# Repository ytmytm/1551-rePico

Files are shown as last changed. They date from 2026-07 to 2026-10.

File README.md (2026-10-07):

# 1551-rePico



Commodore **1551** disk-drive replacement for **Plus/4 / C16 / C116**, based on a [Raspberry Pi Pico 2](https://www.raspberrypi.com/products/raspberry-pi-pico-2/) (RP2350, **non-wireless** — raspberry logo on the soldermask; not Pico 2 W). Firmware and GCR/SD logic are derived from [1541-rePico](https://github.com/fook42/1541-rePico) / [1541-rebuild](https://github.com/ThKattanek/1541-rebuild).

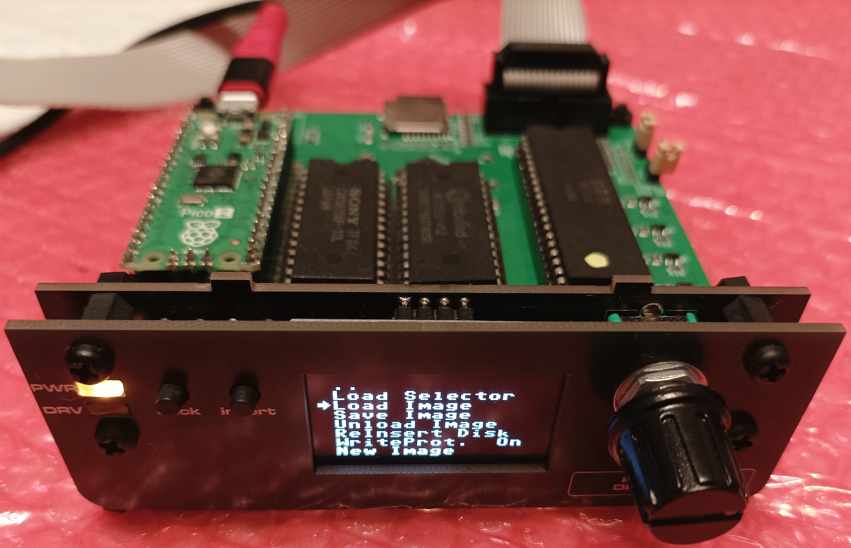
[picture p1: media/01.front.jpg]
1551-rePico front

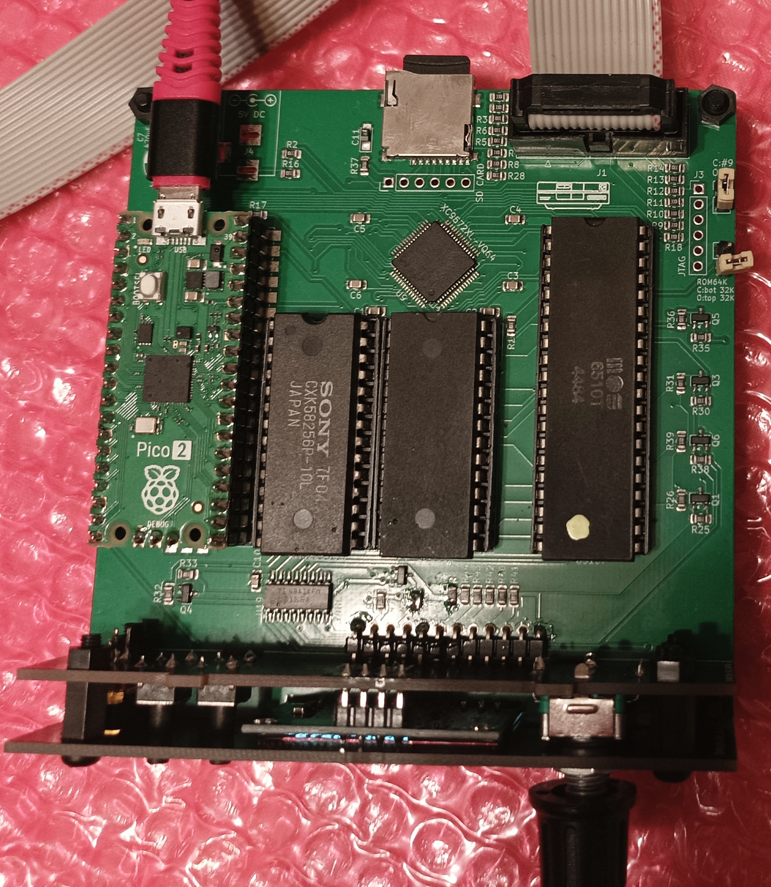
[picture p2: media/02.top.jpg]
1551-rePico top

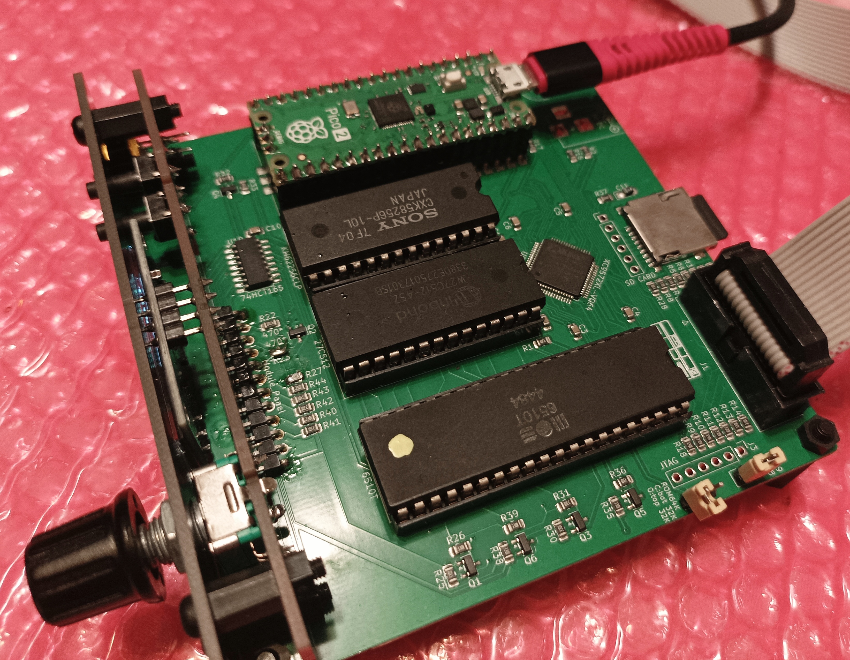
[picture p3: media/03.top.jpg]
1551-rePico topside

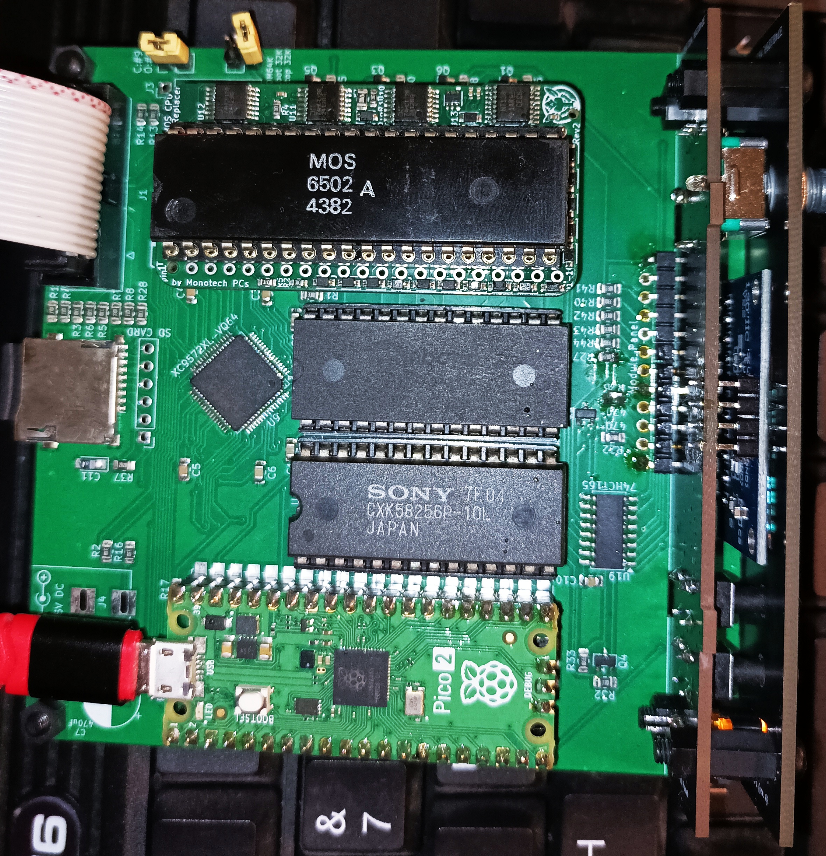
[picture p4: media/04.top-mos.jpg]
1551-rePico topside with MOS CPU Replacer


## What this is

A self-contained **drive computer** — **Pico 2** + **6510T** (or [MOS CPU Replacer](https://github.com/monotech/MOS_CPU_Replacer)) + XC9572XL CPLD + RAM + ROM — that replaces the Pi1551-III mainboard (Raspberry Pi 3 + TCBM). It reuses the Pi1551-III **mechanical stack**: front panel, top/bottom faceplates, and overall assembly. BOM, Gerbers, and build notes for those parts stay in the [Pi1551-III](https://github.com/ytmytm/Pi1551-III) repository.

The finished device connects to the computer through a ribbon cable to **[plus4-tcbm2sd](https://github.com/ytmytm/plus4-tcbm2sd)** — same as Pi1551-III.

In short: same case and front panel as Pi1551-III; this repo supplies the Pico 2 / 6510T mainboard, CPLD bitstream, DOS ROMs, and firmware.

### Repository layout

| Path | Role |
|---|---|
| `firmware-1551-III-pico/` | **Supported** firmware |
| `hardware-1551-III-Pico/` | **Supported** KiCad mainboard |
| `hdl-1551-III/` | **Supported** CPLD (`Fake6523`) |
| `roms/` | **Supported** 1551 DOS images for the 27C512 (see [`roms/README.md`](roms/README.md)) |
| `no-OS-FatFS-SD-SDIO-SPI-RPi-Pico/` | Shared FatFs/SD submodule |
| `tools/` | Optional host helper (`conv_x64` D64↔G64); see [`tools/README.md`](tools/README.md) |
| `experimental/` | **Archival only** — early plug-over-1551 daughterboard + old firmware (see [`experimental/README.md`](experimental/README.md)) |

### Compared to a stock 1551

| Stock 1551 | This board |
|---|---|
| **6510T** CPU | Same **6510T**, or a [MOS CPU Replacer](https://github.com/monotech/MOS_CPU_Replacer) in that socket |
| ~2 KB SRAM | **32 KB** SRAM (`KM62256`) with a **1551-RAMBoard-style** map: `$0000–$3FFF` + `$8000–$9FFF` (extra RAM window; decode in the CPLD) |
| ~16 KB ROM | **64 KB** EPROM (`27C512`): two **32 KB** DOS images, selected by jumper **J2** — burn a [1551-RAMBOard](https://github.com/ytmytm/1551-RAMBOard) 64K image from [`roms/`](roms/) |
| Device #8 / #9 (hardware strap) | Jumper / strap for **device 8 or 9** (same idea as stock) |
| **6523** TPI + discrete address decode | **XC9572XL CPLD** (`hdl-1551-III/` Fake6523): TPI replacement **and** RAM/ROM chip-select decode |
| 2 MHz crystal (Phi0) | **Pico 2** generates **2 MHz Phi0** (PWM) |
| ~100 Hz IRQ oscillator | **Pico 2** generates **100 Hz IRQ** (PWM) |
| Analog floppy + mech | **Pico 2** emulates the analog path and runs the UI |

### Pico 2 on this board

- **Phi0** and **IRQ** as in the table above — those clocks take dedicated GPIOs that a stock gate-array / discrete oscillator would otherwise free up
- Supplies **3.3 V** for the CPLD (and other 3.3 V rails on this board)
- Front-panel **UI**: OLED (I2C), plus rotary encoder, Back/Insert, SD card-detect, and DS0/DS1 via a **74HCT165** (same panel as Pi1551-III). The '165 is needed because after clock, IRQ, floppy bus, SPI SD, and I2C there were not enough GPIOs for every panel line directly
- **SD card**: FatFs images, browser UI, **card-detect hotplug**
- Floppy **datastream**: GCR to/from the “head”, **BYTE_READY** / related timing
- **Stepper**, optional **density** from DS0/DS1, **WPS** / disk-change toward DOS, activity LED

### CPLD role (short)

Bidirectional **ports** (TCBM on A, head data on B, handshake / MODE / DEVNUM / SYNC on C) are based on [ZXByteman/Fake6523](https://github.com/ZXByteman/Fake6523). The same chip is also **logic glue**:

- RAMBOard-style **address decode** (`/RAMSEL`, `/RAMOE`, `/ROMSEL`, TPI `/CS`), all **PHI2-qualified**
- **`XR/~W`** for SRAM `/WE` (qualified with PHI2)
- **`byte_latched`**: Pico 2 strobes `byte_ready_3v3`; the CPLD latches on the falling edge; any CPU access to the TPI window (`$4000–$7FFF`, e.g. DOS `BIT $4000`) clears the latch — the classic floppy byte-ready behaviour from 1541/1571 service docs, without a dedicated 1551 manual

## What you can do with it

- Mount **D64**, **G64**, and **PRG** images from an SD card (PRG is wrapped on the fly into a temporary D64). Format notes: [D64](doc/D64.TXT), [G64](doc/G64.TXT); optional PC conversion with [`tools/conv_x64`](tools/)
- Browse and mount images from the **OLED + encoder** front panel (Back / Insert), with **SD hotplug** when the socket has a card-detect switch
- Run as device **#8 or #9** on the Plus/4 TCBM bus via **[plus4-tcbm2sd](https://github.com/ytmytm/plus4-tcbm2sd)**
- Use **[1551-RAMBOard](https://github.com/ytmytm/1551-RAMBOard)** patched DOS in the 27C512 so track-cache / HypaRAM-style fastloaders work
- Prefer **[Parobek](https://github.com/ytmytm/plus4-parobek)** as the host utility ROM: it autodetects the RAMBOard DOS patch and provides a fastloader. For now we use Parobek’s **DirectoryBrowser** on the computer; `firmware-1551-III-pico/SoftwareC16/db12b.prg` is kept for a future on-device Load Selector (**TODO**)

## Build and assemble

### 1. Clone (with submodules)

The FatFs/SD driver is a **git submodule**. Without it, CMake will fail.

```bash
git clone --recurse-submodules https://github.com/ytmytm/1551-rePico.git
cd 1551-rePico
```

If you already cloned without submodules:

```bash
git submodule update --init --recursive
```

You need at least `no-OS-FatFS-SD-SDIO-SPI-RPi-Pico/` for the supported firmware.

### 2. Host packages

**Linux (Debian-like):**

```bash
sudo apt install cmake ninja-build libusb-1.0-0-dev build-essential \
  pkg-config python3 xxd gcc-arm-none-eabi \
  libnewlib-arm-none-eabi libstdc++-arm-none-eabi-newlib
```

**macOS (Homebrew):**

```bash
brew install cmake ninja libusb pkg-config python3
brew install --cask gcc-arm-embedded
```

`xxd` is usually already on macOS (Xcode Command Line Tools). Ensure `arm-none-eabi-gcc` is on your `PATH`.

### 3. Raspberry Pi Pico SDK

From [pico-sdk](https://github.com/raspberrypi/pico-sdk):

```bash
git clone https://github.com/raspberrypi/pico-sdk.git
cd pico-sdk
git submodule update --init lib/mbedtls
export PICO_SDK_PATH="$(pwd)"
echo "export PICO_SDK_PATH=$PICO_SDK_PATH" >> ~/.profile
```

Open a new shell (or `source ~/.profile`) so `PICO_SDK_PATH` is set. The Raspberry Pi Pico VS Code extension / `.pico-sdk` can provide the SDK instead.

### 4. picotool

From [picotool](https://github.com/raspberrypi/picotool): clone and build/install as in its README / BUILDING.md so `picotool` is on your `PATH`.

### 5. Compile firmware

```bash
cd firmware-1551-III-pico
mkdir -p build && cd build
cmake -G Ninja -DCMAKE_BUILD_TYPE=Release ..
ninja
```

Outputs include `1551-III-Pico.uf2` and `1551-III-Pico.elf`.

### 6. Flash the Pico 2

```bash
picotool load -t uf2 1551-III-Pico.uf2 -x -f
```

`-f` forces BOOTSEL when the app is running; `-x` starts the new firmware after load.

### 7. Main PCB (order / solder)

KiCad project: [`hardware-1551-III-Pico/`](hardware-1551-III-Pico/) (see its [`README.md`](hardware-1551-III-Pico/README.md)).

- Schematic PDF: [`plots/1551-III-Pico.pdf`](hardware-1551-III-Pico/plots/1551-III-Pico.pdf)
- Gerbers / drills: [`plots/`](hardware-1551-III-Pico/plots/)
- Fab pack: [`production/1551-III_Pico_2b.zip`](hardware-1551-III-Pico/production/1551-III_Pico_2b.zip)
- BOM / pick-and-place: [`production/bom.csv`](hardware-1551-III-Pico/production/bom.csv), [`positions.csv`](hardware-1551-III-Pico/production/positions.csv), [`designators.csv`](hardware-1551-III-Pico/production/designators.csv)
- **JP1–JP3**: leave default **1–2** (Pico 2 ↔ `74HCT165`). Alternate wiring was only insurance if the shift register failed — do not change them.

### 8. Program the CPLD

Flash [`hdl-1551-III/Fake6523.jed`](hdl-1551-III/Fake6523.jed) into the XC9572XL. The `.jed` was built with [Xilinx ISE 14.7](https://www.xilinx.com/support/download/index.html/content/xilinx/en/downloadNav/vivado-design-tools/archive-ise.html) (sources in `hdl-1551-III/`). Rebuild and JTAG steps (a Raspberry Pi 3 and jumper wires are enough) are in [plus4-tcbm2sd → CPLD firmware](https://github.com/ytmytm/plus4-tcbm2sd/blob/main/HardwareFirmware.md#cpld-firmware); the procedure is the same for this board.

### 9. Burn the DOS ROM

Program a 64K image from [`roms/`](roms/) into the 27C512 (see [`roms/README.md`](roms/README.md)). Prefer a [1551-RAMBOard](https://github.com/ytmytm/1551-RAMBOard) image; jumper **J2** selects the active 32K half (use the patched upper bank).

### 10. Panel, case, and host link

- Front panel / faceplates / mechanical assembly: **[Pi1551-III](https://github.com/ytmytm/Pi1551-III)**
- Host: **[plus4-tcbm2sd](https://github.com/ytmytm/plus4-tcbm2sd)** + ribbon cable

## History and relation to 1541-rePico

This is a **separate product**, not a fork kept in sync with upstream 1541-rePico: a real **6510T** + CPLD 1551 path in a [Pi1551-III](https://github.com/ytmytm/Pi1551-III) enclosure. Useful upstream changes may still be cherry-picked by hand.

**Starting point.** Take 1541-rePico’s GCR/SD/UI core and aim at a **1551** for Plus/4 that still fits **Pi1551-III** and talks through **tcbm2sd**, so the Pi 3 Module-rotated board becomes a Pico 2 + real 6510T path.

**Daughterboard bring-up** (now `experimental/`). First hardware plugged over a stock 1551 mainboard: reuse CPU/TPI/RAM/ROM, Pico 2 for the analog path, Fake6523 in the CPLD. That proved TCBM/GCR, pin maps, and design rules: Phi0 and 100 Hz IRQ from the Pico 2 (gate array optional), `XR/~W` in the CPLD, PHI2-qualified chip-selects (otherwise RAM bus contention), `byte_latched` as classic byte-ready, and slower zone-0 timing than 1541 defaults. Once the motherboard was only a RAM/ROM carrier, a self-contained board was the next step.

**1551-III-Pico.** Decode moved into the CPLD (no discrete `'139`/`'00`), RAMBOard map and 64K DOS images, Pi1551-III panel (SH1106 + 74HCT165). Firmware lives in `firmware-1551-III-pico/`. Upstream 1541-rePico is not merged as a whole — only occasional hand cherry-picks.

| Mostly from 1541-rePico | Mostly new for 1551 / this board |
|---|---|
| GCR encode/decode, track buffers, D64/G64 path | KiCad III board, CPLD glue + Fake6523 ports, RAMBOard decode |
| FatFs / SD wiring, much of the menu framework | Pico 2 as Phi0 + 100 Hz IRQ; '165 panel inputs |
| Build/flash with pico-sdk / picotool | TCBM via tcbm2sd; Parobek + patched DOS ROMs |
| | Zone-0 timing, byte-ready latch model, SD hotplug, III pinout |

### Credits

- [1541-rebuild](https://github.com/ThKattanek/1541-rebuild) — Thorsten Kattanek  
- [1541-rePico](https://github.com/fook42/1541-rePico) — fook42 (GCR/SD/UI lineage)  
- C64 image selector in upstream 1541-rePico — Peiselulli  
- Dev-container / debug docs on upstream — [BensonRSI](https://github.com/BensonRSI)  
- [Fake6523](https://github.com/ZXByteman/Fake6523) — ZXByteman / go4retro  
- [Pi1551-III](https://github.com/ytmytm/Pi1551-III), [plus4-tcbm2sd](https://github.com/ytmytm/plus4-tcbm2sd), [1551-RAMBOard](https://github.com/ytmytm/1551-RAMBOard), [plus4-parobek](https://github.com/ytmytm/plus4-parobek)

## Links

- Disk image formats overview: <https://ist.uwaterloo.ca/~schepers/formats.html>
- forum64 thread behind 1541-rebuild / 1541-rePico: <https://www.forum64.de/index.php?thread/59884-laufwerk-der-1541-emulieren>

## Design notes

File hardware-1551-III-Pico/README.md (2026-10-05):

# 1551-III-Pico mainboard

KiCad project for the **horizontal main module** of [1551-rePico](../README.md): Pico2 + 6510T (or [MOS CPU Replacer](https://github.com/monotech/MOS_CPU_Replacer)) + XC9572XL CPLD + 32 KB SRAM + 64 KB EPROM. It replaces the Pi1551-III **Module-rotated** board and mates with the [Pi1551-III](https://github.com/ytmytm/Pi1551-III) front panel and faceplates.

Host connection is a ribbon cable to **[plus4-tcbm2sd](https://github.com/ytmytm/plus4-tcbm2sd)** (same as Pi1551-III).

## Design files

| Artifact | Path |
|---|---|
| KiCad project | this folder (`1551-III-Pico.kicad_pro`) |
| Schematic PDF | [`plots/1551-III-Pico.pdf`](plots/1551-III-Pico.pdf) |
| Gerbers / drills | [`plots/`](plots/) |
| JLCPCB-style fab pack | [`production/1551-III_Pico_2b.zip`](production/1551-III_Pico_2b.zip) |
| BOM / positions | [`production/bom.csv`](production/bom.csv), [`production/positions.csv`](production/positions.csv), [`production/designators.csv`](production/designators.csv) |

## Related firmware / CPLD / ROMs

- Firmware: [`../firmware-1551-III-pico/`](../firmware-1551-III-pico/)
- CPLD bitstream: [`../hdl-1551-III/Fake6523.jed`](../hdl-1551-III/Fake6523.jed) — flash notes in the [top-level README](../README.md#8-program-the-cpld)
- DOS EPROM images (27C512): [`../roms/`](../roms/) — see [1551-RAMBOard](https://github.com/ytmytm/1551-RAMBOard) for provenance and patch details
- Mechanical / panel BOM: **[Pi1551-III](https://github.com/ytmytm/Pi1551-III)**

## Notes

- Internal bring-up / review notes: [`notes.txt`](notes.txt), [`hardware-review.md`](hardware-review.md)
- ROM bank select on this board is jumper **J2** (two 32 KB halves of the 27C512). Prefer a [1551-RAMBOard](https://github.com/ytmytm/1551-RAMBOard) 64K image so the upper half is the RAM-expansion / fastloader patch.
- **JP1–JP3** (GPIO26–28 ↔ `74HCT165`): leave as shipped / default **1–2**. They were only a fallback so the Pico could talk to the front-panel encoder directly if the shift register failed; '165 works and current firmware expects that path — do not rewire them.

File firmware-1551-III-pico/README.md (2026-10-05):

# firmware-1551-III-pico

**Supported** firmware for the 1551-III-Pico board (Pico2 + front panel + SD + GCR).

Build, flash, and product overview: see the [top-level README](../README.md#build-and-assemble).

Host-side Load Selector / Parobek notes: [What you can do with it](../README.md#what-you-can-do-with-it). Plus/4 browser binary kept here: `SoftwareC16/db12b.prg`.

Archival 1541 / early daughterboard firmware is under [`../experimental/firmware/`](../experimental/firmware/), not this tree.

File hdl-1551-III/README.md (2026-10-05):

# hdl-1551-III

Xilinx ISE project and bitstream for the **XC9572XL** on the 1551-III-Pico board (`Fake6523.jed`).

What the CPLD does (TPI ports, RAM/ROM decode, `byte_latched`): [CPLD role](../README.md#cpld-role-short). How to rebuild and JTAG-flash: [Program the CPLD](../README.md#8-program-the-cpld).

Sources are based on [ZXByteman/Fake6523](https://github.com/ZXByteman/Fake6523). The older daughterboard CPLD tree is under [`../experimental/hdl/`](../experimental/hdl/).

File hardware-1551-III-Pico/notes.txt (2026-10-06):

Mini-Din-7 https://forum.kicad.info/t/mini-din-connectors-their-footprints-and-3-d-models-asking-for-discussion-and-a-bit-of-help-discussion/58247/11

6502 computers:
https://wilsonminesco.com/6502primer/potpourri.html

https://coronax.wordpress.com/2024/01/24/adding-io-ports-to-a-6502-computer-using-7400-series-ics/

https://github.com/maarten-pennings/6502/tree/master/1clock

RAM /WE is always R/W combined with Phi2

https://github.com/maarten-pennings/6502/blob/master/4ram/README.md

https://www.grappendorf.net/projects/6502-home-computer/

Something completely different:
https://eaw.app/pico6502/

[20260714]
Put together daughterboard, but no success yet.
The CPU might be running or might be faulty, not sure yet.
Some lines display expected pattern, so it might be ok.
But there is no response to TCBM.
We don't even know if the port is accessible to CPU.
Should we use R/W + Phi2 instead of XR/W+Phi0? We don't know.
We might test it with repico using debug firmware and debug ROM, but it will have to wait.
Pico generates 2MHz on GPIO0 and 100Hz with 10us low on GPIO3, same as onboard circuit, that should be fine (unless we use inverting buffer).
- uncomment /* #define REPICO1551_GPIO3_IRQ_PWM */ in include/board1551.h to enble PWM back

Flash firmware (switches ot bootsel on its own):
picotool load "/Users/apple/Documents/Batibat/Maciejdev/plus4/pico1551/1551-rePico/firmware-1551-III-pico/build/1551-III-Pico.uf2" -f

Next steps:
- if CPU can't write to TPI ports we can check if using phi2+r/w would help here
    (in fact we can start with it? could be faster check than custom ROM)
    - maybe it should just write 0 and use hi-z instead of 1?
- we don't use WPS (write protect) as input, nor ACT (LED) as output on 1551-III
  daughterboard alone — but on the main 1551 board ACT LED and WPS are available

[20260715]
Did some checks with custom ROMs to conclude:
- CPU most likely works fine
- CPU port state unknown (no conclusive tests)
- TCBM port works, we can read/write data from 1551 coming to computer
- TCBM port is not reliable, seems that DDR writes sometimes fail
    - wrong value is stored, so some bits remain in wrong direction leading to stuck bits
- SRAM seems to be bad
    - that explains weird IRQ behavior and failure of CPU ports (RAM was used to hold state)

Next steps:
- desolder SRAM
- solder 24pin socket
- put a replacement:
    - after https://github.com/ytmytm/c128-bytewide-color-ram-1571cr-expansion
      I have 2 2K SRAM chips

[20260716]
Everything works. Debug ROM / REPICO_DEBUG bring-up target removed.
SRAM didn't have to be removed - just reseating CPU was enough.
Locked CPU/TPI pins positions, they were perfectly aligned.

[20260717]
- improved rotary encoder
- disconnected BYTE_LATCHED from mainboard
- optimizations to speed up main loop (drop sleep_us(3) BYTE_READY on 1551;
  set PA direction only on SO mode change)

[20260718]
- problems with zone 0 (tracks 1-17) seem to be solved (hopefully we don't break anything else)
  - timer set to 28µs and gap 21 instead of 26/12
  Doc: doc/1551-zone0-gcr-timing.md
- UI / UIX improvements
- options in settings to control zone0 (Z0) timer/gap for experiments
- reversible encoder direction
- confirmed that IRQ 100Hz/10µs from GPIO3 PWM works fine
- no need for reset circuit for 1551-III-Pico, it's driven by tcbm2sd
- LED connected, P5 pins 8 (+5V) and 9 (ACT), activity when loading, not during reset
- drop use of gate array's XR/W, generate it on (former RESET_3V3 pin) in CPLD, expose for RAM
- confirmed that RAM works on /WE generated from CPLD (from former RESET_3V3 pin)
- switched Phi0 to come from Pico and that blew up(?) GA? there is no onboard 2MHz anymore
  (or it could be unfortunate conincidence - Pico didn't want to start several times, maybe something shorted and blew GA?)
  (U7 GA is probably broken, no 2MHz clock, we don't need it though)
- desoldered U7 GA and connected like below to 74'139
- 1551 motherboard used only as carrier for RAM and ROM
- pico1551 can be recreated
- AI claims that if we switch in CPLD rs (address) from register to input
  we might save just enough gates to generate RAM/ROM/TPI chip-select signals
  *also* with 1551-RAMBOard setup ($00-$3f RAM, $40-$7F TPI, $80-$9F RAM, $A0-$FF ROM)
  need A13-A15 on input and /RAMSEL, /ROMSEL on output

remove U7 and wire 74'139
U7      '139    signal
4       16      VCC, also to 15,14,13
        15      /E2 (keep input high)
6       3       A15
7       2       A14
20      4       /RAM
14      7       /ROM
16      5       /TPI
5       1       /E1, GND also to 8
        8       GND
        13      VCC (keep input high)
        14      VCC (keep input high)

or directly:

74LS139 (DIP-16)
================

 pin | signal   | connect
-----+----------+----------------
  1  | 1G (/E1) | GND
  2  | 1A       | CPU A14   (21)
  3  | 1B       | CPU A15   (22)
  4  | 1Y0      | /CS_RAM   (18+20 shorted)
  5  | 1Y1      | /CS_TPI   (18)
  6  | 1Y2      | NC
  7  | 1Y3      | /CS_ROM   (22, 20 tied to GND)
  8  | GND      | GND
  9  | 2Y0      | NC
 10  | 2Y1      | NC
 11  | 2Y2      | NC
 12  | 2Y3      | NC
 13  | 2A       | VCC
 14  | 2B       | VCC
 15  | 2G (/E2) | VCC
 16  | VCC      | VCC

Pico1551-III readiness:
confirm that UI would work with Pi1551-III front panel connected
    - act will be inverted (active low)
    - need correct OLED type driver

[2026-08-23]
Soldered Pico1551-III prototype. It doesn't work (would be surprised if it does).
There is some kind of RAM problem - with RAM chip inserted there seems to be bus
contention. Without RAM we get blinking activity LED.
Almost forgot that ROM needs to be 2*32K images coming from 1551-RAMBOard.
Spent whole evening chasing the problem. The solution turned out to be to qualify
all chip select signals with Phi2.

So the next step is confirm again that it works and then we can test shift register
with the front panel.

[2026-08-24]
It works, so I have mounted the front panel.
Agent implemented SH1106 OLED support (it was SSD1306) and shift register handler.
Density chosen by CPU (via DS0/DS0 lines) is an option, currently off - track density hardcoded by track number.
'Back' button is universal back and 'Insert' goes to load image menu and adds disk images to the roster.

Needs testing + decision what to do with SD switch info - some kind of reload?

[2026-08-31]
Experimental firmware branch feature/core-split-ui-gcr: UI + 74HCT165 input on core 1,
GCR byte feed + stepper/floppy GPIO on core 0. Inter-core lock-free SPSC mailboxes
(ipc.h/ipc.c) for timer, WPS, disk change, and shift165 density byte — aims to
reduce GCR jitter vs single-core main loop. Not merged; flash from that branch to test.

Added WPS triggering on disk change, but GEOS doesn't recognize that 1B is different than
1A or 2A. Only Close+Open in Desktop refreshes that. Strange.

Removed zone0 settings, we don't need it anymore. Brought back values from 1541 upstream.

[2026-09-01]
Tested on stock Plus/4. Demos (biffire: Carrion 121, qm_prepl; hypaload: vdc, carrion)
do work without issues - it's all about 6502/Plus4 faulty Hannes and 65C02 there.
No need to go back to 1551 mainboard.

Can be published and released.

[2026-09-12]
Confirmed dim ACT LED fix for the 1.0 board:
- remove R27 (3.3K)
- move R23 to R27 footprint (470R)
- short R23 pads (0R)

Applied in KiCad, regenerated files for v1.1 (revison 2b on SCH/PCB).

[2026-10-02]
Confirmed that it works with MOS CPU Replacer configured for 6510T both electrically
and mechanically.
https://github.com/monotech/MOS_CPU_Replacer

[2026-10-03]
Added support for SD card switch and hot swapping SD cards.
Preparations for publishing, repository cleanup.

[2026-10-05]
Added some photos, also to the experimental folder.

TODO:
- disk image is not saved automatically
- when disk is saved it doesn't replace the original one
- UI is somewhat inconsistent (longpress not needed with front planel)
  but with menus still better than Pi1551
- 16x8 is plenty of space, most of it unused outside menu
- still don't understand why disk switch from GEOS's disks
  1A->1B or 2A->1B are not recognized by 1A->2A is
- README needs user's manual - encoder actions (longpress too)
  insert/back buttons as well

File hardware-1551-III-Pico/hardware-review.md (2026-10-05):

# Review hardware-1551-III-Pico

Data review: 2026-08-13

Zakres: tylko projekt `hardware-1551-III-Pico`, z porownaniem do `hdl-1551-III/Fake6523.v`, `hdl-1551-III/Fake6523.ucf`, `hdl-1551-III/Fake6523.rpt`, `hardware-1551-III-Pico/notes.txt` i `doc/1551-rom-ram-ramboard-decode.txt`.

## Wniosek ogolny

Schemat po przeniesieniu dekodera adresu do CPLD wyglada spojnie. `U12 74LS139` i `U15 74LS00` zostaly usuniete, stare nety dekodera nie wystepuja juz w schemacie ani PCB, a nety KiCada zgadzaja sie z pinoutem HDL/UCF.

Nie widze blokera logicznego, ktory jednoznacznie zatrzymywalby testowa produkcje plytki. Do zamkniecia przed wyslaniem zostaje jedna rzecz produkcyjna: pola BOM/JLC dla `U19`, bo schemat chce `74HCT165`, a pola produkcyjne nadal wskazuja wariant LS.

Fit `hdl-1551-III` przeszedl dla wariantu z osobnym `/RAMOE`, ale CPLD jest wypelniony do konca:

```text
Macrocells:     72/72  (100%)
Product Terms: 206/360 (57%)
FB inputs:     136/216 (63%)
Registers:      58/72  (81%)
Pins:           47/52  (90%)
```

Nie dokladac juz logiki do XC9572XL w tej rewizji bez swiadomego usuwania czegos innego.

Ostrzezenia fittera sa znane i nie wygladaja na nowy problem po dodaniu dekodera: dotycza inferowanych/zignorowanych `BUFG` na pinach `port_a<5..7>` oraz sciezki projektu ISE. Nie ma bledow fitowania.

## Dekoder W CPLD

Aktualne znaczenie sygnalow:

```text
/RAMSEL = RAM /CS, zalezy tylko od adresu
/RAMOE  = RAM /OE, aktywne tylko gdy RAM jest wybrany i CPU czyta
XR/~W   = ogolny /WE, aktywne przy R/W=0 i PHI2=1
/ROMSEL = ROM /CE i /OE, zalezy tylko od adresu ROM
```

Rownania po fitterze:

```text
/RAMSEL = A14 OR (A15 AND A13)
/RAMOE  = NOT ((NOT A14 AND NOT A15 AND R/W) OR (NOT A14 AND NOT A13 AND R/W))
/ROMSEL = NOT A15 OR (NOT A14 AND NOT A13)
TPI /CS wewnetrznie = NOT (A14 AND NOT A15)
```

Mapa adresow:

```text
$0000-$3fff = RAM
$4000-$7fff = TPI
$8000-$9fff = dodatkowy RAM
$a000-$ffff = ROM
```

## Weryfikacja Netow KiCad

Sprawdzone w `1551-III-Pico.kicad_sch` i `1551-III-Pico.kicad_pcb`:

```text
U9 P39 = A14
U9 P42 = /RAMOE
U9 P58 = /RAMSEL
U9 P59 = /ROMSEL
U9 P61 = A13
U9 P62 = A15
U4 pin 20 /CS = /RAMSEL
U4 pin 22 /OE = /RAMOE
U4 pin 27 /WE = XR/~W
U5 pin 20 /CE = /ROMSEL
U5 pin 22 /OE = /ROMSEL
U6 CPU A13/A14/A15 sa na tych samych netach A13/A14/A15
```

Nie znaleziono juz w schemacie ani PCB: `U12`, `U15`, `74LS139`, `74LS00`, `~{CS_TPI}`, `~{RAM_LOW}`, `~{RAM_HIGH}`, `~{ROM_LOW}`, `~{ROM_HIGH}`, `~{E2}`.

Dodany test/symulator:

```text
python3 hardware-1551-III-Pico/test_hardware_model.py
```

Test sprawdza model dekodera adresu dla calego zakresu `$0000-$ffff`, brak konfliktu driverow na magistrali danych przy odczycie, kwalifikowanie `/RAMOE` i `XR/~W`, kolejnosc bitow z `U19 74HCT165`, krytyczne piny KiCada kontra HDL/UCF oraz wybrane pullupy/wejscia stale.

## Audyt CPU/RAM/ROM

CPU `U6 6510T`: adresy, dane, `R/W`, `PHI0`, `PHI2`, `/RESET`, `/IRQ`, `/AEC` i portowe linie 1551 sa podlaczone; `/RESET`, `/IRQ` i `/AEC` maja pullupy.

SRAM `U4 KM62256CLP`: adresowanie jest zgodne z planem RAMBoard:

```text
RAM A0..A13 = CPU A0..A13
RAM A14     = CPU A15
RAM D0..D7  = CPU D0..D7
```

Sterowanie SRAM:

```text
pin 20 /CS = /RAMSEL
pin 22 /OE = /RAMOE
pin 27 /WE = XR/~W
```

EPROM `U5 27C512`: adresy i dane sa kompletne, `ROM A15` jest ustawiany przez `J2 + R1 3.3K do +5V`, a `/CE` i `/OE` ida na `/ROMSEL`. Nie widze wiszacych wejsc przy RAM/ROM.

## Audyt CPLD/TPI/TCBM

`U9 XC9572XL` jest zasilany z `+3V3`, ma podlaczone wszystkie piny z UCF i poprawnie wykorzystuje `~{RESET}` jako GSR. Niepodlaczone piny CPLD `P8`, `P18`, `P23`, `P51` sa oznaczone jako no-connect i fitter pokazuje je jako `TIE`, wiec nie wygladaja jak przypadkowo wiszace uzywane wejscia.

Linie TCBM `DIO1..DIO8`, `STATUS0`, `STATUS1`, `DEV`, `DAV`, `ACK` ida do CPLD zgodnie z UCF. Pullupy TCBM ida do `+3V3`, co pasuje do pracy CPLD na 3.3 V i do jego 5 V tolerant wejsc.

Warto pamietac, ze `byte_latched` jest generowane z asynchronicznego `byte_ready_3v3` i wewnetrznego `/CS`; to jest istniejacy model z eksperymentu. Nie znalazlem tu nowego bledu schematowego, ale to pozostaje punkt bring-up firmware/HDL, nie ERC.

## Audyt Pico I Shift Register

`U3 Pico` ma `VSYS` podlaczone do `+5V`, `3V3` zasila logike 3.3 V, a `VBUS`, `RUN`, `3V3_EN`, `ADC_VREF`, `SWCLK`, `SWDIO` sa swiadomie no-connect. To jest akceptowalne dla modulu uruchamianego przez USB/BOOTSEL i bez osobnego debug SWD na plytce.

`U19 74HCT165`: `/PL = SERIAL_LOAD`, `CP = SERIAL_CLK`, `Q7 = SERIAL_DT`, `DS = GND`, `/CE = GND`, `VCC = +5V`, `GND = GND`, a `/Q7` jest no-connect. Wejscia panelowe i SD-card-detect maja pullupy do `+3V3`; `DS0/DS1` sa czytane z portu CPU i nie wymagaja tu osobnych pullupow jesli CPU je aktywnie steruje.

Uwaga produkcyjna: symbol/wartosc mowi `74HCT165`, ale pola JLC/MFR w schemacie i PCB nadal wskazuja `SN74LS165ADR(LX)` / `C42403065`. Jesli faktycznie ma byc HCT, trzeba poprawic pola BOM/JLC przed assembly. Jesli swiadomie dopuszczasz LS, dopisz to w BOM, bo obecna notatka na schemacie mowi, ze "musi byc HCT".

## Zasilanie I Montaz

`+5V` zasila CPU/RAM/ROM/U19 i `VSYS` Pico, `+3V3` zasila CPLD, pullupy 3.3 V i peryferia Pico. Kondensatory 100 nF sa przy glownych ukladach (`C1..C6`, `C10`), a przy SD jest dodatkowy `C11 10u`. Nie robilem analizy impedancji ani rozmieszczenia przy pinach zasilania, tylko sprawdzenie netlisty.

`README.md` w katalogu projektu opisuje juz rewizje Pico (KiCad / plots / production / ROM); nie jest juz starym tekstem Pi1551-III Module-rotated.

`JP1..JP3` (solder jumpers GPIO26..28): domyslnie mostkowane **1–2** do `74HCT165` (`/PL`, `CP`, `Q7`). Alternatywna sciezka na schemacie (bezposrednio do enkodera) byla tylko ubezpieczeniem na wypadek problemow z '165; shift register dziala, firmware zaklada tryb 1–2 — **zostawic JP1–JP3 bez zmian**.

## Otwarte

- [x] Nałozyc overlay warstwy Edge.Cuts z MOSReplacer - miec pewnosc ze sie zmiesci nad footprint 6510T
      potrzeba 6.5mm z lewej i 10.54mm z prawej (moze byc nad ROM/RAM, ale nie nad RPIco)
- [x] Porownac z tcbm2sd jak daleko poza krawedz wystaje gniazdo SD card
- [x] Uruchomic ERC/DRC w KiCadzie lokalnie; `kicad-cli` nie jest dostepny w tym srodowisku.
- [x] Sprawdzic pola BOM/JLC dla `U19`: HCT zgodnie ze schematem/notatka albo swiadomie LS i opisane w BOM. Aktualnie nadal `SN74LS165ADR(LX)` / `C42403065`. (LS/HCT bez roznicy)
- [x] Przejrzec wygenerowany BOM/position files po ostatnich zmianach, szczegolnie usuniecie `U12/U15` i dodanie netow CPLD `/RAMSEL`, `/RAMOE`, `/ROMSEL`.
- [x] Dodac i uruchomic test/symulator `hardware-1551-III-Pico/test_hardware_model.py`.
- [x] Dopisac w firmware obsluge `74HCT165`.
- [x] Opisac `JP1..JP3`: default 1–2 do '165; fallback na enkoder tylko jako ubezpieczenie — nie ruszac (README projektu KiCad).
- [x] Uaktualnic `hardware-1551-III-Pico/README.md` dla tej rewizji (BOM/plots/production + notka JP1–JP3).

[2026-08-31]
Too dim ACT LED:
- remove R27 (3.3K)
- move R23 to R27 footprint (470R)
- short R23 pads (0R)
Should be much brighter, comparable to PWR

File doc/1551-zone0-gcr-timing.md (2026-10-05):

# 1551-rePico: zone 0 GCR timing (tracks 1–17)

**Status:** confirmed 2026-07-18 — keep both tweaks for `REPICO1551` builds.  
**Code:** `firmware-1551-III-pico/src/globals.c` (`bytetimer_values`, `d64_sector_gap`), gated on `#if REPICO1551` (same values live in the archival `experimental/firmware/` tree).

## Summary

Stock 1551 DOS (and some fastloaders) failed on densest tracks (speed zone 0, tracks 1–17) with the original 1541-rePico packing: **26 µs/byte** and **12** GCR gap bytes between sectors. Typical symptom: `23, READ ERROR, track, sector` (data-block checksum) while the directory on track 18 (zone 1) still worked.

**Keep for 1551:** zone 0 at **28 µs/byte** and sector gap **21** (same as zone 1).  
**1541 builds** stay at the original **26 µs / gap 12** until proven otherwise.

Offline D64→GCR encode/decode of failing sectors was correct; the issue is live capture timing (header → short gap → data), not corrupt image bytes.

## A/B results (REPICO1551)

| Config | Zone 0 timer | Zone 0 gap | Result |
|---|---|---|---|
| Original | 26 µs | 12 | `LOAD "GEOS 3*"` → `23, READ ERROR, 11,17`; Carrion fastloader on tracks 1–8 still OK |
| Gap only | 26 µs | 21 | First GEOS load OK; later GEOS stages failed |
| Timer only | 28 µs | 12 | GEOS OK; **hypaload** and **qm_…** demos failed |
| **Both (keep)** | **28 µs** | **21** | Reliable — GEOS, hypaload, qm_ demos all pass |

Also useful contrast: Carrion starts on track 18 then fastloads zone 0 successfully with original timing — fastloaders can tolerate packing that stock DOS rejects.

## Emulation tradeoff

Zone 0 no longer matches a real drive’s fastest density band:

- Byte period matches zone 1 (28 µs).
- Inter-sector gaps match zone 1 (21 × `0x55`).
- Revolution time on tracks 1–17 is slightly longer than ~200 ms real (~220 ms with both tweaks).

GCR payload and checksums remain correct. Risk is mainly timing-sensitive protections or loaders that assume authentic zone-0 bitrate/RPM; none of the titles above required reverting.

## Related ISR notes (1551)

Separate from gap/timer, also done for 1551 bring-up:

- No `sleep_us(3)` on `BYTE_READY` pulse (CPLD latches on falling edge).
- PA bus direction set only on SO read/write mode change, not every byte.

See `hardware-1551-III-Pico/notes.txt` for session log.

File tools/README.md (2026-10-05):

# conv_x64

Small host tool to convert between D64 and G64 image formats (round-trip through the same GCR structures the firmware uses).

## Main purpose

Originally for testing read/write paths in [1541-rePico](https://github.com/fook42/1541-rePico). Still useful here for checking D64/G64 images before putting them on an SD card for **1551-III-Pico** — the GCR layer is shared.

The supported product firmware lives in `../firmware-1551-III-pico/`; this tool is optional and not required to build or flash the drive.

## Usage

```text
conv_x64 <file_in> <file_out>
```

Extension of `file_in` (`.d64` or `.g64`) selects the reader; extension of `file_out` selects the writer.

## How to build

```bash
gcc -fcommon -o conv_x64 conv_x64.c gcr.c rw_tracks.c
```

Ignore the type-conversion warnings.

2026/02/14 - fook42

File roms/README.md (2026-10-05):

# 1551 DOS ROM images

Burn a **64 KB** image into the board’s **27C512 / 27E512** (socket U5). Jumper **J2** selects which 32 KB half is mapped.

These files are the same deliverables documented by **[1551-RAMBOard](https://github.com/ytmytm/1551-RAMBOard)** (RAM/ROM expansion map used on this board: `$0000–$3FFF` + `$8000–$9FFF` RAM, `$A000–$FFFF` ROM). Prefer the patched upper bank together with **[Parobek](https://github.com/ytmytm/plus4-parobek)** for the HypaRAM / track-cache fastloader.

## What to program (recommended)

| File | Size | Use |
|---|---|-----|
| [`1551.318008-01-64k.bin`](1551.318008-01-64k.bin) | 64K | Stock 1551 DOS (318008-01): lower half = unpatched base, upper half = RAMBOard patch |
| [`super_dos_1551-64k.bin`](super_dos_1551-64k.bin) | 64K | SuperDOS (40-track) + same RAMBOard patch in the upper half |

Leave **J2** so the **upper** (patched) half is selected for normal use. Details: [1551-RAMBOard README](https://github.com/ytmytm/1551-RAMBOard).

## 32K / 16K copies (same payloads, shorter names)

Copied from a Pi1551 SD card tree; byte-identical to the RAMBOard outputs under the names used there:

| File | Size | Same as |
|---|---|---|
| [`dos1551-ram.bin`](dos1551-ram.bin) | 32K | `1551.318008-01-patched.bin` (upper half of the 64K stock image) |
| [`1551.318008-01-patched.bin`](1551.318008-01-patched.bin) | 32K | RAMBOard patched stock DOS |
| [`super_dos_ram.bin`](super_dos_ram.bin) | 32K | `super_dos_1551-patched.bin` |
| [`super_dos_1551-patched.bin`](super_dos_1551-patched.bin) | 32K | RAMBOard patched SuperDOS |
| [`dos1551.bin`](dos1551.bin) | 16K | Stock 1551 DOS base ([zimmers.net 318008-01](https://www.zimmers.net/anonftp/pub/cbm/firmware/drives/new/1551/1551.318008-01.bin)) |
| [`super_dos_1551.rom`](super_dos_1551.rom) | 16K | SuperDOS 1551 ([plus4world](https://plus4world.powweb.com/dl/utils/s/super_dos_1551.rom)) |

## Provenance

- Patch / 64K packing / build steps: [ytmytm/1551-RAMBOard](https://github.com/ytmytm/1551-RAMBOard)
- Stock 1551 ROM: Commodore 318008-01 (via zimmers.net, as linked from RAMBOard)
- SuperDOS: plus4world `super_dos_1551.rom` (as linked from RAMBOard)
- Local copies of the shorter names came from a Pi1551 `sdcard/` tree; the `*-64k.bin` / `*-patched.bin` files match the RAMBOard First Bank build outputs

Rebuild yourself with the RAMBOard `Makefile` / Releases if you need a fresh binary.

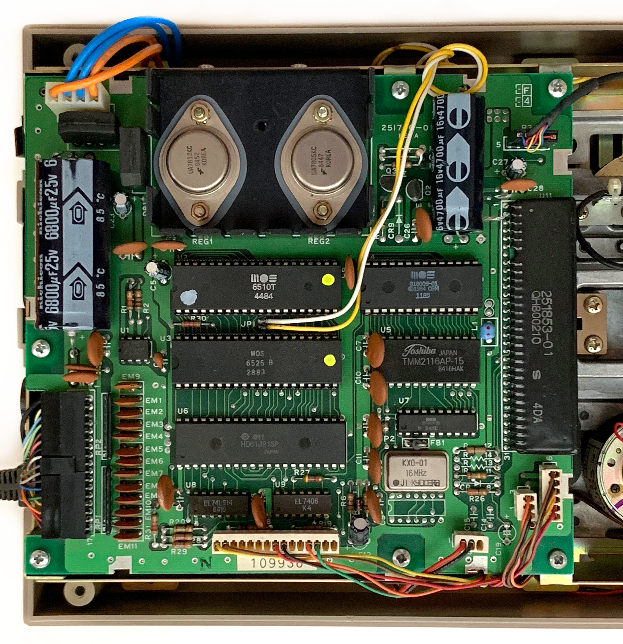
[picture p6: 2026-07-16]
experimental/hardware1551/1551_board.jpg

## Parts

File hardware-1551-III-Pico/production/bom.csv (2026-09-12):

Designator | Footprint | Quantity | Value | LCSC Part #
C1, C10, C2, C3, C4, C5, C6 | 0805 | 7 | 0.1uF | C49678
C11 | CP_EIA-3216-12_Kemet-S_HandSolder | 1 | 10µ | C1969735
Q1, Q2, Q3, Q4, Q5, Q6 | SOT-23 | 6 | BSS138 | C78284
R1, R10, R11, R12, R13, R14, R15, R16, R17, R18, R19, R2, R20, R21, R25, R26, R28, R3, R30, R31, R32, R33, R35, R36, R38, R39, R4, R40, R41, R42, R43, R44, R5, R6, R7, R8, R9 | 0805 | 37 | 3.3K | C26010
R22, R27 | 0805 | 2 | 470* | C17710
R37 | 0805 | 1 | 2.2R | C17521
U19 | SOP-16_4.4x10.4mm_P1.27mm | 1 | 74LS165 | C7742
U9 | TQFP-64_10x10mm_P0.5mm | 1 | XC9572XL-VQ64 | C90569
XS1 | Conn_uSDcard | 1 | SD connector | C7529389

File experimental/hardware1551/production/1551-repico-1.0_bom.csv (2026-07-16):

Designator | Footprint | Quantity | Value | LCSC Part #
C2, C3, C4, C5 | 0805 | 4 | 0.1uF | C49678
Q1, Q2, Q3, Q4 | SOT-23 | 4 | BSS138 | C78284
R1, R10, R11, R12, R13, R14, R2, R3, R4, R5, R6, R7, R8, R9 | 0805 | 14 | 10k | C22356686
U3 | TQFP-64_10x10mm_P0.5mm | 1 | XC9572XL-VQ64 | C90569

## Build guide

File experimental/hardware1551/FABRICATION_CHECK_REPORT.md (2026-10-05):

# 1551-rePico Remaining Work Before Bring-Up

Date: 2026-07-03

This file now lists only the remaining or intentionally deferred items. Confirmed/done fabrication checks were removed to keep the report usable.

## Hardware/CPLD Before Programming

1. Rebuild/refit `Fake6523.jed`.
   - The old fitted artifacts used `soe_3v3` on `U3 P18`, while this PCB leaves `P18` unconnected.
   - Keep `Fake6523.v`, `Fake6523.ucf`, fitter output, and the final `.jed` together as the known-good programmed set.
   - Re-check byte-latch behavior after the new fit, especially `BYTE_READY_3V3`, `BYTE_LATCHED`, and `/~{CS_TPI}` clear timing.

2. Decide whether the future CPLD mode will use real CPU timing.
   - Current design uses gate-array `/XR{slash}~{W}` on `_write`.
   - `/R{slash}~{W}`, `/PHI2`, and `/PHI0` are already routed to CPLD pins for possible later use.

3. Keep the new experiment jumpers in their default positions for normal bring-up.
   - `JP2` default: board `PHI0_BRD` feeds the active `/PHI0` net.
   - `JP5`/`JP6` default: Pico `GPIO3` drives `/DEVNUM_3V3`, and board `/~{IRQ_BRD}` feeds `/~{IRQ}`.
   - `JP7` default ties the alternate DEVNUM source to `GND`, but it is isolated while `JP5` is in the default position.

## Firmware TODO

1. Update Pico firmware for the 1551 pin map.
   - `GPIO0`: normally isolated by `JP2`; can be switched in later to test a Pico-generated 2 MHz `PHI0`.
   - `GPIO1`: `/MODE_3V3`
   - `GPIO2`: `/SYNC_3V3`
   - `GPIO3`: normally `/DEVNUM_3V3` (static **low** = device #8 / Plus/4 `FEE0`–`FEF7`); optional 100 Hz IRQ PWM via `#define REPICO1551_GPIO3_IRQ_PWM` in `experimental/firmware/include/board1551.h` **only** after swapping both `JP5` and `JP6`.
   - `GPIO4`: `/MTR_3V3`
   - `GPIO5`: `/WPS_3V3`
   - `GPIO6`: `/STP0_3V3`
   - `GPIO7`: `/STP1_3V3`
   - `GPIO8..15`: `/YB0..YB7`
   - `GPIO16..19`: SD card SPI
   - `GPIO20..21`: I2C
   - `GPIO22`: `/BYTE_READY_3V3`
   - `GPIO26..28`: rotary encoder

2. Treat BSS138-translated lines as open-drain style GPIO.
   - Affected nets: `/MTR_3V3`, `/STP0_3V3`, `/STP1_3V3`, `/WPS_3V3`.
   - Assert low by driving output low.
   - Deassert by switching the GPIO to input/high-Z and letting the pullups work.
   - Do not drive these lines push-pull high.

3. Avoid Pico/CPLD bus contention.
   - Shared nets include `/YB0..YB7`, `/MODE_3V3`, `/SYNC_3V3`, `/DEVNUM_3V3`, and `/BYTE_READY_3V3`.
   - Firmware must know when the CPLD side is driving and when it is high-Z.

4. Document and implement the byte handshake.
   - `BYTE_READY_3V3` is the Pico-side strobe.
   - `BYTE_LATCHED` goes to the gate array.
   - `/~{CS_TPI}` clears `BYTE_LATCHED`; this means any CPU access to the TPI I/O address space clears the latch.
   - The 1541/1571 service manuals are still relevant here: they document the gate-array byte-ready/SOE behavior and the reused ATN-related latch behavior, even though there is no dedicated 1551 service manual in the repo.
   - Re-confirm exact behavior after rebuilding the CPLD.

5. **Zone 0 GCR timing (firmware, confirmed):** stock DOS/GEOS need slower zone-0 byte timer (28 µs) and larger sector gaps (21) on 1551-rePico. Full A/B notes and rationale: [doc/1551-zone0-gcr-timing.md](../../doc/1551-zone0-gcr-timing.md). Do not “restore” 26 µs / gap 12 for `REPICO1551` without retesting GEOS, hypaload, and qm_ demos.

6. Decide reset handling.
   - CPLD passes `/~{RESET}` to `/~{RESET_3V3}`.
   - Pico `RUN` only follows that reset if `JP1` is bridged.

7. Document the IRQ/PHI0 experiment jumper modes.
   - `JP2` is a 3-way solder jumper for `PHI0`: default `A-C` connects `PHI0_BRD` to `/PHI0`; experiment `B-C` connects Pico `GPIO0` to `/PHI0` instead.
   - `JP5` and `JP6` must be changed together for the IRQ experiment. Default keeps `GPIO3 -> /DEVNUM_3V3` and `/~{IRQ_BRD} -> /~{IRQ}`. Swapped mode connects `GPIO3 -> /~{IRQ}` and lets `JP7` set `/DEVNUM_3V3`.
   - `JP7` selects the fixed device number only when `JP5` is in swapped mode: default `GND` is device #8; switched `+3V3` is device #9.
   - Avoid partial jumper swaps: changing only one of `JP5` or `JP6` can leave either IRQ or DEVNUM disconnected from the intended source.
   - When changing any 3-way jumper, cut the default `A-C` bridge before adding the `B-C` bridge. Leaving both bridges closed can short two signal sources together.
   - Before testing Pico-generated `PHI0`, verify the programmed CPLD leaves `U3 P31` as input/high-Z. The old fitted output marks `P31` as unused/tied, but the final JED should be checked before driving `/PHI0` from `GPIO0`.

## Reference Notes To Keep

- TCBM connector naming is intentionally preserved for the adapter: `/DAV` is on `J10` pin 11 and `/ACK` is on `J10` pin 13.
- Board-side `YB*`, `MODE`, `DEVNUM_BRD`, `SYNC`, `DS0`, and `DS1` are intentionally not connected to the active Pico-side nets.
- Only SMD parts are expected in the assembly BOM; through-hole parts/modules are manual assembly.
- New `JP2`, `JP5`, `JP6`, and `JP7` solder jumpers are for future CPU clock/IRQ experiments, not for the first normal bring-up.

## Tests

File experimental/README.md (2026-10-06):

# Experimental / archival (early 1551-rePico)

**Archival only.** Do not treat this tree as the supported product. It is kept for curious readers and for archaeology of the bring-up path that led to the current 1551-III-Pico board.

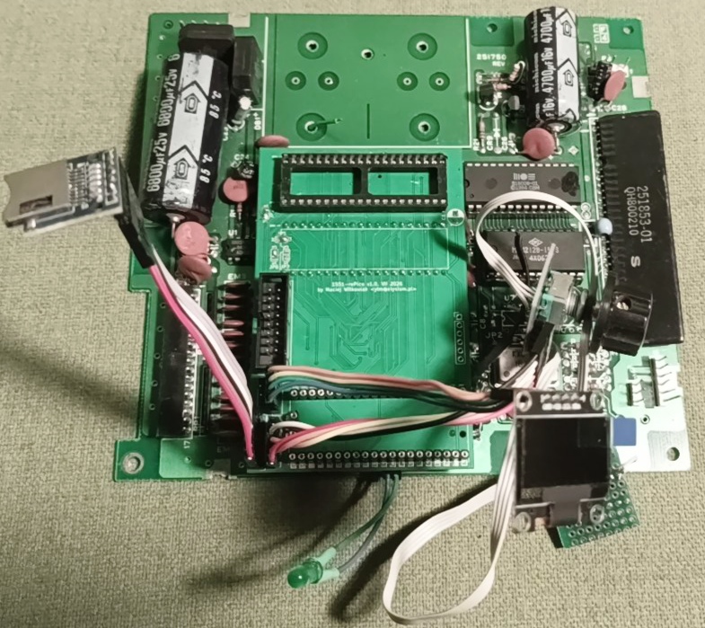
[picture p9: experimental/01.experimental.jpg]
1551 remains with experimental board


1551 mainboard remains with the experimental daughterboard plugged into CPU/TPI sockets.

Passthrough CPU socket is empty, the socket for Pico 2 is also not populated anymore.

Gate array was damaged and was replaced by 74'139 to split address space between RAM, TPI and ROM.

All the other I/O modules are connected: SD card, encoder, OLED and a single LED (to mainboard connector).

When running this board was powered by USB from Pico 2.

## What this was

Before **1551-III-Pico** (a self-contained Pico + CPLD + front-panel board that replaces the 1551 analog/disk electronics in a more finished form), we built a **daughterboard** that plugged over a stock Commodore 1551 mainboard. That let us reuse the real 6502/TPI/SRAM/ROM and experiment with:

- Pico replacing the floppy analog path (GCR, stepper, SD images)
- a CPLD **Fake6523** standing in for the 6523-side glue
- early Plus/4 / TCBM bring-up and pin mapping

That experiment proved the approach and informed the III hardware and firmware. It is **not** maintained and is **not** what you should build or flash for a release.

## Contents

| Path | Role |
|---|---|
| `hardware1551/` | KiCad project for the plug-over-1551-mainboard daughterboard |
| `hdl/` | Xilinx ISE CPLD project (`Fake6523`) for that daughterboard |
| `firmware/` | Fork of upstream **1541-rePico** firmware with `REPICO1551` adaptations used during daughterboard bring-up |

The **current** release artifacts live outside this folder:

- Hardware: `hardware-1551-III-Pico/`
- CPLD: `hdl-1551-III/`
- Firmware: `firmware-1551-III-pico/`
- Shared FatFs submodule (used by III firmware): `../no-OS-FatFS-SD-SDIO-SPI-RPi-Pico/`

## Firmware note

There was never a separate top-level `firmware-1551` tree. The early 1551 work lived inside the 1541-derived `firmware/` directory (now here). Product development continues only on **`firmware-1551-III-pico`**. Upstream 1541-rePico is no longer merged as a pull; at most, useful commits may be inspected and cherry-picked by hand into III firmware.

## Status

Frozen for history. Expect bitrot (tooling, pin maps, docs). Prefer III sources for anything you intend to ship or support.

`hardware1551/FABRICATION_CHECK_REPORT.md` and similar notes describe the **daughterboard** jumper map and bring-up checklist; they do **not** apply to `hardware-1551-III-Pico/`.

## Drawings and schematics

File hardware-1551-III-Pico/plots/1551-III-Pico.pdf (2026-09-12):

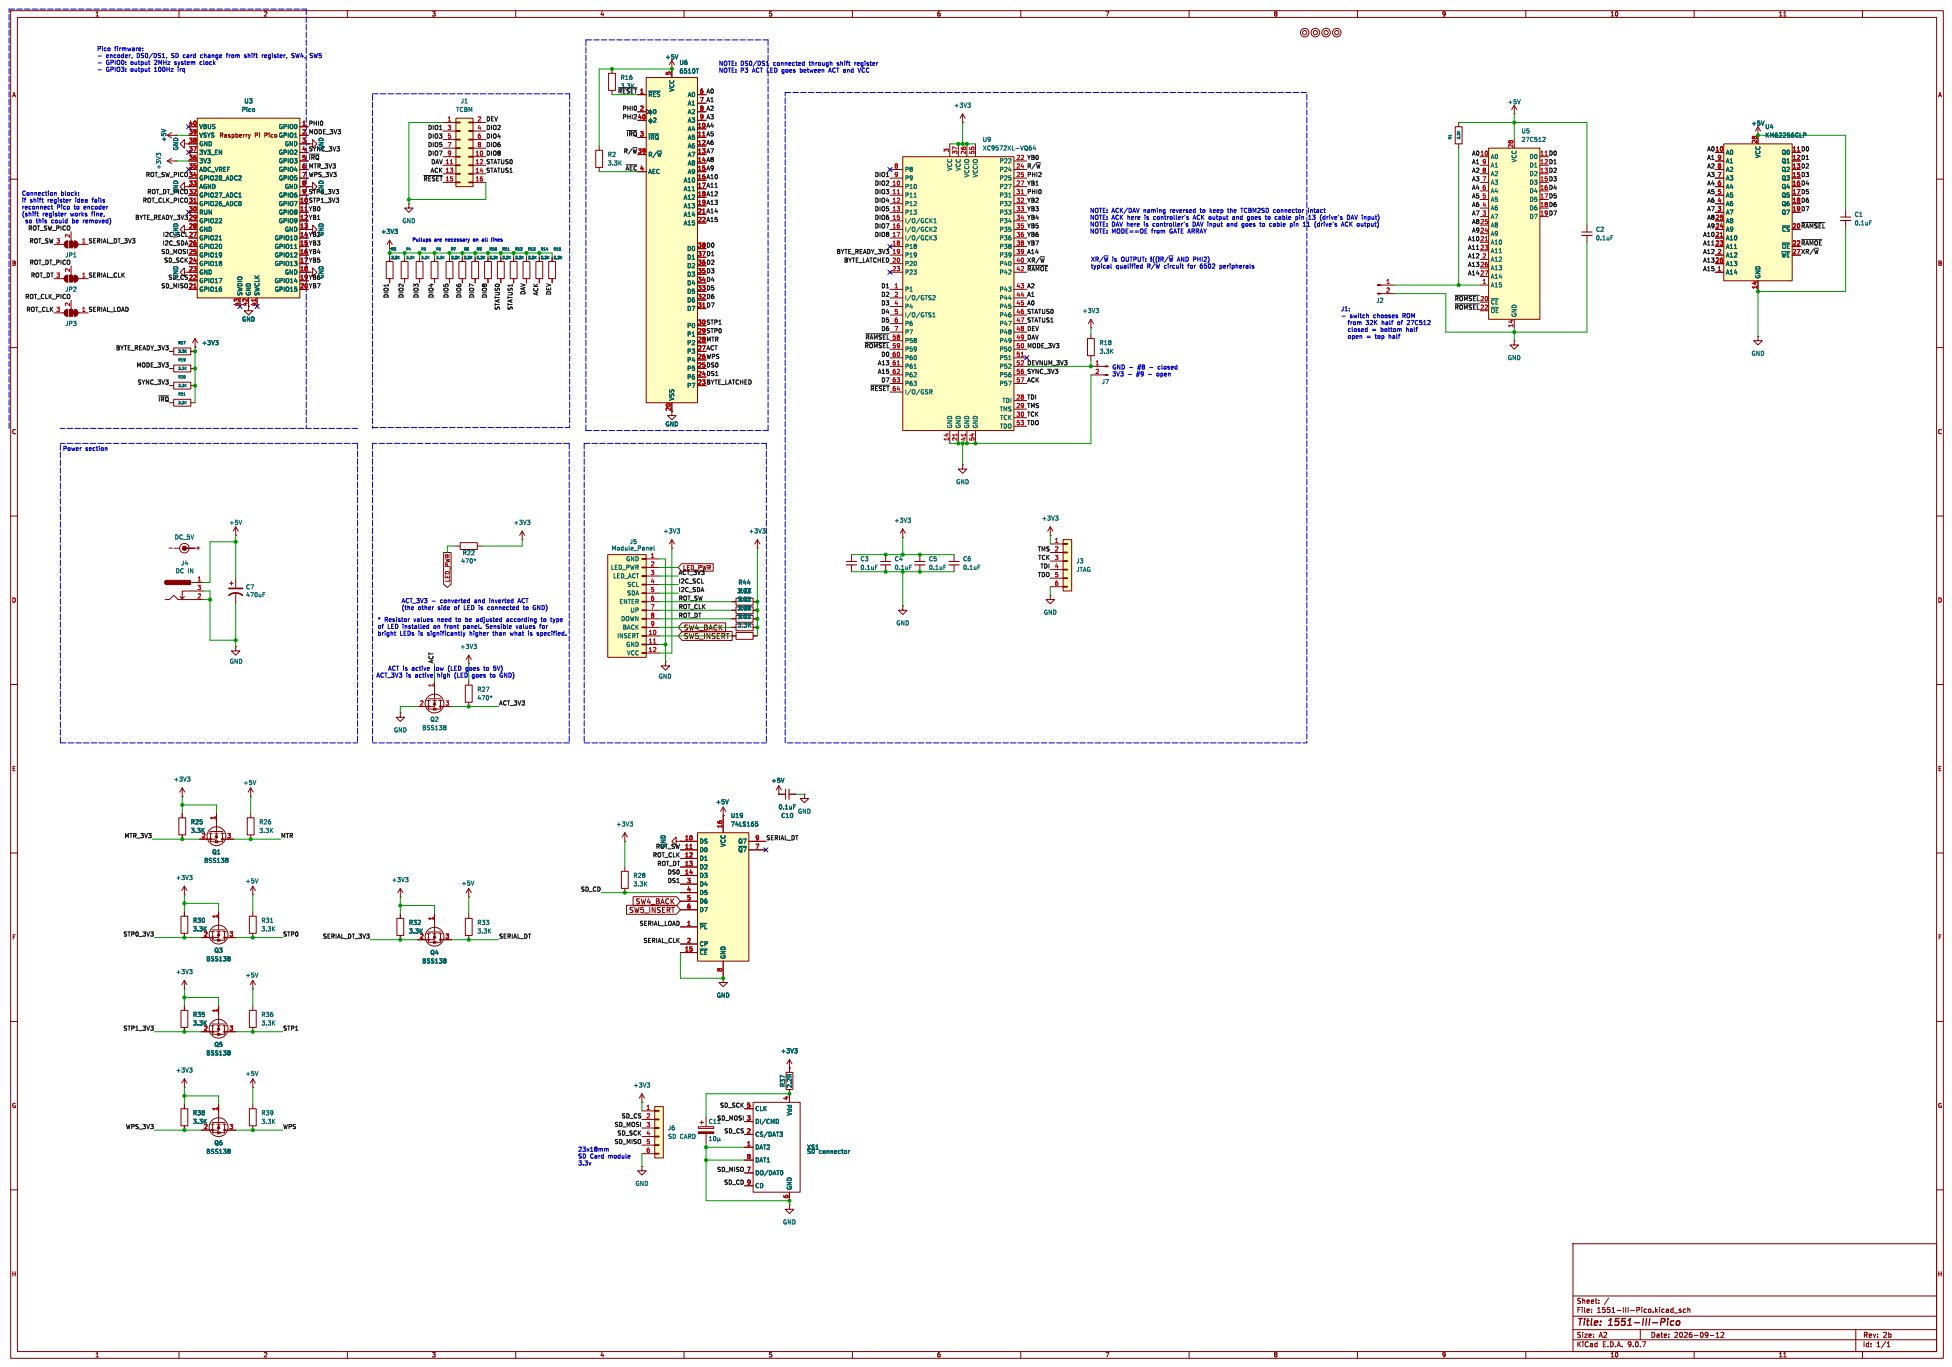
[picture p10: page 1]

3V3 36 ADC_VREF 35 GPIO28_ADC2 34 AGND 33 GPIO27_ADC1 32 GPIO26_ADC0 31 RUN 30 GPIO22 29 GND 28 GPIO21 27 GPIO20 26 GPIO19 25 GPIO18 24 GND 23 GPIO17 22 GPIO16 21 GND GND R17

Raspberry Pi Pico GPIO0 1 GPIO1 2 GND 3 GPIO2 4 GPIO3 5 GPIO4 6 GPIO5 7 GND 8 GPIO6 9 GPIO7 10 GPIO8 11 GPIO9 12 GND 13 GPIO10 14 GPIO11 15 GPIO12 16 GPIO13 17 GND 18 GPIO14 19 GPIO15 20 SWCLK 41 GND 42 SWDIO 43 VBUS 40 VSYS 39 GND 38

+3V3 GND GND GND GND

3 GND 14 VCC 37 GND 21 VCCIO 26 GND 41 VCCIO 55 GND 54 P22 22 P24 24 P25 25 P27 27 P31 31 P32 32 P33 33 P34 34 P35 35 P36 36 P38 38 P39 39 P40 40 P42 42 P43 43 P44 44 P45 45 P46 46 P47 47 P48 48 P49 49 P50 50 P51 51 P52 52 P56 56 P57 57 TDI 28 TMS 29 TCK 30 TDO 53 U9XC9572XL-VQ64

XR/~{W}is OUTPUT: !((!R/~{W} AND PHI2)
3.3K GND
SYNC_3V3 DEVNUM_3V3 TMS

closed = bottom half open = top half Power section

6 CLK 5 DI/CMD 3 CS/DAT3 2 DAT2 1 DAT1 8 DO/DAT0 7 CD 9 Q6 BSS138

6 CLK 5 DI/CMD 3 CS/DAT3 2 DAT2 1 DAT1 8 DO/DAT0 7 CD 9 XS1 SD connector

File: 1551-III-Pico.kicad_sch Sheet: /

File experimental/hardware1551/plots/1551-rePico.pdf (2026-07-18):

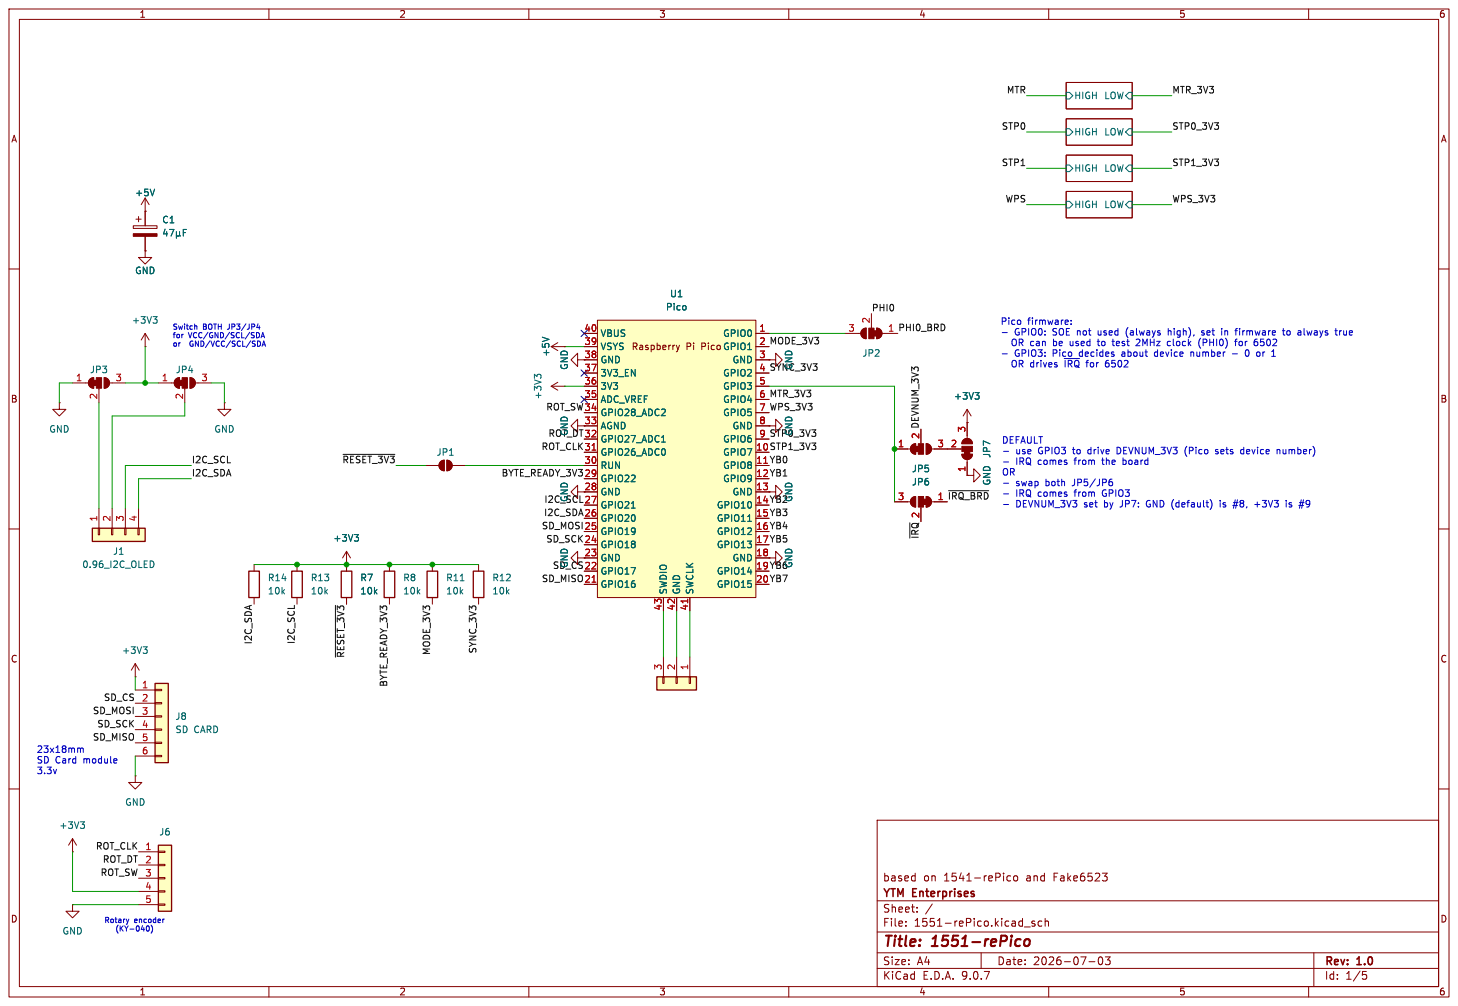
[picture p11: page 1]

SD_CS ~{RESET_3V3} Switch BOTH JP3/JP4
for VCC/GND/SCL/SDA

(unless it's not needed at all for G64) NOTE: Phi2 NC onboard, AEC pulled up DEFAULT
- use GPIO3 to drive DEVNUM_3V3 (Pico sets device number)
- IRQ comes from the board OR
0.1uF GND
- swap both JP5/JP6
- IRQ comes from GPIO3

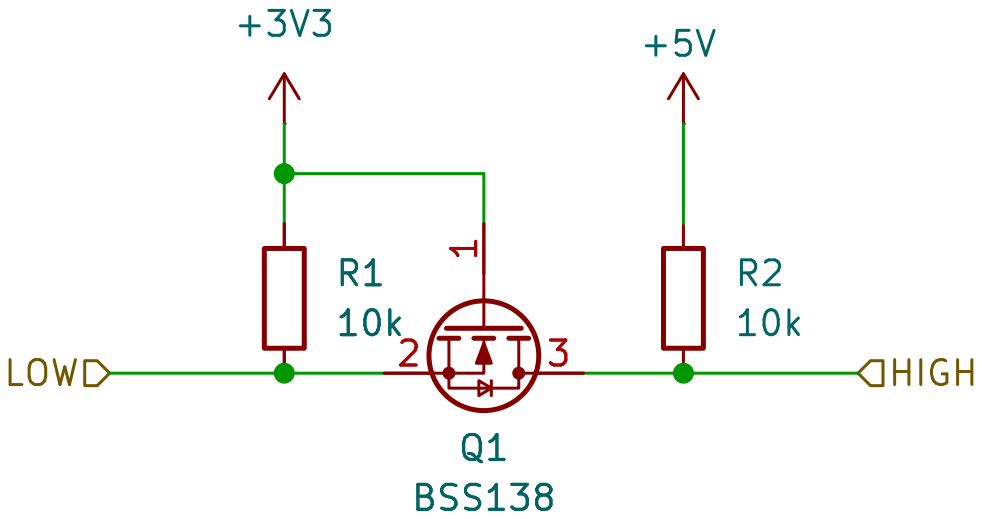
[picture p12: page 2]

Id: 2/5 Title: File: bss138.kicad_sch Sheet: /BSS138_6/

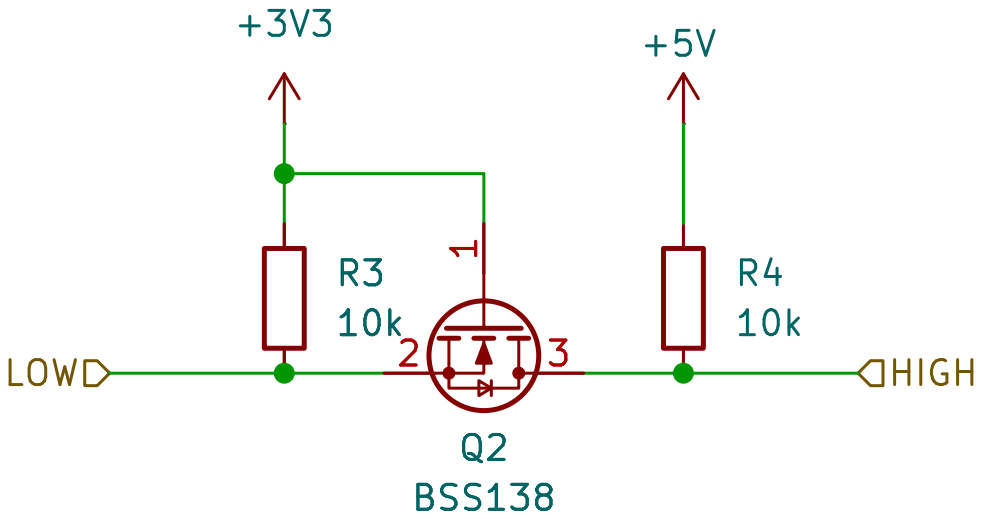
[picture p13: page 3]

Id: 3/5 Title: File: bss138.kicad_sch Sheet: /BSS138_7/

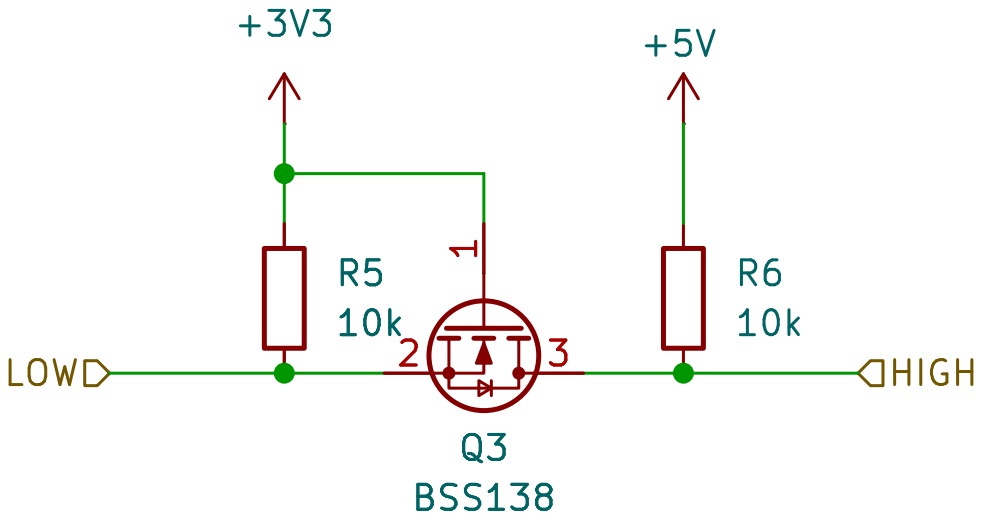
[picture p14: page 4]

Id: 4/5 Title: File: bss138.kicad_sch Sheet: /BSS138_8/

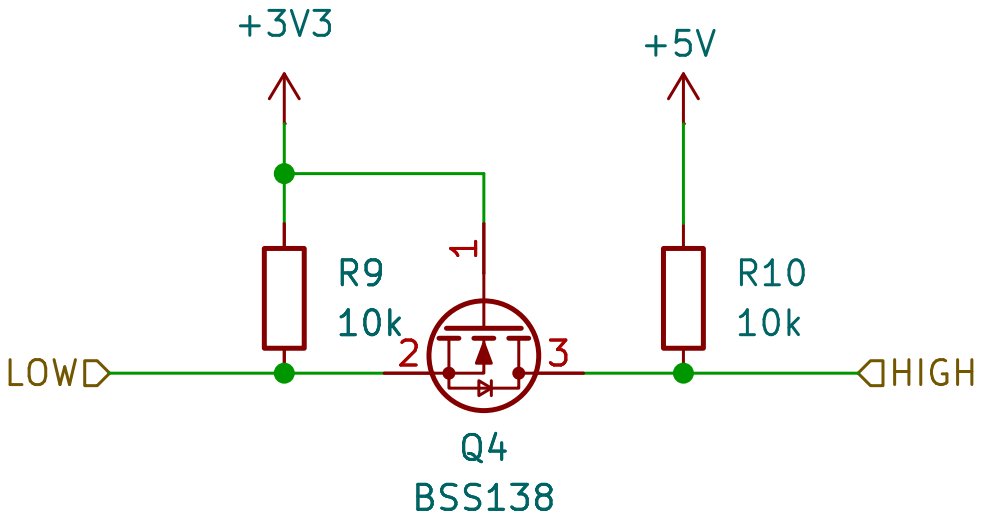
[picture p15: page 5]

Id: 5/5 Title: File: bss138.kicad_sch Sheet: /BSS138_9/

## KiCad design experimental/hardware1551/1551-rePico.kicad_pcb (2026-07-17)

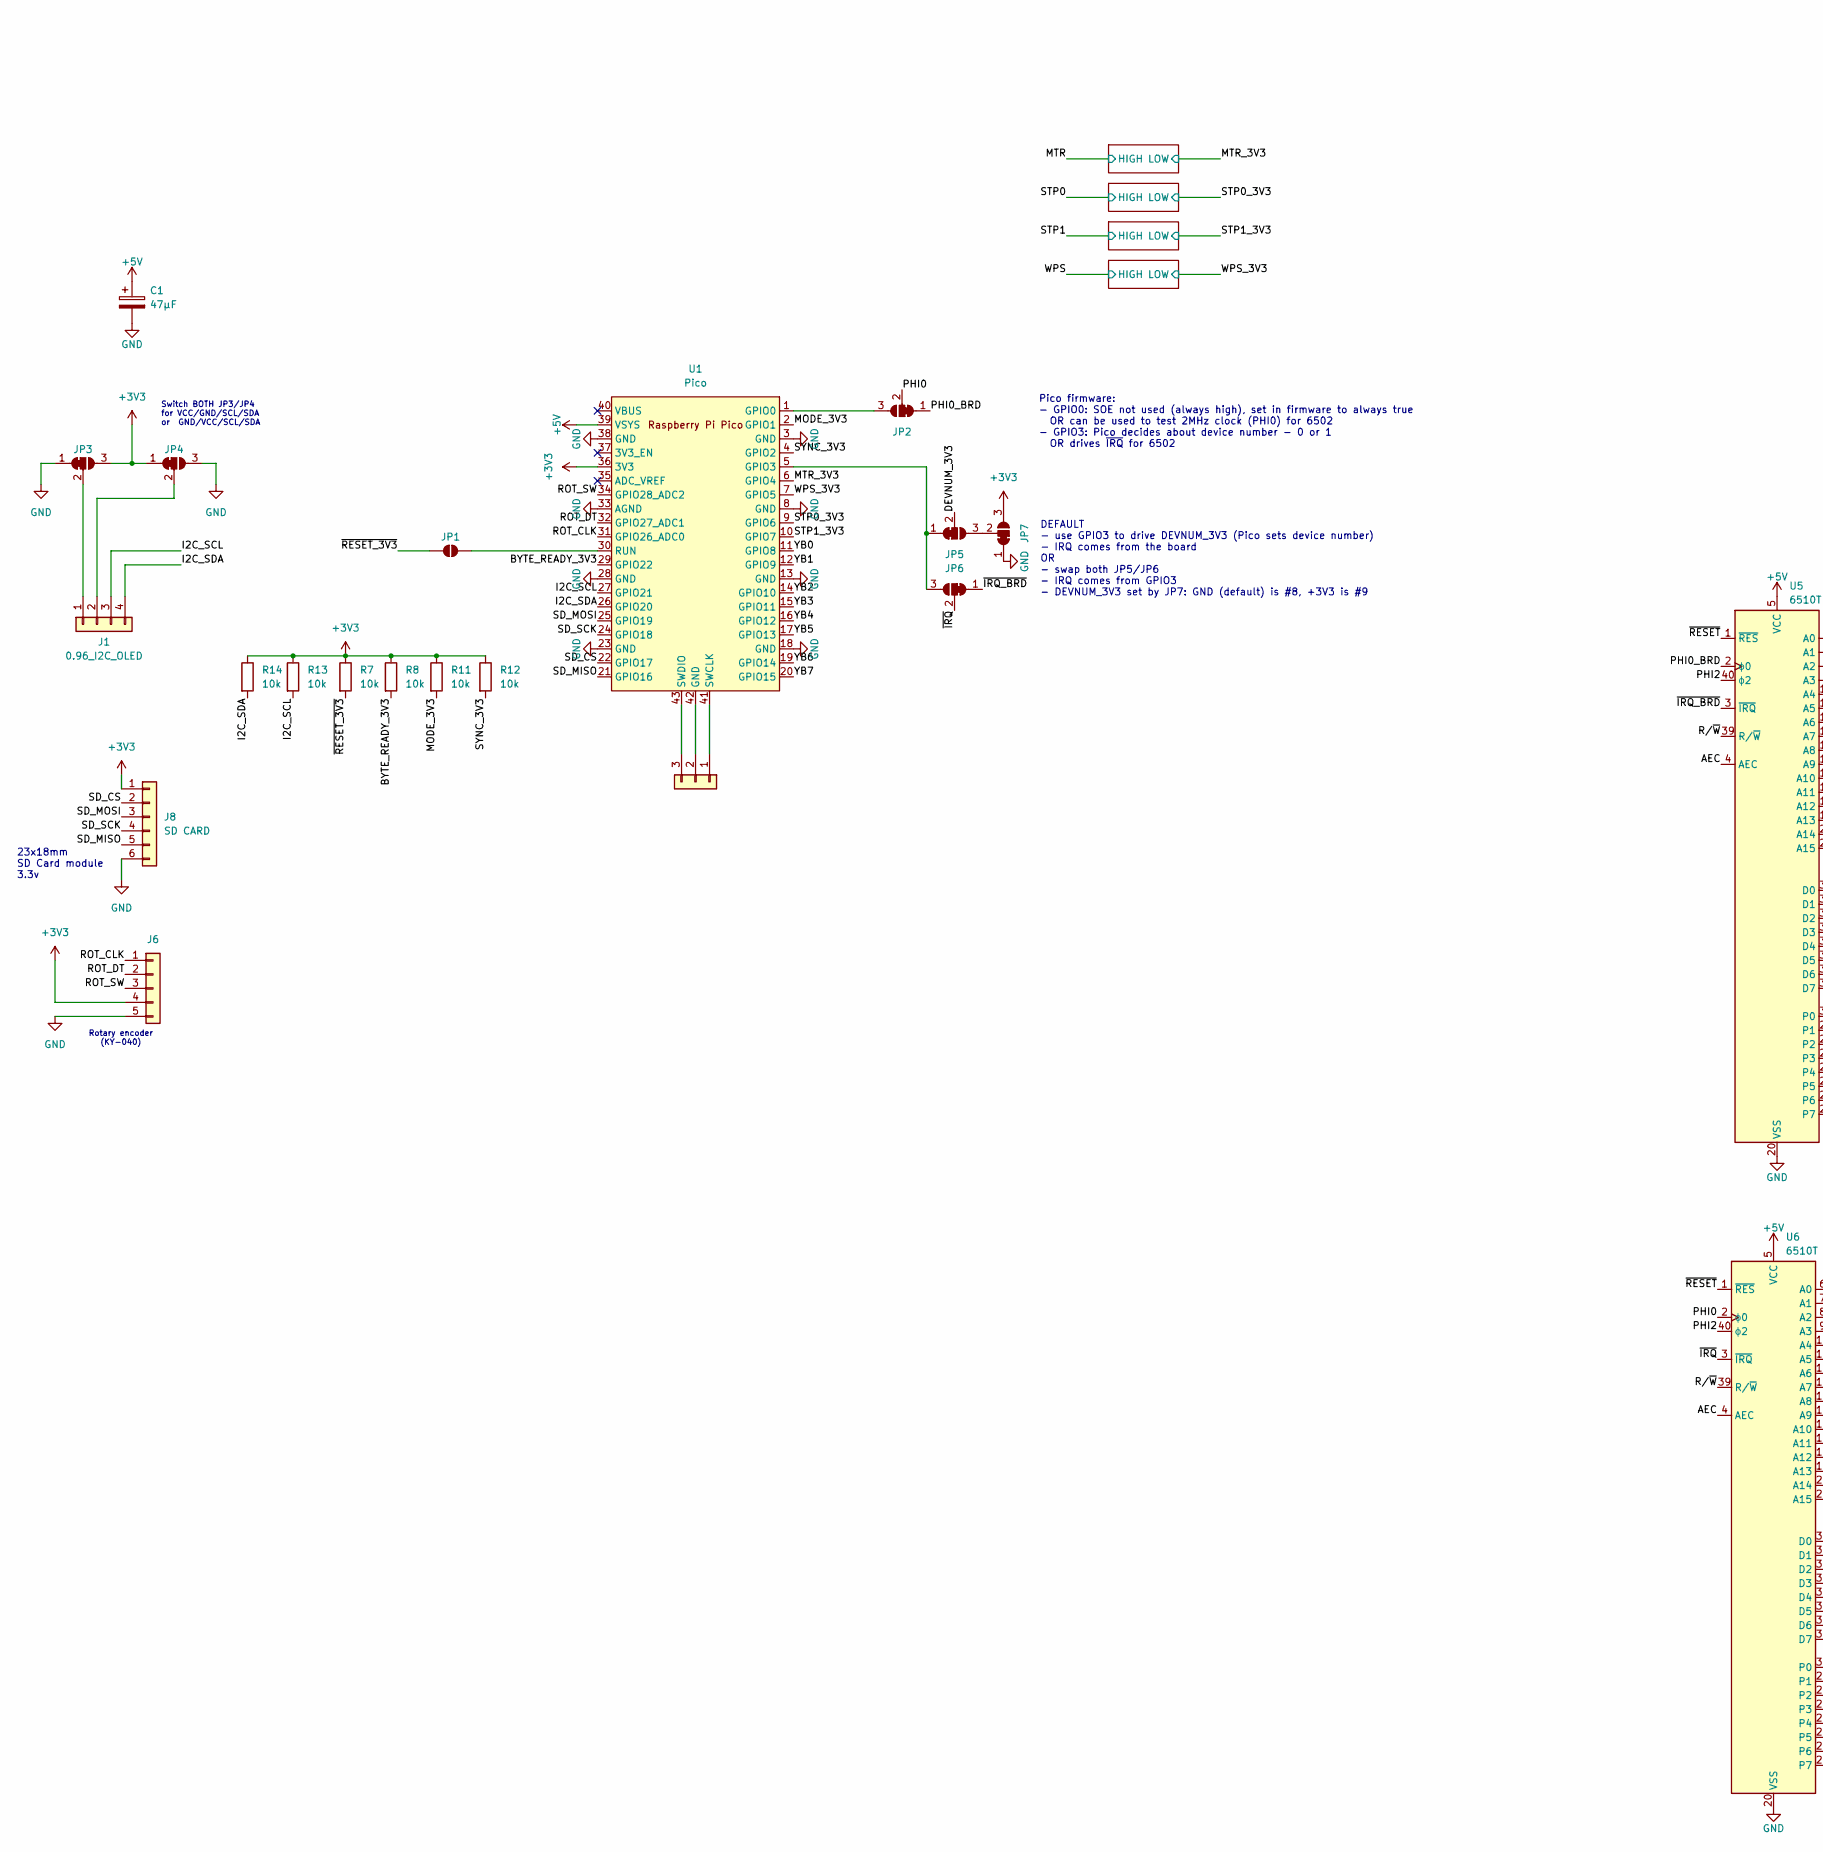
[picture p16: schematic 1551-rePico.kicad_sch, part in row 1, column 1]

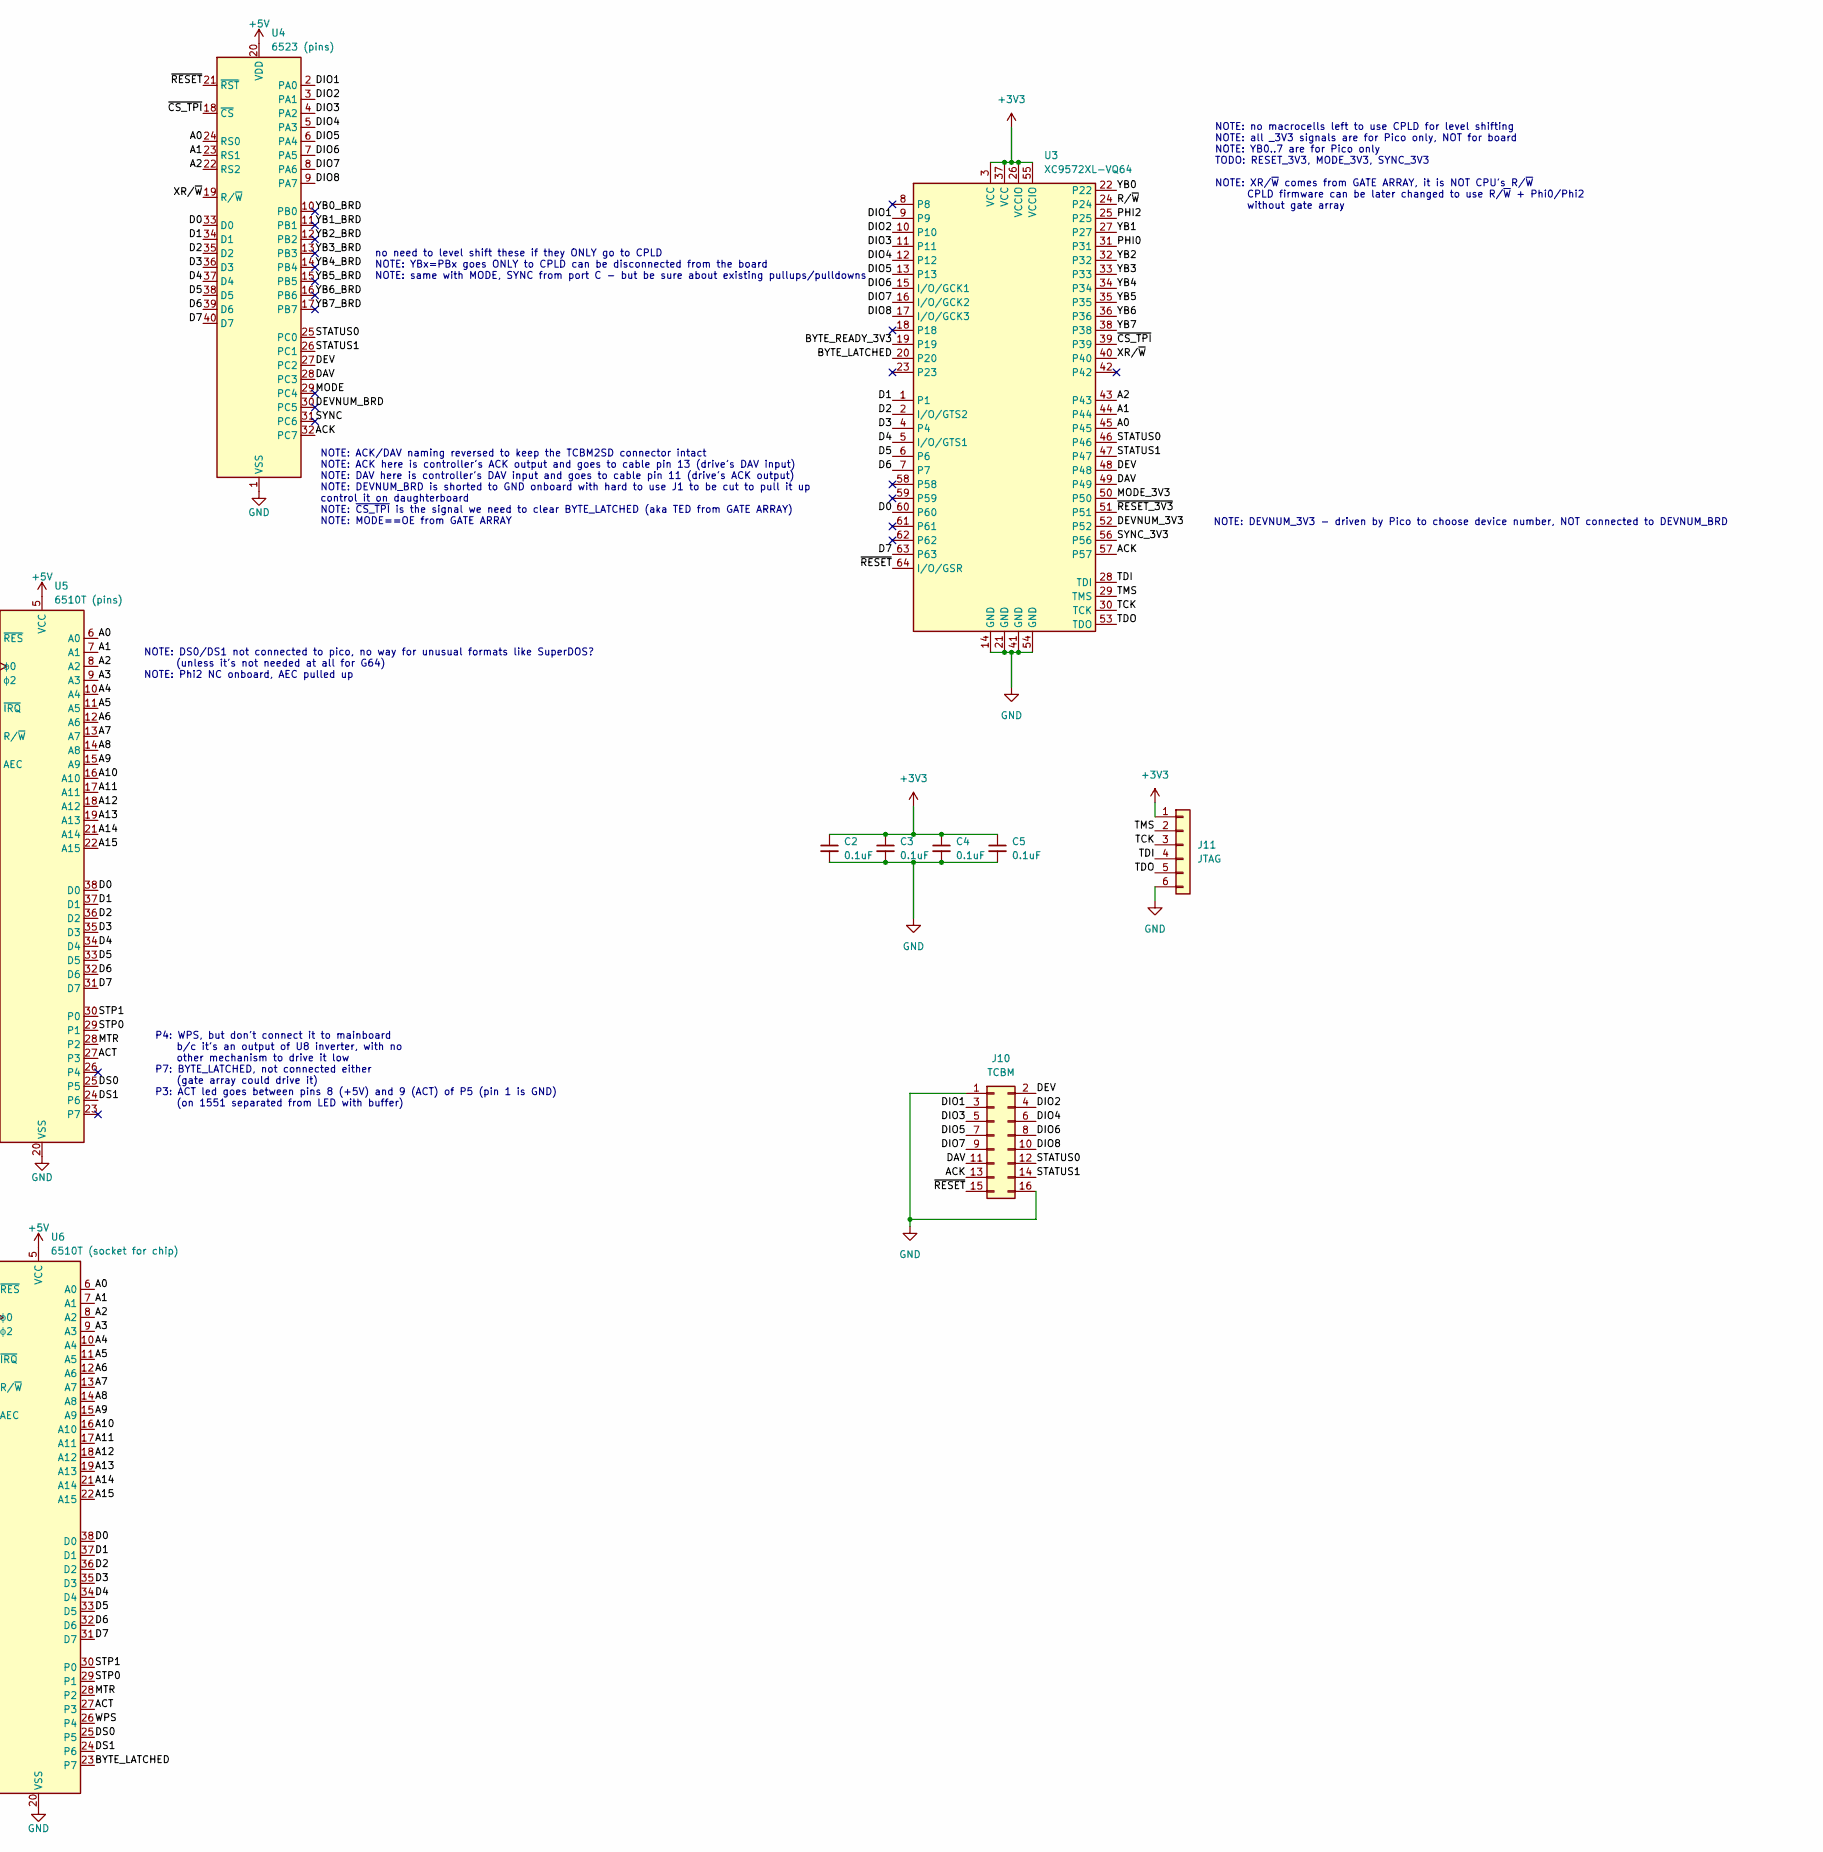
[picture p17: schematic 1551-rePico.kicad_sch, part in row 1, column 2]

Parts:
C1: 47µF; CP_Radial_D5.0mm_P2.50mm
C2, C3, C4, C5: 0.1uF; C_0805_2012Metric_Pad1.18x1.45mm_HandSolder; JLCPCB Part # C49678
J1: 0.96_I2C_OLED; PinHeader_1x04_P2.54mm_Vertical
J6: Conn_01x05; PinHeader_1x05_P2.54mm_Vertical
J8: SD CARD; PinHeader_1x06_P2.54mm_Vertical
J10: TCBM; IDC-Header_2x08_P2.54mm_Vertical
J11: JTAG; PinHeader_1x06_P2.54mm_Vertical
JP1: SolderJumper-2_P1.3mm_Open_RoundedPad1.0x1.5mm
JP2, JP3, JP4, JP5, JP6, JP7: SolderJumper_3_Bridged12; SolderJumper-3_P1.3mm_Bridged12_RoundedPad1.0x1.5mm_NumberL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
R7, R8, R11, R12, R13, R14: 10k; R_0805_2012Metric_Pad1.20x1.40mm_HandSolder; MFR.Part # RCA0510KFLF; JLCPCB Part # C22356686
SWDBG1: DEBUG; PinHeader_1x03_P2.54mm_Vertical
U1: Pico; RPi_Pico_SMD_TH
U3: XC9572XL-VQ64; TQFP-64_10x10mm_P0.5mm; JLCPCB Part # C90569
U4: 6523 (pins); DIP-40_W15.24mm
U5: 6510T (pins); DIP-40_W15.24mm
U6: 6510T (socket for chip); DIP-40_W15.24mm

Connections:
+3V3: C2.1, C3.1, C4.1, C5.1, J6.4, J8.1, J11.1, JP3.3 (B), JP4.1 (A), JP7.3 (B), R7.1, R8.1, R11.1, R12.1, R13.1, R14.1, U1.36 (3V3), U3.3 (VCC), U3.26 (VCCIO), U3.37 (VCC), U3.55 (VCCIO); also elsewhere on the board
+5V: C1.1, U1.39 (VSYS), U4.20 (VDD), U5.5 (VCC), U6.5 (VCC); also elsewhere on the board
/A0: U3.45, U4.24 (RS0), U5.6 (A0), U6.6 (A0)
/A1: U3.44, U4.23 (RS1), U5.7 (A1), U6.7 (A1)
/A2: U3.43, U4.22 (RS2), U5.8 (A2), U6.8 (A2)
/A3: U5.9 (A3), U6.9 (A3)
/A4: U5.10 (A4), U6.10 (A4)
/A5: U5.11 (A5), U6.11 (A5)
/A6: U5.12 (A6), U6.12 (A6)
/A7: U5.13 (A7), U6.13 (A7)
/A8: U5.14 (A8), U6.14 (A8)
/A9: U5.15 (A9), U6.15 (A9)
/A10: U5.16 (A10), U6.16 (A10)
/A11: U5.17 (A11), U6.17 (A11)
/A12: U5.18 (A12), U6.18 (A12)
/A13: U5.19 (A13), U6.19 (A13)
/A14: U5.21 (A14), U6.21 (A14)
/A15: U5.22 (A15), U6.22 (A15)
/ACK: J10.13, U3.57, U4.32 (PC7)
/ACT: U5.27 (P3), U6.27 (P3)
/AEC: U5.4 (AEC), U6.4 (AEC)
/BYTE_LATCHED: U3.20, U6.23 (P7)
/BYTE_READY_3V3: R8.2, U1.29 (GPIO22), U3.19
/D0: U3.60, U4.33 (D0), U5.38 (D0), U6.38 (D0)
/D1: U3.1, U4.34 (D1), U5.37 (D1), U6.37 (D1)
/D2: U3.2 (I/O/GTS2), U4.35 (D2), U5.36 (D2), U6.36 (D2)
/D3: U3.4, U4.36 (D3), U5.35 (D3), U6.35 (D3)
/D4: U3.5 (I/O/GTS1), U4.37 (D4), U5.34 (D4), U6.34 (D4)
/D5: U3.6, U4.38 (D5), U5.33 (D5), U6.33 (D5)
/D6: U3.7, U4.39 (D6), U5.32 (D6), U6.32 (D6)
/D7: U3.63, U4.40 (D7), U5.31 (D7), U6.31 (D7)
/DAV: J10.11, U3.49, U4.28 (PC3)
/DEV: J10.2, U3.48, U4.27 (PC2)
/DEVNUM_3V3: JP5.2 (C), U3.52
/DEVNUM_BRD: U4.30 (PC5)
/DIO1: J10.3, U3.9, U4.2 (PA0)
/DIO2: J10.4, U3.10, U4.3 (PA1)
/DIO3: J10.5, U3.11, U4.4 (PA2)
/DIO4: J10.6, U3.12, U4.5 (PA3)
/DIO5: J10.7, U3.13, U4.6 (PA4)
/DIO6: J10.8, U3.15 (I/O/GCK1), U4.7 (PA5)
/DIO7: J10.9, U3.16 (I/O/GCK2), U4.8 (PA6)
/DIO8: J10.10, U3.17 (I/O/GCK3), U4.9 (PA7)
/DS0: U5.25 (P5), U6.25 (P5)
/DS1: U5.24 (P6), U6.24 (P6)
/I2C_SCL: J1.3, R13.2, U1.27 (GPIO21)
/I2C_SDA: J1.4, R14.2, U1.26 (GPIO20)
/MODE: U4.29 (PC4)
/MODE_3V3: R11.2, U1.2 (GPIO1), U3.50
/MTR: U5.28 (P2), U6.28 (P2); also elsewhere on the board
/MTR_3V3: U1.6 (GPIO4); also elsewhere on the board
/PHI0: JP2.2 (C), U3.31, U6.2 (ϕ0)
/PHI0_BRD: JP2.1 (A), U5.2 (ϕ0)
/PHI2: U3.25, U5.40 (ϕ2), U6.40 (ϕ2)
/ROT_CLK: J6.1, U1.31 (GPIO26_ADC0)
/ROT_DT: J6.2, U1.32 (GPIO27_ADC1)
/ROT_SW: J6.3, U1.34 (GPIO28_ADC2)
/R/~W: U3.24, U5.39 (R/~W), U6.39 (R/~W)
/SD_CS: J8.2, U1.22 (GPIO17)
/SD_MISO: J8.5, U1.21 (GPIO16)
/SD_MOSI: J8.3, U1.25 (GPIO19)
/SD_SCK: J8.4, U1.24 (GPIO18)
/STATUS0: J10.12, U3.46, U4.25 (PC0)
/STATUS1: J10.14, U3.47, U4.26 (PC1)
/STP0: U5.29 (P1), U6.29 (P1); also elsewhere on the board
/STP0_3V3: U1.9 (GPIO6); also elsewhere on the board
/STP1: U5.30 (P0), U6.30 (P0); also elsewhere on the board
/STP1_3V3: U1.10 (GPIO7); also elsewhere on the board
/SYNC: U4.31 (PC6)
/SYNC_3V3: R12.2, U1.4 (GPIO2), U3.56
/TCK: J11.3, U3.30 (TCK)
/TDI: J11.4, U3.28 (TDI)
/TDO: J11.5, U3.53 (TDO)
/TMS: J11.2, U3.29 (TMS)
/WPS: U6.26 (P4); also elsewhere on the board
/WPS_3V3: U1.7 (GPIO5); also elsewhere on the board
/XR/~W: U3.40, U4.19 (R/~W)
/YB0: U1.11 (GPIO8), U3.22
/YB0_BRD: U4.10 (PB0)
/YB1: U1.12 (GPIO9), U3.27
/YB1_BRD: U4.11 (PB1)
/YB2: U1.14 (GPIO10), U3.32
/YB2_BRD: U4.12 (PB2)
/YB3: U1.15 (GPIO11), U3.33
/YB3_BRD: U4.13 (PB3)
/YB4: U1.16 (GPIO12), U3.34
/YB4_BRD: U4.14 (PB4)
/YB5: U1.17 (GPIO13), U3.35
/YB5_BRD: U4.15 (PB5)
/YB6: U1.19 (GPIO14), U3.36
/YB6_BRD: U4.16 (PB6)
/YB7: U1.20 (GPIO15), U3.38
/YB7_BRD: U4.17 (PB7)
/~CS_TPI: U3.39, U4.18 (~CS)
/~IRQ_BRD: JP6.1 (A), U5.3 (~IRQ)
/~IRQ: JP6.2 (C), U6.3 (~IRQ)
/~RESET_3V3: JP1.1 (A), R7.2, U3.51
/~RESET: J10.15, U3.64 (I/O/GSR), U4.21 (~RST), U5.1 (~RES), U6.1 (~RES)
GND: C1.2, C2.2, C3.2, C4.2, C5.2, J6.5, J8.6, J10.1, J10.16, J11.6, JP3.1 (A), JP4.3 (B), JP7.1 (A), U1.3 (GND), U1.8 (GND), U1.13 (GND), U1.18 (GND), U1.23 (GND), U1.28 (GND), U1.33 (AGND), U1.38 (GND), U3.14 (GND), U3.21 (GND), U3.41 (GND), U3.54 (GND), U4.1 (VSS), U5.20 (VSS), U6.20 (VSS)
unnamed: J1.1, JP3.2 (C)
unnamed: J1.2, JP4.2 (C)
unnamed: JP1.2 (B), U1.30 (RUN)
unnamed: JP2.3 (B), U1.1 (GPIO0)
unnamed: JP5.1 (A), JP6.3 (B), U1.5 (GPIO3)
unnamed: JP5.3 (B), JP7.2 (C)
unnamed: SWDBG1.1, U1.41 (SWCLK)
unnamed: SWDBG1.2, U1.42 (GND)
unnamed: SWDBG1.3, U1.43 (SWDIO)

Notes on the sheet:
DEFAULT - use GPIO3 to drive DEVNUM_3V3 (Pico sets device number) - IRQ comes from the board OR - swap both JP5/JP6 - IRQ comes from GPIO3 - DEVNUM_3V3 set by JP7: GND (default) is #8, +3V3 is #9
Rotary encoder (KY-040)
NOTE: DS0/DS1 not connected to pico, no way for unusual formats like SuperDOS? (unless it's not needed at all for G64) NOTE: Phi2 NC onboard, AEC pulled up
NOTE: DEVNUM_3V3 - driven by Pico to choose device number, NOT connected to DEVNUM_BRD
NOTE: no macrocells left to use CPLD for level shifting NOTE: all _3V3 signals are for Pico only, NOT for board NOTE: YB0..7 are for Pico only TODO: RESET_3V3, MODE_3V3, SYNC_3V3 NOTE: XR/~{W} comes from GATE ARRAY, it is NOT CPU's R/~{W} CPLD firmware can be later changed to use R/~{W} + Phi0/Phi2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
NOTE: ACK/DAV naming reversed to keep the TCBM2SD connector intact NOTE: ACK here is controller's ACK output and goes to cable pin 13 (drive's DAV input) NOTE: DAV here is controller's DAV input and goes to cable pin 11 (drive's ACK output) NOTE: DEVNUM_BRD is shorted to GND onboard with hard to us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
23x18mm SD Card module 3.3v
no need to level shift these if they ONLY go to CPLD NOTE: YBx=PBx goes ONLY to CPLD can be disconnected from the board NOTE: same with MODE, SYNC from port C - but be sure about existing pullups/pulldowns
Switch BOTH JP3/JP4 for VCC/GND/SCL/SDA or GND/VCC/SCL/SDA
P4: WPS, but don't connect it to mainboard b/c it's an output of U8 inverter, with no other mechanism to drive it low P7: BYTE_LATCHED, not connected either (gate array could drive it) P3: ACT led goes between pins 8 (+5V) and 9 (ACT) of P5 (pin 1 is GND) (on 1551 separated from LED with buffer)
Pico firmware: - GPIO0: SOE not used (always high), set in firmware to always true OR can be used to test 2MHz clock (PHI0) for 6502 - GPIO3: Pico decides about device number - 0 or 1 OR drives ~{IRQ} for 6502

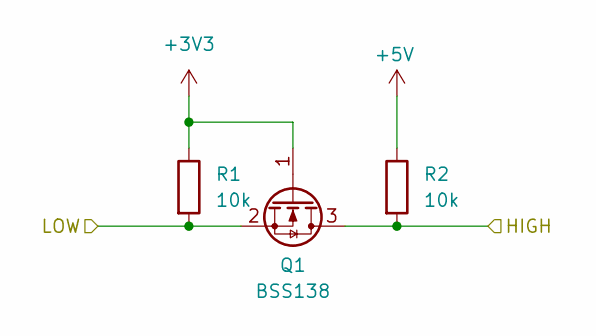
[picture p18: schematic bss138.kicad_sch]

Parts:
Q1: BSS138; SOT-23; MFR.Part # BSS138; JLCPCB Part # C78284
R1, R2: 10k; R_0805_2012Metric_Pad1.20x1.40mm_HandSolder; MFR.Part # RCA0510KFLF; JLCPCB Part # C22356686

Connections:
+3V3: Q1.1 (G), R1.1; also elsewhere on the board
+5V: R2.1; also elsewhere on the board
/MTR: Q1.3 (D), R2.2; also elsewhere on the board
/MTR_3V3: Q1.2 (S), R1.2; also elsewhere on the board

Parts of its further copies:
Q2, Q3, Q4: BSS138; SOT-23; MFR.Part # BSS138; JLCPCB Part # C78284
R3, R4, R5, R6, R9, R10: 10k; R_0805_2012Metric_Pad1.20x1.40mm_HandSolder; MFR.Part # RCA0510KFLF; JLCPCB Part # C22356686

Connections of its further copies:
+3V3: Q2.1 (G), Q3.1 (G), Q4.1 (G), R3.1, R5.1, R9.1; also elsewhere on the board
+5V: R4.1, R6.1, R10.1; also elsewhere on the board
/STP0: Q2.3 (D), R4.2; also elsewhere on the board
/STP0_3V3: Q2.2 (S), R3.2; also elsewhere on the board
/STP1: Q3.3 (D), R6.2; also elsewhere on the board
/STP1_3V3: Q3.2 (S), R5.2; also elsewhere on the board
/WPS: Q4.3 (D), R10.2; also elsewhere on the board
/WPS_3V3: Q4.2 (S), R9.2; also elsewhere on the board

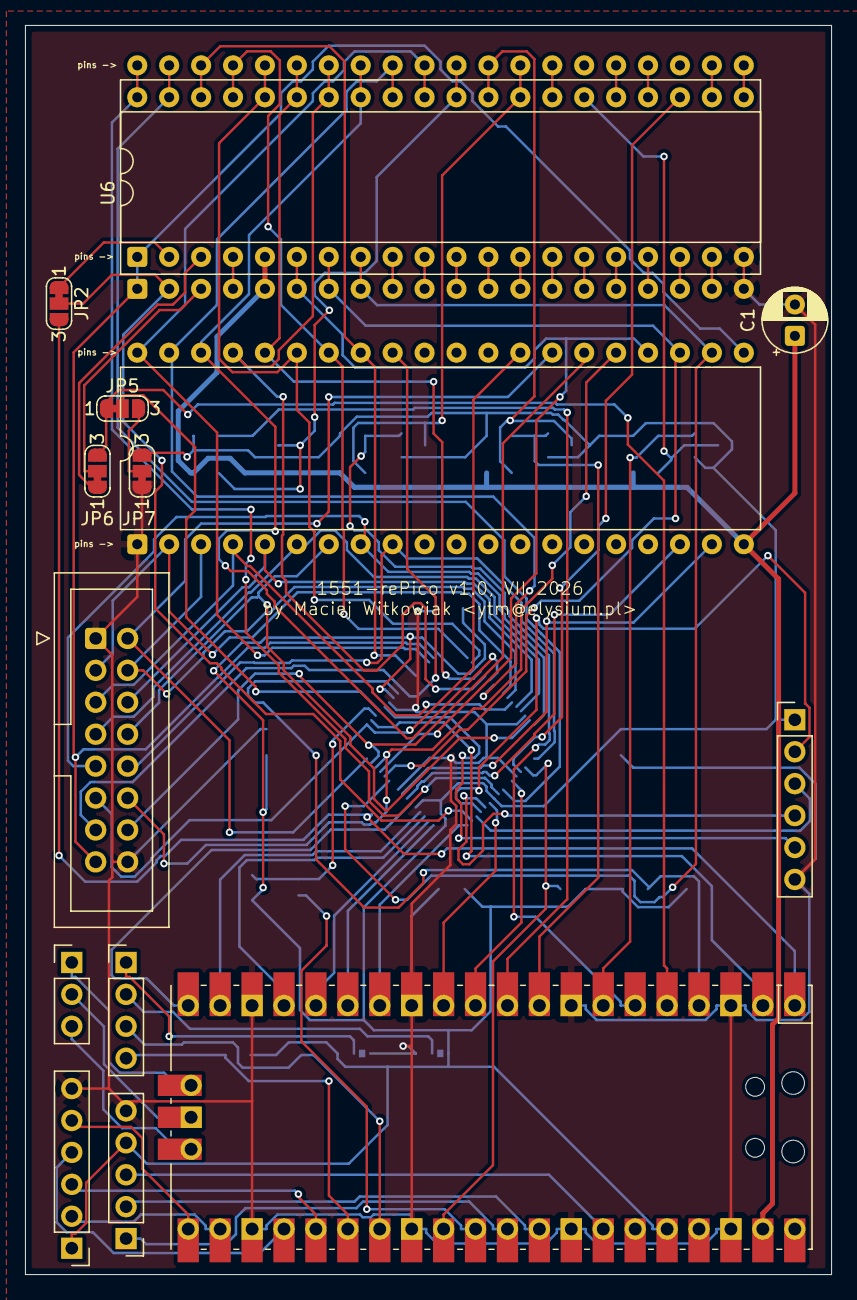
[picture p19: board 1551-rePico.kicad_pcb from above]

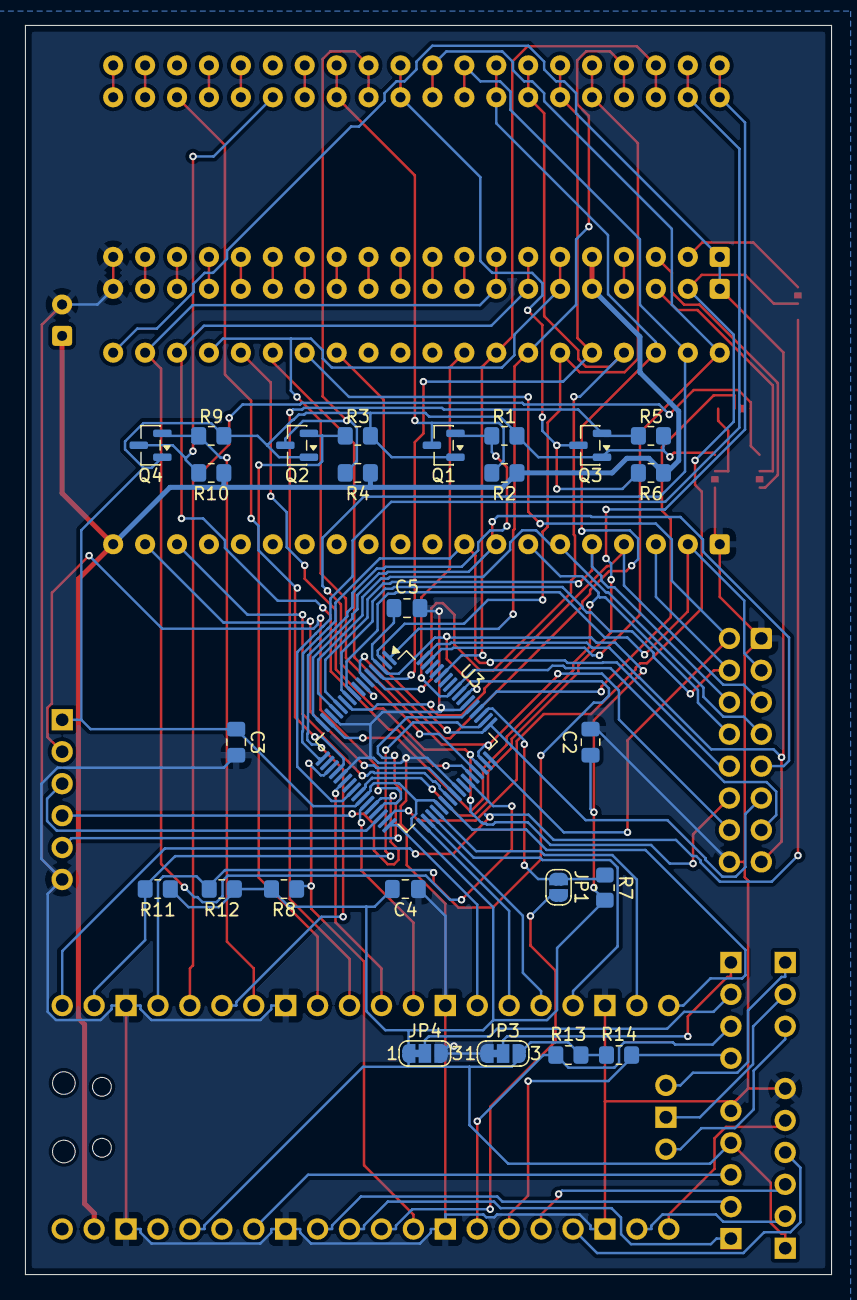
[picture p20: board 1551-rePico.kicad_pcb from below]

Board: 2 copper layers, 64.1 x 99.4 mm, 41 parts (26 on the bottom side), 97 nets.

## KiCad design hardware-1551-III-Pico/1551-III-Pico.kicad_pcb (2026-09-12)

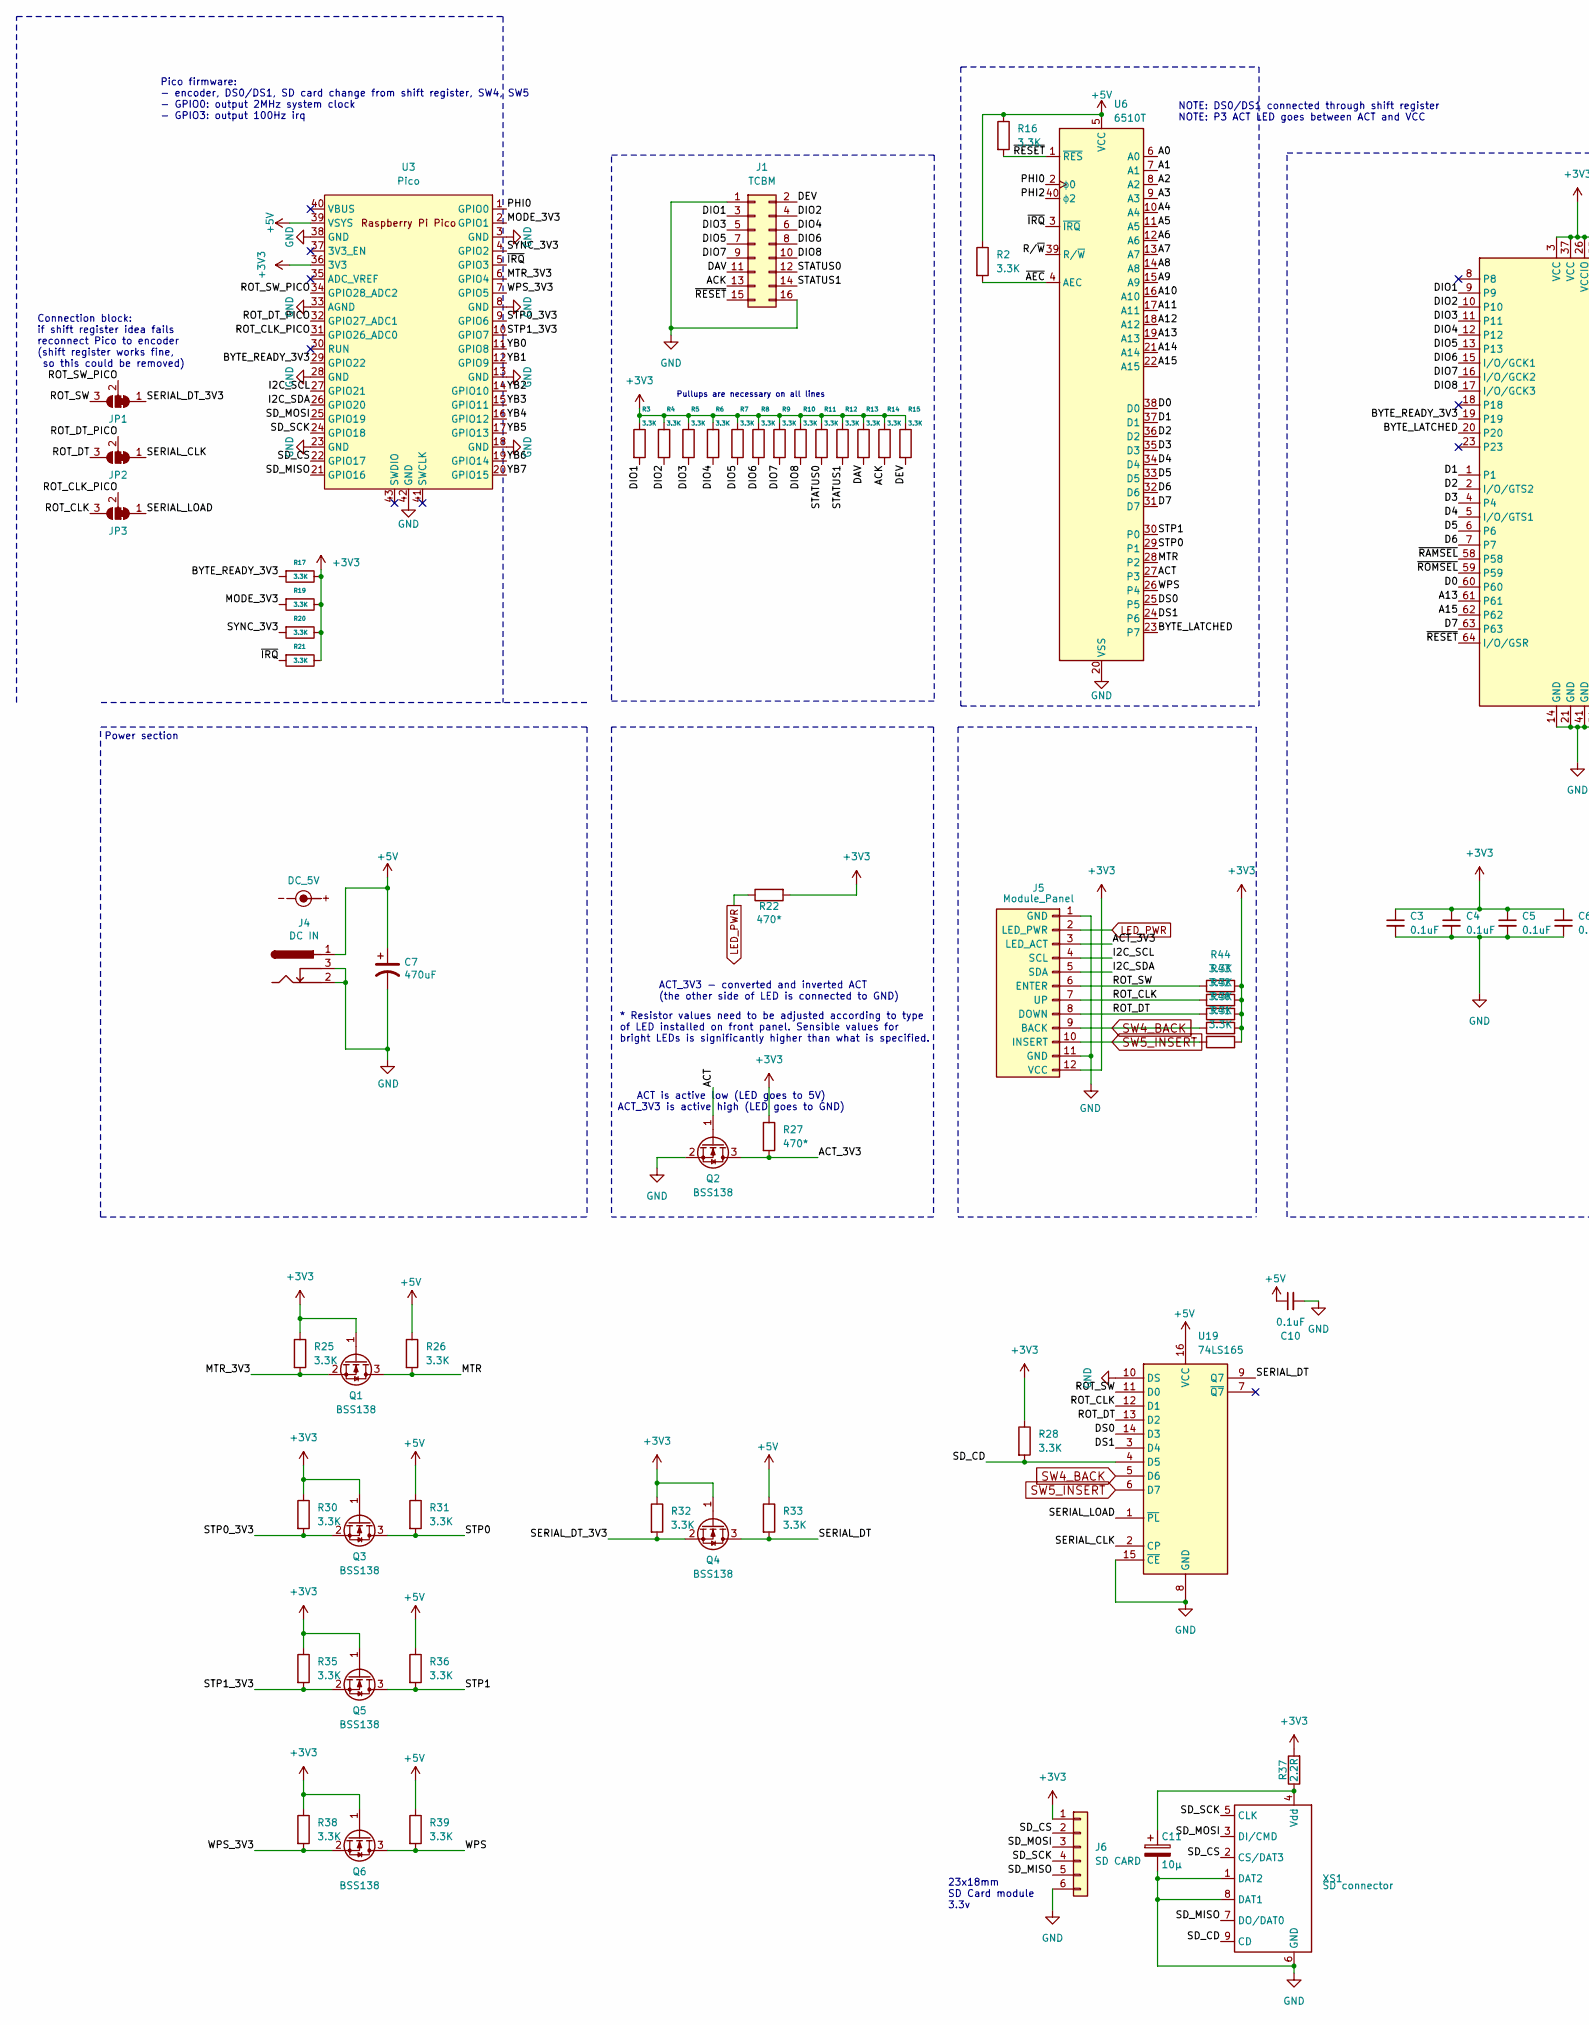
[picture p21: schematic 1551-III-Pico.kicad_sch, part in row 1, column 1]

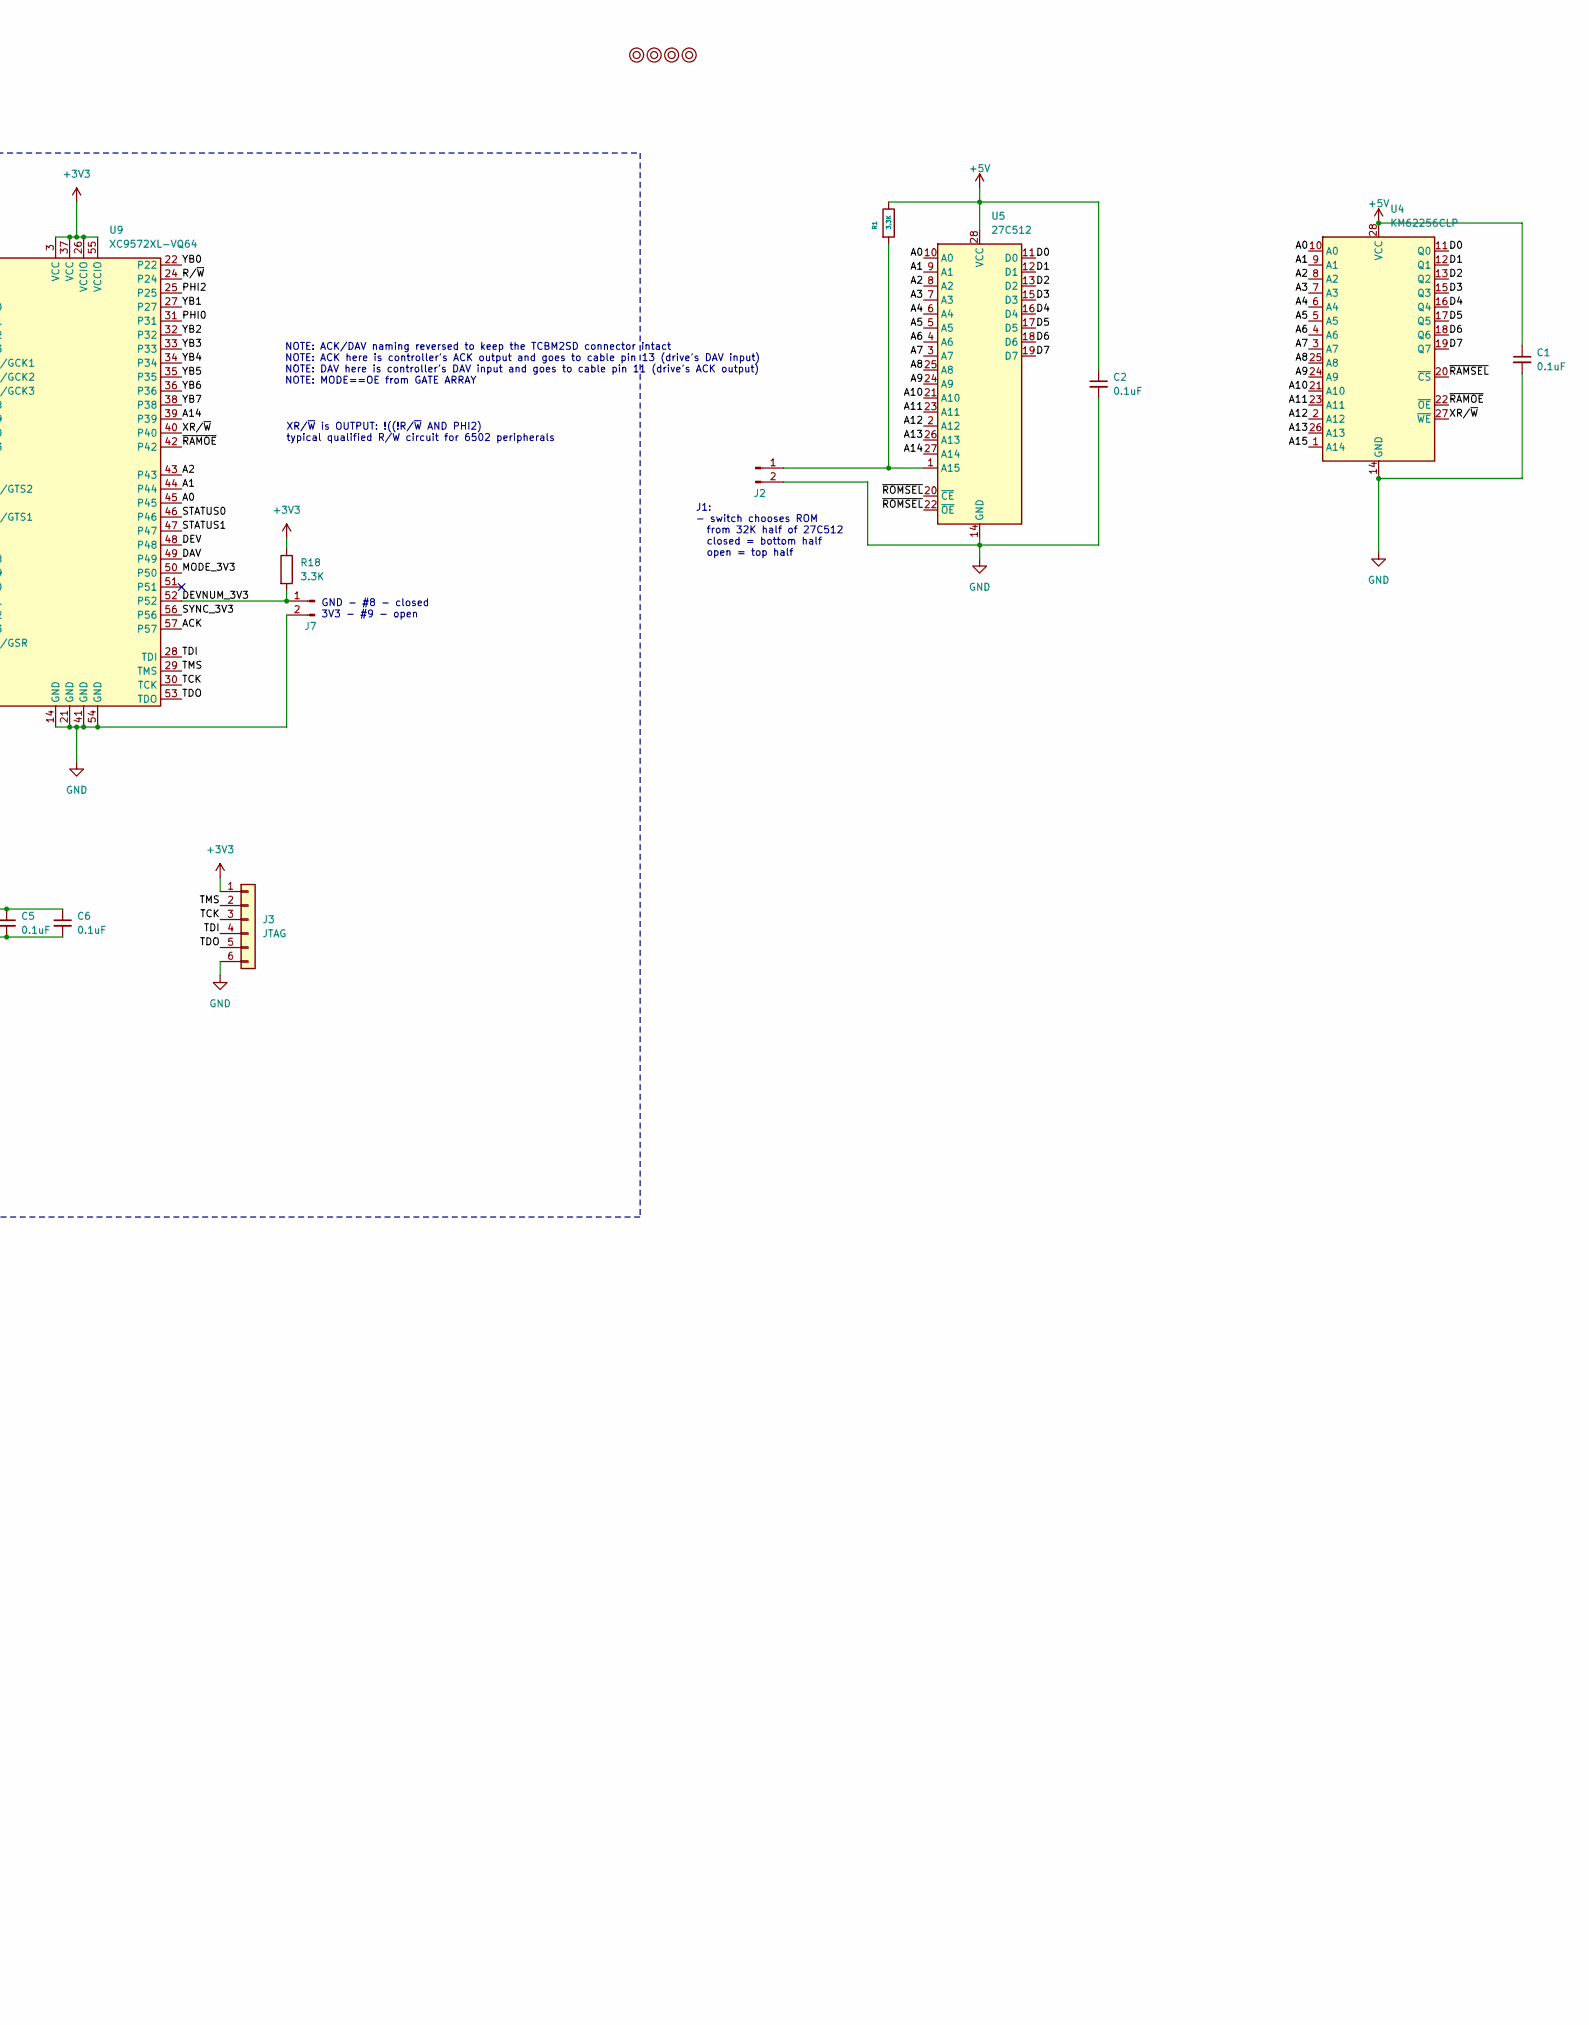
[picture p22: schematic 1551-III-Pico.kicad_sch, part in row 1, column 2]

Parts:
C1, C2, C3, C4, C5, C6, C10: 0.1uF; C_0805_2012Metric_Pad1.18x1.45mm_HandSolder; JLCPCB Part # C49678
C7: 470uF; CP_Radial_D8.0mm_P3.50mm
C11: 10µ; CP_EIA-3216-12_Kemet-S_HandSolder; JLCPCB Part # C1969735
J1: TCBM; IDC-Header_2x08_P2.54mm_Vertical
J2, J7: Conn_01x02_Pin; PinHeader_1x02_P2.54mm_Vertical
J3: JTAG; PinHeader_1x06_P2.54mm_Vertical
J4: DC IN; BARREL_JACK
J5: Module_Panel
J6: SD CARD; PinHeader_1x06_P2.54mm_Vertical
JP1, JP2, JP3: SolderJumper_3_Bridged12; SolderJumper-3_P1.3mm_Bridged12_RoundedPad1.0x1.5mm_NumberL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
M1, M2, M3, M4: Mounting; M3
Q1, Q2, Q3, Q4, Q5, Q6: BSS138; SOT-23; MFR.Part # BSS138; JLCPCB Part # C78284
R1, R2, R3, R4, R5, R6, R7, R8, R9, R10, R11, R12, R13, R14, R15, R16, R17, R18, R19, R20, R21, R25, R26, R28, R30, R31, R32, R33, R35, R36, R38, R39, R40, R41, R42, R43, R44: 3.3K; R_0805_2012Metric_Pad1.20x1.40mm_HandSolder; MFR.Part # 0805W8F3301T5E; JLCPCB Part # C26010
R22, R27: 470*; R_0805_2012Metric_Pad1.20x1.40mm_HandSolder; MFR.Part # 0805W8F4700T5E; JLCPCB Part # C17710
R37: 2.2R; R_0805_2012Metric_Pad1.20x1.40mm_HandSolder; JLCPCB Part # C17521
SYM1: DC_5V; PWR_Specification
U3: Pico; RPi_Pico_SMD_TH
U4: KM62256CLP; DIP-28_W15.24mm_Socket_LongPads
U5: 27C512; DIP-28_W15.24mm_Socket_LongPads
U6: 6510T; DIP-40_W15.24mm
U9: XC9572XL-VQ64; TQFP-64_10x10mm_P0.5mm; JLCPCB Part # C90569
U19: 74LS165; SOP-16_4.4x10.4mm_P1.27mm; MFR.Part # SN74LS165ADR; JLCPCB Part # C7742
XS1: SD connector; Conn_uSDcard; JLCPCB Part # C7529389

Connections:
+3V3: C3.1, C4.1, C5.1, C6.1, J3.1, J5.12 (VCC), J6.1, Q1.1 (G), Q3.1 (G), Q4.1 (G), Q5.1 (G), Q6.1 (G), R3.1, R4.1, R5.1, R6.1, R7.1, R8.1, R9.1, R10.1, R11.1, R12.1, R13.1, R14.1, R15.1, R17.1, R18.1, R19.1, R20.1, R21.1, R22.2, R25.1, R27.1, R28.1, R30.1, R32.1, R35.1, R37.2, R38.1, R40.2, R41.2, R42.2, R43.2, R44.2, U3.36 (3V3), U9.3 (VCC), U9.26 (VCCIO), U9.37 (VCC), U9.55 (VCCIO)
+5V: C1.1, C2.1, C7.1, C10.1, J4.1, R1.1, R2.1, R16.1, R26.1, R31.1, R33.1, R36.1, R39.1, U3.39 (VSYS), U4.28 (VCC), U5.28 (VCC), U6.5 (VCC), U19.16 (VCC)
/A0: U4.10 (A0), U5.10 (A0), U6.6 (A0), U9.45
/A1: U4.9 (A1), U5.9 (A1), U6.7 (A1), U9.44
/A2: U4.8 (A2), U5.8 (A2), U6.8 (A2), U9.43
/A3: U4.7 (A3), U5.7 (A3), U6.9 (A3)
/A4: U4.6 (A4), U5.6 (A4), U6.10 (A4)
/A5: U4.5 (A5), U5.5 (A5), U6.11 (A5)
/A6: U4.4 (A6), U5.4 (A6), U6.12 (A6)
/A7: U4.3 (A7), U5.3 (A7), U6.13 (A7)
/A8: U4.25 (A8), U5.25 (A8), U6.14 (A8)
/A9: U4.24 (A9), U5.24 (A9), U6.15 (A9)
/A10: U4.21 (A10), U5.21 (A10), U6.16 (A10)
/A11: U4.23 (A11), U5.23 (A11), U6.17 (A11)
/A12: U4.2 (A12), U5.2 (A12), U6.18 (A12)
/A13: U4.26 (A13), U5.26 (A13), U6.19 (A13), U9.61
/A14: U5.27 (A14), U6.21 (A14), U9.39
/A15: U4.1 (A14), U6.22 (A15), U9.62
/ACK: J1.13, R14.2, U9.57
/ACT: Q2.1 (G), U6.27 (P3)
/ACT_3V3: J5.3 (LED_ACT), Q2.3 (D), R27.2
/BYTE_LATCHED: U6.23 (P7), U9.20
/BYTE_READY_3V3: R17.2, U3.29 (GPIO22), U9.19
/D0: U4.11 (Q0), U5.11 (D0), U6.38 (D0), U9.60
/D1: U4.12 (Q1), U5.12 (D1), U6.37 (D1), U9.1
/D2: U4.13 (Q2), U5.13 (D2), U6.36 (D2), U9.2 (I/O/GTS2)
/D3: U4.15 (Q3), U5.15 (D3), U6.35 (D3), U9.4
/D4: U4.16 (Q4), U5.16 (D4), U6.34 (D4), U9.5 (I/O/GTS1)
/D5: U4.17 (Q5), U5.17 (D5), U6.33 (D5), U9.6
/D6: U4.18 (Q6), U5.18 (D6), U6.32 (D6), U9.7
/D7: U4.19 (Q7), U5.19 (D7), U6.31 (D7), U9.63
/DAV: J1.11, R13.2, U9.49
/DEV: J1.2, R15.2, U9.48
/DEVNUM_3V3: J7.1, R18.2, U9.52
/DIO1: J1.3, R3.2, U9.9
/DIO2: J1.4, R4.2, U9.10
/DIO3: J1.5, R5.2, U9.11
/DIO4: J1.6, R6.2, U9.12
/DIO5: J1.7, R7.2, U9.13
/DIO6: J1.8, R8.2, U9.15 (I/O/GCK1)
/DIO7: J1.9, R9.2, U9.16 (I/O/GCK2)
/DIO8: J1.10, R10.2, U9.17 (I/O/GCK3)
/DS0: U6.25 (P5), U19.14 (D3)
/DS1: U6.24 (P6), U19.3 (D4)
/I2C_SCL: J5.4 (SCL), U3.27 (GPIO21)
/I2C_SDA: J5.5 (SDA), U3.26 (GPIO20)
/MODE_3V3: R19.2, U3.2 (GPIO1), U9.50
/MTR: Q1.3 (D), R26.2, U6.28 (P2)
/MTR_3V3: Q1.2 (S), R25.2, U3.6 (GPIO4)
/PHI0: U3.1 (GPIO0), U6.2 (ϕ0), U9.31
/PHI2: U6.40 (ϕ2), U9.25
/ROT_CLK: J5.7 (UP), JP3.3 (B), R43.1, U19.12 (D1)
/ROT_CLK_PICO: JP3.2 (C), U3.31 (GPIO26_ADC0)
/ROT_DT: J5.8 (DOWN), JP2.3 (B), R42.1, U19.13 (D2)
/ROT_DT_PICO: JP2.2 (C), U3.32 (GPIO27_ADC1)
/ROT_SW: J5.6 (ENTER), JP1.3 (B), R44.1, U19.11 (D0)
/ROT_SW_PICO: JP1.2 (C), U3.34 (GPIO28_ADC2)
/R/~W: U6.39 (R/~W), U9.24
/SD_CD: R28.2, U19.4 (D5), XS1.9 (CD)
/SD_CS: J6.2, U3.22 (GPIO17), XS1.2 (CS/DAT3)
/SD_MISO: J6.5, U3.21 (GPIO16), XS1.7 (DO/DAT0)
/SD_MOSI: J6.3, U3.25 (GPIO19), XS1.3 (DI/CMD)
/SD_SCK: J6.4, U3.24 (GPIO18), XS1.5 (CLK)
/SERIAL_CLK: JP2.1 (A), U19.2 (CP)
/SERIAL_DT: Q4.3 (D), R33.2, U19.9 (Q7)
/SERIAL_DT_3V3: JP1.1 (A), Q4.2 (S), R32.2
/SERIAL_LOAD: JP3.1 (A), U19.1 (~PL)
/STATUS0: J1.12, R11.2, U9.46
/STATUS1: J1.14, R12.2, U9.47
/STP0: Q3.3 (D), R31.2, U6.29 (P1)
/STP0_3V3: Q3.2 (S), R30.2, U3.9 (GPIO6)
/STP1: Q5.3 (D), R36.2, U6.30 (P0)
/STP1_3V3: Q5.2 (S), R35.2, U3.10 (GPIO7)
/SYNC_3V3: R20.2, U3.4 (GPIO2), U9.56
/TCK: J3.3, U9.30 (TCK)
/TDI: J3.4, U9.28 (TDI)
/TDO: J3.5, U9.53 (TDO)
/TMS: J3.2, U9.29 (TMS)
/WPS: Q6.3 (D), R39.2, U6.26 (P4)
/WPS_3V3: Q6.2 (S), R38.2, U3.7 (GPIO5)
/XR/~W: U4.27 (~WE), U9.40
/YB0: U3.11 (GPIO8), U9.22
/YB1: U3.12 (GPIO9), U9.27
/YB2: U3.14 (GPIO10), U9.32
/YB3: U3.15 (GPIO11), U9.33
/YB4: U3.16 (GPIO12), U9.34
/YB5: U3.17 (GPIO13), U9.35
/YB6: U3.19 (GPIO14), U9.36
/YB7: U3.20 (GPIO15), U9.38
/~AEC: R2.2, U6.4 (AEC)
/~IRQ: R21.2, U3.5 (GPIO3), U6.3 (~IRQ)
/~RAMOE: U4.22 (~OE), U9.42
/~RAMSEL: U4.20 (~CS), U9.58
/~RESET: J1.15, R16.2, U6.1 (~RES), U9.64 (I/O/GSR)
/~ROMSEL: U5.20 (~CE), U5.22 (~OE), U9.59
GND: C1.2, C2.2, C3.2, C4.2, C5.2, C6.2, C7.2, C10.2, C11.2, J1.1, J1.16, J2.2, J3.6, J4.2, J4.3, J5.1 (GND), J5.11 (GND), J6.6, J7.2, Q2.2 (S), U3.3 (GND), U3.8 (GND), U3.13 (GND), U3.18 (GND), U3.23 (GND), U3.28 (GND), U3.33 (AGND), U3.38 (GND), U3.42 (GND), U4.14 (GND), U5.14 (GND), U6.20 (VSS), U9.14 (GND), U9.21 (GND), U9.41 (GND), U9.54 (GND), U19.8 (GND), U19.10 (DS), U19.15 (~CE), XS1.1 (DAT2), XS1.6 (GND), XS1.8 (DAT1)
LED_PWR: J5.2 (LED_PWR), R22.1
unnamed: J2.1, R1.2, U5.1 (A15)
unnamed: C11.1, R37.1, XS1.4 (Vdd)
SW4_BACK: J5.9 (BACK), R40.1, U19.5 (D6)
SW5_INSERT: J5.10 (INSERT), R41.1, U19.6 (D7)

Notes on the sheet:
Pico firmware: - encoder, DS0/DS1, SD card change from shift register, SW4, SW5 - GPIO0: output 2MHz system clock - GPIO3: output 100Hz irq
Pullups are necessary on all lines
J1: - switch chooses ROM from 32K half of 27C512 closed = bottom half open = top half
Connection block: if shift register idea fails reconnect Pico to encoder (shift register works fine, so this could be removed)
* Resistor values need to be adjusted according to type of LED installed on front panel. Sensible values for bright LEDs is significantly higher than what is specified.
XR/~{W} is OUTPUT: !((!R/~{W} AND PHI2) typical qualified R/W circuit for 6502 peripherals
ACT_3V3 - converted and inverted ACT (the other side of LED is connected to GND)
23x18mm SD Card module 3.3v
ACT is active low (LED goes to 5V) ACT_3V3 is active high (LED goes to GND)
Power section
NOTE: ACK/DAV naming reversed to keep the TCBM2SD connector intact NOTE: ACK here is controller's ACK output and goes to cable pin 13 (drive's DAV input) NOTE: DAV here is controller's DAV input and goes to cable pin 11 (drive's ACK output) NOTE: MODE==OE from GATE ARRAY
GND - #8 - closed 3V3 - #9 - open
NOTE: DS0/DS1 connected through shift register NOTE: P3 ACT LED goes between ACT and VCC

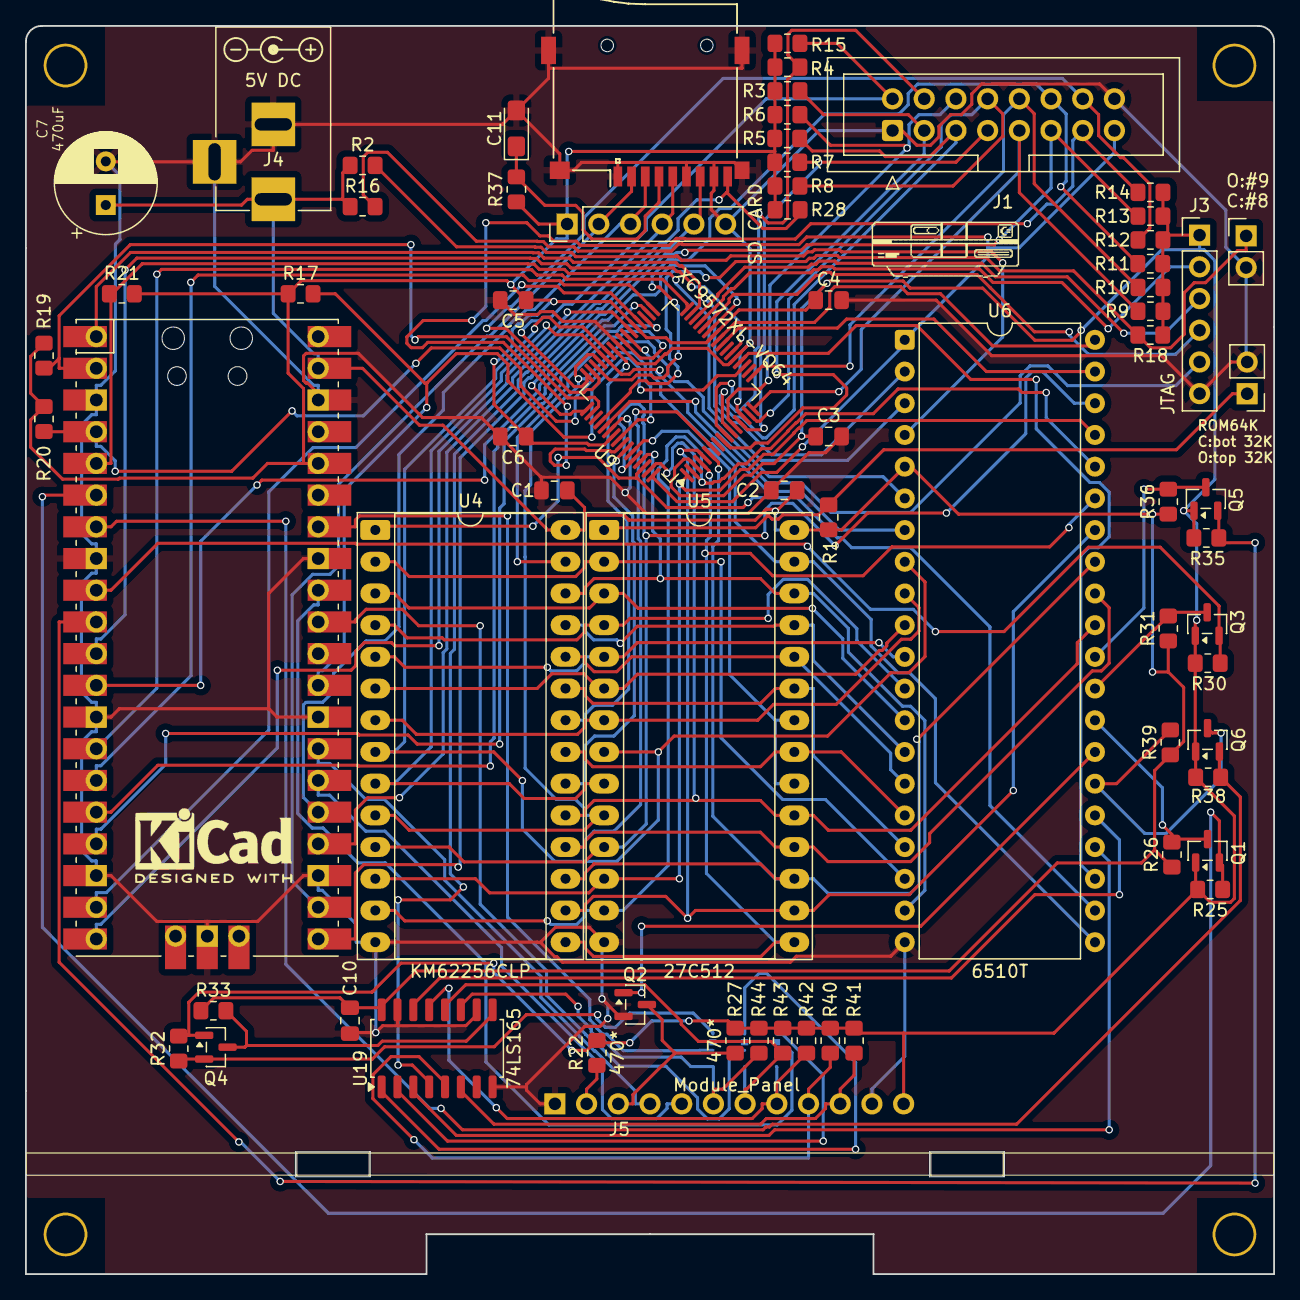
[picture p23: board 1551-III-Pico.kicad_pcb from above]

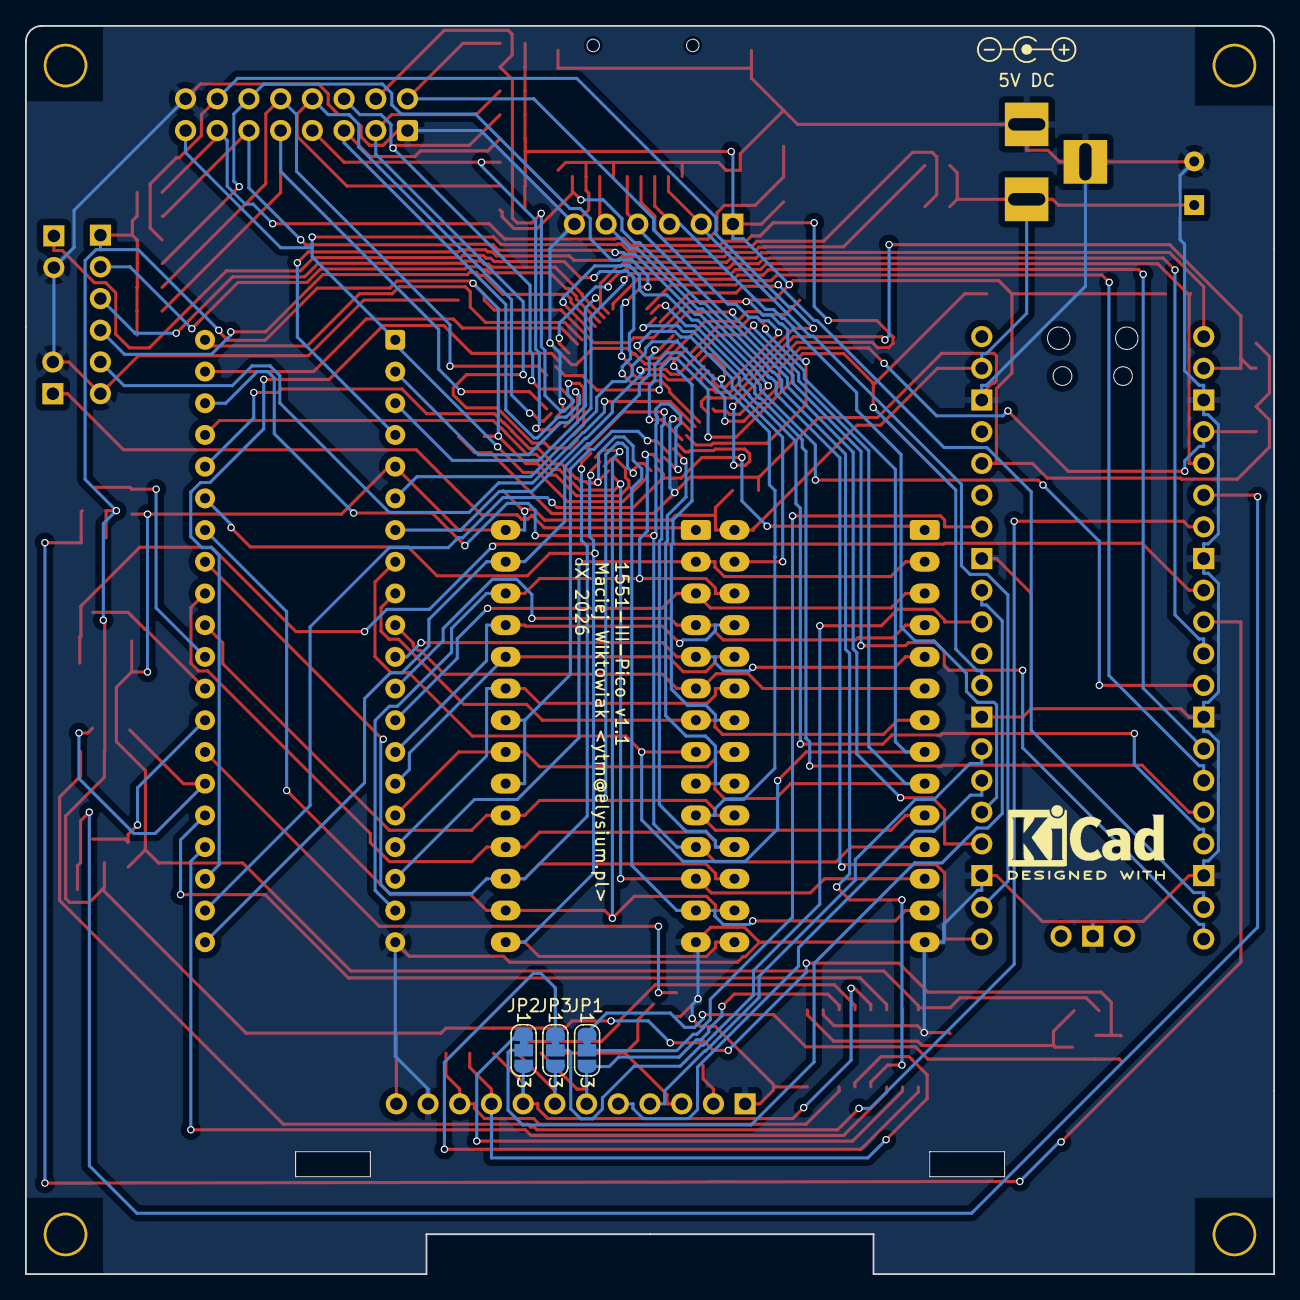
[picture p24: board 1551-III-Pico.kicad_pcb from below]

Board: 2 copper layers, 100.0 x 100.0 mm, 80 parts (4 on the bottom side), 101 nets.

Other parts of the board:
Pi1541-drive: Pi1541-drive
REF1, REF2: KiCad-Logo2_6mm_SilkScreen

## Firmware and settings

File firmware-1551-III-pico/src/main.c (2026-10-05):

/////////////////////////////////////////////////
// 1541-rePico
/////////////////////////////////////////////////
// author: F00K42
// last changed: 2026/07/10
// repo: https://github.com/fook42/1541-rePico
/////////////////////////////////////////////////


#include <stdio.h>
#include "pico/stdlib.h"
#include "hardware/i2c.h"
#include "hardware/timer.h"
#include "hardware/clocks.h"
#include "hardware/sync.h"
#include "hardware/watchdog.h"

#include "pinout.h"
#include "board1551.h"

#define _EXTERN_

#include "version.h"
#include "display.h"
#include "lcd.h"
#include "oled.h"
#include "i2c.h"
#include "gcr.h"
#include "menu.h"
#include "mymenu.h"
#include "gui_constants.h"
#include "settings.h"
#include "globals.h"
#include "rw_routines.h"
#include "menu_image.h"
#include "c64_selector.h"
#include "shift165.h"
#include "dir_list.h"
#if !defined(REPICO1551)
#include "c64_intro.h"
#endif

#include "hw_config.h"
#include "f_util.h"
#include "ff.h"

#include "main.h"


#define START_MESSAGE_TIME 1500
#define SHIFT165_POLL_INTERVAL_US 1000u
#define DENSITY_STABLE_POLLS 3u
#define DISK_CHANGE_HOLD_MS 111u   /* ~333 ms for full eject/insert/final cycle */
#define BYTE_READY_LOW_HOLD_US 1u
#define SD_CD_DEBOUNCE_US 100000u  /* 100 ms — match tcbm2sd PIN_SD_CD_CHANGE_THR_MS */

enum {
    SD_CD_PEND_NONE = 0,
    SD_CD_PEND_EJECTED = 1,
    SD_CD_PEND_INSERTED = 2
};

volatile int16_t rotary_delta = 0;

static volatile uint8_t key_queue[KEY_QUEUE_SIZE];
static volatile uint8_t key_q_head = 0;
static volatile uint8_t key_q_tail = 0;

static uint64_t key2_down_time=0;
static bool key2_long_consumed = false; // long-press already handled while held
uint8_t num_max_tracks;
uint16_t selected_image_nr = 0xFFFF;

// Quadrature gray-code: index = (prev<<2)|curr, value = step direction (0 = invalid/noise)
static const int8_t rotary_transition[16] = {
     0, -1,  1,  0,
     1,  0,  0, -1,
    -1,  0,  0,  1,
     0,  1, -1,  0
};
static uint8_t rotary_prev_ab = 0;
static int8_t rotary_accum = 0;
static uint8_t shift165_prev_value = 0;
static bool shift165_sw4_down = false;
static bool shift165_sw5_down = false;
static bool modal_wait_active = false;
static bool service_lock_navigation = false;
static bool sd_cd_last_present = false;
static uint8_t sd_cd_pending = SD_CD_PEND_NONE;
static bool sd_cd_busy = false;
static uint8_t last_cpu_density_zone = 0xFFu;
static uint8_t cpu_density_candidate = 0xFFu;
static uint8_t cpu_density_stable_polls = 0u;

static void poll_shift_inputs(void);
static void sdcard_handle_cd_pending(void);

static uint8_t speed_zone_for_track(uint8_t track_nr, uint8_t shift_value)
{
    if (settings_get_density_from_cpu())
        return shift165_density_zone_from_byte(shift_value);
    if (track_nr >= MAX_TRACKS)
        track_nr = (uint8_t)(MAX_TRACKS - 1u);
    return d64_track_zone[track_nr];
}

static void density_restart_bytetimer_if_active(void)
{
    if (is_image_mount && send_byte_ready)
    {
        stop_bytetimer();
        start_bytetimer(akt_half_track);
    }
}

static void poll_shift_density_lines(uint8_t value)
{
    if (!settings_get_density_from_cpu())
    {
        last_cpu_density_zone = 0xFFu;
        cpu_density_candidate = 0xFFu;
        cpu_density_stable_polls = 0u;
        return;
    }

    uint8_t zone = shift165_density_zone_from_byte(value);
    if (zone != cpu_density_candidate)
    {
        cpu_density_candidate = zone;
        cpu_density_stable_polls = 1u;
        return;
    }

    if (cpu_density_stable_polls < DENSITY_STABLE_POLLS)
        ++cpu_density_stable_polls;
    if ((cpu_density_stable_polls < DENSITY_STABLE_POLLS) ||
        (zone == last_cpu_density_zone))
        return;

    last_cpu_density_zone = zone;
    density_restart_bytetimer_if_active();
}

static bool rotary_button_held(void)
{
    return 0 == (shift165_last_byte() & (1u << SHIFT165_BIT_ROT_SW));
}

static void filebrowser_insert_image(void);

/* Pi1551-III: 74HCT165 is polled on core 0; stepper stays GPIO-IRQ driven.
 * GCR byte feed uses hardware repeating_timer (~26–32 µs ISR), same core — no core1. */
static void service_tick(void)
{
    poll_shift_inputs();
    check_stepper_signals();
}

static void sleep_ms_service(uint32_t ms)
{
    absolute_time_t until = make_timeout_time_ms(ms);
    while (!time_reached(until))
        service_tick();
}

static bool service_key_dismiss(void)
{
    uint8_t k = get_key_from_buffer();
    return (KEY2_DOWN == k) || (KEY2_TIMEOUT1 == k) || (KEY2_UP == k);
}

static void panel_back(void)
{
    if (service_lock_navigation)
        return;

    switch (current_gui_mode)
    {
    case GUI_MENU_MODE:
        check_menu_events(menu_update(KEY2_TIMEOUT1));
        break;
    case GUI_FILE_BROWSER:
        set_gui_mode(GUI_MENU_MODE);
        break;
    case GUI_INFO_MODE:
        set_gui_mode(GUI_MENU_MODE);
        break;
    case GUI_SELECTOR:
        unmount_image();
        set_gui_mode(GUI_MENU_MODE);
        break;
    default:
        break;
    }
}

static void panel_insert(void)
{
    if (GUI_FILE_BROWSER == current_gui_mode)
    {
        filebrowser_insert_image();
        return;
    }

    FRESULT fr = mount_sdcard();
    display_clear();
    display_home();
    if (FR_OK == fr)
    {
        set_gui_mode(GUI_FILE_BROWSER);
    }
    else
    {
        display_string("f_mount error:");
        display_data(fr + 'A');
        show_fs_error(fr);
        set_gui_mode(GUI_MENU_MODE);
    }
}

// ---------------------------------------------------------------

static void key_push(uint8_t key)
{
    uint8_t next = (uint8_t)((key_q_head + 1u) % KEY_QUEUE_SIZE);
    if (next != key_q_tail)
    {
        key_queue[key_q_head] = key;
        key_q_head = next;
    }
}

static void wait_button_click(void)
{
    modal_wait_active = true;
    for (;;)
    {
        service_tick();

        uint8_t k = get_key_from_buffer();
        if (KEY2_TIMEOUT1 == k)
            break;

        if (KEY2_DOWN == k)
        {
            for (;;)
            {
                service_tick();
                k = get_key_from_buffer();
                if ((KEY2_UP == k) || (KEY2_TIMEOUT1 == k) || (KEY2_TIMEOUT2 == k))
                    break;
            }
            break;
        }
    }
    while (NO_KEY != get_key_from_buffer())
        service_tick();
    modal_wait_active = false;
}

void gpio_callback(uint gpio, uint32_t events)
{
    (void)events;
    if ((GPIO_STP0==gpio) || (GPIO_STP1==gpio))
    {
        static uint64_t last_int;
        // general gpio-ISR .. triggered for STP0 or STP1 change.. no need to detect the cause
        if ((time_us_64()-last_int) > STEP_MIN_TIME)
        {
            stepper_signal_puffer[stepper_signal_w_pos] = ((bool_to_bit(gpio_get(GPIO_STP0))<<1) | (bool_to_bit(gpio_get(GPIO_STP1))));
            stepper_signal_w_pos++;
        }
        last_int = time_us_64();
    }
}

static void poll_shift_inputs(void)
{
    static uint32_t last_poll_us;
    uint32_t now_us = time_us_32();
    if ((uint32_t)(now_us - last_poll_us) < SHIFT165_POLL_INTERVAL_US)
        return;
    last_poll_us = now_us;

    uint8_t value = shift165_poll();
    uint8_t changed = (uint8_t)(value ^ shift165_prev_value);

    if (0 != (changed & ((1u << SHIFT165_BIT_ROT_CLK) | (1u << SHIFT165_BIT_ROT_DT))))
    {
        uint8_t curr = 0;
        if (0 != (value & (1u << SHIFT165_BIT_ROT_CLK)))
            curr |= 2u;
        if (0 != (value & (1u << SHIFT165_BIT_ROT_DT)))
            curr |= 1u;

        int8_t step = rotary_transition[(rotary_prev_ab << 2) | curr];
        rotary_prev_ab = curr;
        if (0 != step)
        {
            step = (int8_t)(-step); /* Pi1551-III front-panel encoder wiring */
            rotary_accum = (int8_t)(rotary_accum + step);
            if (rotary_accum >= ROTARY_DETENT_STEPS)
            {
                rotary_accum = (int8_t)(rotary_accum - ROTARY_DETENT_STEPS);
                rotary_delta++;
            }
            else if (rotary_accum <= -ROTARY_DETENT_STEPS)
            {
                rotary_accum = (int8_t)(rotary_accum + ROTARY_DETENT_STEPS);
                rotary_delta--;
            }
        }
    }

    if (0 != (changed & (1u << SHIFT165_BIT_ROT_SW)))
    {
        static bool button_down = false;
        static uint64_t last_button_us;
        uint64_t now = time_us_64();
        if ((now - last_button_us) >= BUTTON_DEBOUNCE_US)
        {
            bool pressed = (0 == (value & (1u << SHIFT165_BIT_ROT_SW)));
            if (pressed != button_down)
            {
                button_down = pressed;
                last_button_us = now;

                if (pressed)
                {
                    key2_down_time = now;
                    key2_long_consumed = false;
                    key_push(KEY2_DOWN);
                }
                else
                {
                    uint64_t down_time = key2_down_time;
                    if (down_time > now)
                    {
                        down_time -= (now + 1);
                        now = (uint64_t)-1;
                    }

                    if (!key2_long_consumed)
                    {
                        if ((now - down_time) > TIMEOUT2_KEY2)
                            key_push(KEY2_TIMEOUT2);
                        else if ((now - down_time) > TIMEOUT1_KEY2)
                            key_push(KEY2_TIMEOUT1);
                        else
                            key_push(KEY2_UP);
                    }

                    key2_down_time = now;
                }
            }
        }
    }

    if (0 != (changed & (1u << SHIFT165_BIT_SW4_BACK)))
    {
        static uint64_t last_sw4_us;
        uint64_t now = time_us_64();
        bool sw4_pressed = (0 == (value & (1u << SHIFT165_BIT_SW4_BACK)));
        if ((now - last_sw4_us) >= PANEL_BUTTON_DEBOUNCE_US)
        {
            if (sw4_pressed != shift165_sw4_down)
            {
                shift165_sw4_down = sw4_pressed;
                last_sw4_us = now;
                if (sw4_pressed)
                {
                    if (modal_wait_active)
                        key_push(KEY2_TIMEOUT1);
                    else
                        panel_back();
                }
            }
        }
    }

    if (0 != (changed & (1u << SHIFT165_BIT_SW5_INSERT)))
    {
        static uint64_t last_sw5_us;
        uint64_t now = time_us_64();
        bool sw5_pressed = (0 == (value & (1u << SHIFT165_BIT_SW5_INSERT)));
        if ((now - last_sw5_us) >= PANEL_BUTTON_DEBOUNCE_US)
        {
            if (sw5_pressed != shift165_sw5_down)
            {
                shift165_sw5_down = sw5_pressed;
                last_sw5_us = now;
                if (sw5_pressed)
                    panel_insert();
            }
        }
    }

    if (0 != (changed & (1u << SHIFT165_BIT_SD_CD)))
    {
        static uint64_t last_sd_cd_us;
        uint64_t now = time_us_64();
        if ((now - last_sd_cd_us) >= SD_CD_DEBOUNCE_US)
        {
            bool present = (0 == (value & (1u << SHIFT165_BIT_SD_CD)));
            if (present != sd_cd_last_present)
            {
                sd_cd_last_present = present;
                last_sd_cd_us = now;
                /* Queue only — FatFs / image work runs outside service_tick. */
                sd_cd_pending = present ? SD_CD_PEND_INSERTED : SD_CD_PEND_EJECTED;
            }
        }
    }

    poll_shift_density_lines(value);

    shift165_prev_value = value;
}

// ---------------------------------------------------------------

int main()
{
    stdio_init_all();

    if (display_init())
    {
        display_home();
    }

    show_start_message();

    // init input-keys
    init_key_inputs();

    // Stepper Initialisieren
    init_stepper();

    // Motor Initialisieren
    init_motor();

    // Steursignale BYTE_READY, SYNC und SOE Initialisieren
    init_control_signals();

#if REPICO1551
    init_board1551();
#else
    init_soe_gatearray();
    clear_soe_gatearray();
#endif

    init_bytetimer();

    init_writeprot();
    disable_write_protection();

    // setup menus
    menu_init(&main_menu,     main_menu_entrys,     count_of(main_menu_entrys),     LCD_LINE_SIZE, LCD_LINE_COUNT);
    menu_init(&image_menu,    image_menu_entrys,    count_of(image_menu_entrys),    LCD_LINE_SIZE, LCD_LINE_COUNT);
    menu_init(&settings_menu, settings_menu_entrys, count_of(settings_menu_entrys), LCD_LINE_SIZE, LCD_LINE_COUNT);
    menu_init(&info_menu,     info_menu_entrys,     count_of(info_menu_entrys),     LCD_LINE_SIZE, LCD_LINE_COUNT);

    menu_set_root(&main_menu);
    main_menu.lcd_cursor_pos = 1; /* skip ".." — land on Disk Menu */
    settings_boot_load();
    menu_set_entry_var1(&settings_menu, M_REV_ROTARY, settings_get_rotary_reversed() ? 1u : 0u);
    menu_set_entry_var1(&settings_menu, M_DENSITY_CPU, settings_get_density_from_cpu() ? 1u : 0u);
    // ----

    sleep_ms_service(START_MESSAGE_TIME);

    display_clear();
    display_home();

    set_gui_mode(GUI_SELECTOR);

    while (true) {
        service_tick();
        sdcard_handle_cd_pending();
        update_gui();
    }
}
/////////////////////////////////////////////////////////////////////
/////////////////////////////////////////////////////////////////////

static void sdcard_reset_browser_to_root(void)
{
    current_path[0] = '/';
    current_path[1] = 0;
    fb_cursor_pos = 0;
    fb_window_pos = 0;
    fb_dir_entry_count = 0;
}

static void sdcard_on_ejected(void)
{
    /* Stop host-facing GCR feed before tearing down image / FS. */
    stop_bytetimer();
    send_byte_ready = false;
    track_is_written = false; /* discard unsaved track writes — no auto-save */

    if (is_image_mount)
    {
        /* D64/G64/PRG or virtual selector: notify Plus/4 via WPS disk-change. */
        unmount_image();
    }
    else
    {
        close_disk_image(&fd);
    }

    (void)f_closedir(&dir_object);
    (void)umount_sdcard();
    sdcard_reset_browser_to_root();

    display_clear();
    display_home();
    display_string("SD card removed");
    sleep_ms_service(800);
    set_gui_mode(GUI_MENU_MODE);
}

static void sdcard_on_inserted(void)
{
    /* CD closes before contacts fully seat; give the card power/SPI settle time. */
    sleep_ms_service(250);

    FRESULT fr = FR_DISK_ERR;
    for (uint8_t attempt = 0; attempt < 4u; ++attempt)
    {
        fr = mount_sdcard();
        if (FR_OK == fr)
            break;
        sleep_ms_service(200);
    }

    display_clear();
    display_home();
    if (FR_OK == fr)
    {
        sdcard_reset_browser_to_root();
        /* Rebuild selector DATAFILE listing from the new card root. */
        set_gui_mode(GUI_SELECTOR);
    }
    else
    {
        display_string("f_mount error:");
        display_data(fr + 'A');
        show_fs_error(fr);
        set_gui_mode(GUI_MENU_MODE);
    }
}

static void sdcard_handle_cd_pending(void)
{
    uint8_t pending;

    if (sd_cd_busy)
        return;

    pending = sd_cd_pending;
    if (SD_CD_PEND_NONE == pending)
        return;

    sd_cd_pending = SD_CD_PEND_NONE;
    sd_cd_busy = true;

    if (SD_CD_PEND_EJECTED == pending)
        sdcard_on_ejected();
    else if (SD_CD_PEND_INSERTED == pending)
        sdcard_on_inserted();

    sd_cd_busy = false;
}

FRESULT mount_sdcard(void)
{
    /* Do not gate on CD: sockets without a mechanical switch leave /SD_CD
     * pulled high forever. Hotplug still reacts to edges when the switch exists. */
    char mount_path[] = {"/"};
    BYTE mount_option = 1; /* 0=Do not mount (delayed mount), 1=Mount immediately */

    FRESULT fr = f_mount(&fs, mount_path, mount_option);
    // uint8_t retry_count = 3;

    // while ((FR_OK != fr) && (retry_count > 0)) {
    //     retry_count--;
    //     sleep_ms(1000);
    //     fr = f_mount(&fs, mount_path, mount_option);
    // }

    if (FR_OK == fr)
    {
        // Keep previous folder across remounts (Load Image / selector rebuild).
        // Only start at root when path was never set or is no longer valid.
        if (0 == current_path[0])
        {
            strcpy(current_path, mount_path);
        }

        if (FR_OK != f_chdir(current_path))
        {
            strcpy(current_path, mount_path);
            fb_cursor_pos = 0;
            fb_window_pos = 0;
            (void)f_chdir(current_path);
        }

        fb_dir_entry_count = get_dir_entry_count(current_path);

        // Clamp browser cursor if directory shrank since last visit
        if (0 == fb_dir_entry_count)
        {
            fb_cursor_pos = 0;
            fb_window_pos = 0;
        }
        else if ((fb_window_pos + fb_cursor_pos) >= fb_dir_entry_count)
        {
            uint16_t last = fb_dir_entry_count - 1;
            if (last < LCD_LINE_COUNT)
            {
                fb_window_pos = 0;
                fb_cursor_pos = (uint8_t)last;
            }
            else
            {
                fb_window_pos = last - (LCD_LINE_COUNT - 1);
                fb_cursor_pos = LCD_LINE_COUNT - 1;
            }
        }
    }
    return fr;
}


FRESULT umount_sdcard(void)
{
    char mount_path[] = {""};
    FRESULT fr = f_unmount(mount_path);

    /* FatFs unmount alone leaves the SPI card layer "initialized". On the next
     * f_mount, sd_card_spi_init() then skips sd_init_medium() and sector I/O
     * fails with FR_DISK_ERR. Force re-init (same as no-OS-FatFS command_line). */
    sd_card_t *card = sd_get_by_num(0);
    if (NULL != card)
    {
        card->state.m_Status |= STA_NOINIT;
        card->state.card_type = SDCARD_NONE;
        card->state.sectors = 0;
    }

    return fr;
}

void show_fs_error(FRESULT error_code)
{
    const char *error_txt = FRESULT_str(error_code);
    size_t err_str_len = strlen(error_txt);
    uint8_t err_str_offset = 0;
    bool dismissed = false;

    modal_wait_active = true;
    while (!dismissed && ((err_str_offset + 15u) < err_str_len))
    {
        display_setcursor(0, 1);
        display_print(error_txt, err_str_offset++, 16);
        absolute_time_t until = make_timeout_time_ms(333);
        while (!time_reached(until))
        {
            if (service_key_dismiss())
            {
                dismissed = true;
                break;
            }
            service_tick();
        }
    }
    while (!dismissed)
    {
        if (service_key_dismiss())
            dismissed = true;
        else
            service_tick();
    }
    while (NO_KEY != get_key_from_buffer())
        service_tick();
    modal_wait_active = false;
}
/////////////////////////////////////////////////////////////////////


int64_t steppertimer_callback(alarm_id_t id, void *user_data)
{
    send_byte_ready = false;
    stop_bytetimer();

    // neue track Geschwindigkeit setzen -> timer restart
    akt_track_pos = 0;

    akt_half_track = selected_track&0x7E;

    start_bytetimer(akt_half_track);
    send_byte_ready = true;
    return 0;
}


void start_stepper_timer(void)
{
    if (stepper_alarm) { cancel_alarm(stepper_alarm); }
    stepper_alarm = add_alarm_in_ms(STEPPER_DELAY_TIME, steppertimer_callback, NULL, false);
}

/////////////////////////////////////////////////////////////////////

void check_stepper_signals(void)
{
    // Auf Steppermotor aktivität prüfen
    // und auswerten
    if(stepper_signal_r_pos != stepper_signal_w_pos)    // Prüfen ob sich was neues im Ringpuffer für die Steppersignale befindet
    {
        uint8_t stepper = stepper_signal_puffer[(stepper_signal_r_pos+255)&0xFF]<<2;
        stepper |= stepper_signal_puffer[stepper_signal_r_pos];
        stepper_signal_r_pos++;

        switch(stepper)
        {
            case 0b00000011:
            case 0b00000100:
            case 0b00001001:
            case 0b00001110:
                {
                    // DEC
                    stepper_dec();
                    start_stepper_timer();
                }
                break;

            case 0b00000001:
            case 0b00000110:
            case 0b00001011:
            case 0b00001100:
                {
                    // INC
                    stepper_inc();
                    start_stepper_timer();
                }
                break;

            default:
                break;
        }
    }
}

/////////////////////////////////////////////////////////////////////

void init_key_inputs(void)
{
    shift165_init();

    shift165_prev_value = shift165_last_byte();
    rotary_prev_ab = 0;
    if (0 != (shift165_prev_value & (1u << SHIFT165_BIT_ROT_CLK)))
        rotary_prev_ab |= 2u;
    if (0 != (shift165_prev_value & (1u << SHIFT165_BIT_ROT_DT)))
        rotary_prev_ab |= 1u;
    rotary_accum = 0;
    rotary_delta = 0;
    shift165_sw4_down = (0 == (shift165_prev_value & (1u << SHIFT165_BIT_SW4_BACK)));
    shift165_sw5_down = (0 == (shift165_prev_value & (1u << SHIFT165_BIT_SW5_INSERT)));
    sd_cd_last_present = (0 == (shift165_prev_value & (1u << SHIFT165_BIT_SD_CD)));
    sd_cd_pending = SD_CD_PEND_NONE;
    last_cpu_density_zone = shift165_density_zone_from_byte(shift165_prev_value);
}

uint8_t get_key_from_buffer(void)
{
    uint32_t ints = save_and_disable_interrupts();
    int16_t delta = rotary_delta;
    if (delta != 0)
    {
        if (delta < 0)
            rotary_delta = (int16_t)(delta + 1);
        else
            rotary_delta = (int16_t)(delta - 1);
        restore_interrupts(ints);
        if (settings_get_rotary_reversed())
            return (delta < 0) ? KEY1_DOWN : KEY0_DOWN;
        return (delta < 0) ? KEY0_DOWN : KEY1_DOWN;
    }

    if (key_q_tail != key_q_head)
    {
        uint8_t val = key_queue[key_q_tail];
        key_q_tail = (uint8_t)((key_q_tail + 1u) % KEY_QUEUE_SIZE);
        restore_interrupts(ints);
        return val;
    }
    restore_interrupts(ints);
    return NO_KEY;
}
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

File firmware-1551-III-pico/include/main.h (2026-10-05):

/**********************************
 * header - main routines, defines, variables
 *
 * Author: F00K42
 * Last change: 2026/02/16
***********************************/
#include "hw_config.h"
#include "f_util.h"
#include "ff.h"
#include "globals.h"
#include "board_config.h"

// functions
FRESULT mount_sdcard(void);
FRESULT umount_sdcard(void);
void show_fs_error(FRESULT error_code);

void check_stepper_signals(void);
void check_motor_signal(void);

void init_key_inputs(void);
uint8_t get_key_from_buffer(void);
void show_longpress(void);
void update_gui(void);
void check_menu_events(const uint16_t menu_event);
void set_gui_mode(const uint8_t gui_mode);
void filebrowser_update(uint8_t key_code);
void filebrowser_refresh(void);

void infomode_update(void);

void handle_selector_image(void);
bool insert_menu_image(char* menu_path);

uint16_t get_dir_entry_count(const char* entrycount_path);

void show_start_message(void);
void show_sdcard_info_message(void);

void init_stepper(void);
void stepper_inc(void);
void stepper_dec(void);
void init_motor(void);
void init_control_signals(void);
#if REPICO1551
void init_board1551(void);
#else
void init_soe_gatearray(void);
#endif

uint8_t open_dir_entry(FILINFO od_file_entry);

uint8_t open_disk_image(FIL* fd, FILINFO *file_entry);
void close_disk_image(FIL* fd);
void unmount_image(void);

void init_writeprot(void);
void send_disk_change(bool simulate_eject, bool simulate_insert);

bool repeating_timer_callback(__unused struct repeating_timer *t);
void init_bytetimer(void);
void start_bytetimer(uint8_t half_track);
void stop_bytetimer(void);

int64_t steppertimer_callback(alarm_id_t id, void *user_data);
void start_stepper_timer(void);

/////////////
#define set_byte_ready()    gpio_set_dir(GPIO_BRDY,GPIO_IN)    // HiZ
#define clear_byte_ready()  {gpio_set_dir(GPIO_BRDY,GPIO_OUT);gpio_put(GPIO_BRDY,false);}   // auf Ground ziehen

#if REPICO1551
#define get_soe_status()    (true)
#else
#define get_soe_status()    gpio_get(GPIO_SOE)
#define set_soe_gatearray()     gpio_put(GPIO_SOE_GA,true)
#define clear_soe_gatearray()   gpio_put(GPIO_SOE_GA,false)
#endif

#define get_so_status()     gpio_get(GPIO_OE)

// WPS at CPU bit4: 0 = write-protected, 1 = writable (1551 ROM AND #$10 / BNE = not protected).
// 1541: Pico feeds board 74LS04 → invert at GPIO (HiZ → protected at VIA).
// 1551-rePico: GPIO5 → BSS138 → CPU WPS (no inverter). MOSFET can only pull WPS low;
//   high is R10 (+ Pico driving WPS_3V3 high so the FET is firmly off). Never push 5V.
#if REPICO1551
#define clear_wps()         {gpio_set_dir(GPIO_WPS,GPIO_OUT);gpio_put(GPIO_WPS,false);}  // FET on  → WPS=0
#define set_wps()           {gpio_set_dir(GPIO_WPS,GPIO_OUT);gpio_put(GPIO_WPS,true);}   // FET off → WPS=1 via R10
#else
#define clear_wps()          gpio_set_dir(GPIO_WPS,GPIO_IN)    // HiZ → inverter → protected
#define set_wps()           {gpio_set_dir(GPIO_WPS,GPIO_OUT);gpio_put(GPIO_WPS,false);}   // low → inverter → writable
#endif

#define get_motor_status()  gpio_get(GPIO_MTR)

#define set_sync()          gpio_put(GPIO_SYNC,true)
#define clear_sync()        gpio_put(GPIO_SYNC,false)

#define out_gcr_byte(gcr_byte)  gpio_put_masked(PAPORT_MASK,gcr_byte<<GPIO_PAPORT)
#define in_gcr_byte()       (gpio_get_all()&PAPORT_MASK)>>GPIO_PAPORT

#define enable_write_protection()   {clear_wps();floppy_wp=true;}
#define disable_write_protection()  {set_wps();floppy_wp=false;}


// Filesystem-variables:
FATFS       fs;             // filesystem handle - only created once
DIR         dir_object;
FIL         fd;             // file descriptor for every open file
FILINFO     fb_dir_entry[DISPLAY_LINE_MAX];
//
//
// Button bounce filter (us). Rotary uses a quadrature state machine (no ms block).
#define BUTTON_DEBOUNCE_US      (30000u)
#define PANEL_BUTTON_DEBOUNCE_US (50000u)
#define KEY_QUEUE_SIZE          (8)
#if REPICO1551
/* Pi1551-III panel encoder: 2 valid quadrature edges per detent */
#define ROTARY_DETENT_STEPS     (2)
#else
#define ROTARY_DETENT_STEPS     (4)
#endif
// timer_t key_longpress_timer;

volatile uint16_t akt_track_pos = 0;

uint8_t selected_track;     // this holds the selected tracknumber
volatile uint8_t akt_half_track;     // this will be the one to be transfered
uint8_t old_half_track;

// timer definition

struct repeating_timer bytetimer;


char image_filename[256]; //Maximal 256 Zeichen
char current_path[512];

uint8_t current_gui_mode;

uint8_t gui_current_line_offset;         // >0 dann ist der Name länger als die maximale Anzeigelaenge
uint8_t gui_line_scroll_pos;             // Kann zwischen 0 und fb_current_line_offset liegen
uint8_t gui_line_scroll_direction;       // Richtung des Scrollings
uint8_t gui_line_scroll_end_begin_wait;
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

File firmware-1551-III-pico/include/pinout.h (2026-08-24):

/**********************************
 * header - pinout assignment for Pico2 to baseboard
 *
 * Author: F00K42
 * Last change: 2026/02/15
***********************************/
#include "hardware/spi.h"

// Gate-array / 1551 bus connection (GPIO numbers shared across targets)
// 1551: GPIO0=PHI0(PWM), GPIO1=MODE, GPIO3=DEVNUM(static) or IRQ PWM (see board1551.h), GPIO8..15=YB0..7
#define GPIO_SOE    0
#define GPIO_OE     1
#define GPIO_SYNC   2
#define GPIO_SOE_GA 3
#define GPIO_MTR    4
#define GPIO_WPS    5
#define GPIO_STP0   6
#define GPIO_STP1   7

#define GPIO_PAPORT 8  //defines the first bit of 8
#define PAPORT_MASK (uint32_t)(0xFF<<GPIO_PAPORT)
/*
#define GPIO_PA0    8
#define GPIO_PA1    9
#define GPIO_PA2    10
#define GPIO_PA3    11
#define GPIO_PA4    12
#define GPIO_PA5    13
#define GPIO_PA6    14
#define GPIO_PA7    15
*/

// SPI defines
#define SPI_PORT    spi0
#define SPI_MISO    16
#define SPI_CS      17
#define SPI_SCK     18
#define SPI_MOSI    19

// I2C defines
#define I2C_PORT    i2c0
#define I2C_SDA     20
#define I2C_SCL     21

// Pi1551-III front panel via 74HCT165 (JP1..JP3 bridged 1-2)
#define GPIO_SERIAL_LOAD  26  // /PL
#define GPIO_SERIAL_CLK   27  // CP
#define GPIO_SERIAL_DT    28  // Q7

#define GPIO_BRDY   22

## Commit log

2026-07-16 copy hardware to hardware1551
    [1551-rePico.kicad_pcb, 1551-rePico.kicad_sch, bss138.kicad_sch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]
2026-07-16 1551 version with Fake6523_hw_checked by ZXByteman
    [1551-rePico.kicad_sch, bss138.kicad_sch]
2026-07-16 updates and cleanups
    [1551-rePico.kicad_sch, bss138.kicad_sch, via6522_sockel.kicad_sch]
2026-07-16 drop SOE, add pullups, drive WPS directly to CPU pin (open drain)
    [1551-rePico.kicad_sch]
2026-07-16 import Pi1551-III as PCB template for 1551-III-Pico, to reuse front panel
    [1551-III-Pico.kicad_pcb, 1551-III-Pico.kicad_sch]
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2026-07-16 1551 board that might actually work
    [1551-III-Pico.kicad_pcb, 1551-III-Pico.kicad_sch]
2026-07-16 board for 1551 with correct dimensions and spacing between CPU and TPI, routed
    [1551-rePico.dsn, 1551-rePico.kicad_pcb, 1551-rePico.kicad_sch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]
2026-07-16 updates/fixes and review what to do after
    [1551-rePico.kicad_pcb, 1551-rePico.kicad_sch]
2026-07-16 jumpers for future GPIO0/GPIO3 experiments
    [1551-rePico.dsn, 1551-rePico.kicad_pcb, 1551-rePico.kicad_sch]
2026-07-16 version 1.0 for production
    [1551-rePico-B_Cu.gbl, 1551-rePico-B_Mask.gbs, 1551-rePico-B_Paste.gbp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]
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2026-07-16 lock pins to mainboard footprints, they are perfectly aligned
    [1551-rePico.kicad_pcb]
2026-07-16 disconnect WPS from mainboard WPS becuase it's an output of U8 (pin2) that will keep it low with no mechanism present
    [1551-rePico-B_Cu.gbl, 1551-rePico-B_Mask.gbs, 1551-rePico-B_Paste.gbp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]
2026-07-16 correct WPS polarization for 1551 and longer delay when switching disks
    [main.c, main.h]
2026-07-17 remove BYTE_LATCHED connection to the board, keep it only between CPU and CPLD
    [1551-rePico-B_Cu.gbl, 1551-rePico-B_Mask.gbs, 1551-rePico-B_Paste.gbp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]
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2026-07-17 missed saving PCB design after removing BYTE_LATCHED connection to the mainboard
    [1551-rePico.kicad_pcb]
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2026-07-18 correct next-image action via button longpress
    [main.c]
2026-07-18 zone0 debug options in settings, option to reverse encoder direction, load nad save to flash
    [main.c]
2026-07-18 correct sd info menu option, improve UX
    [main.c]
2026-07-18 confirm how LED works (ACT=0 is ON)
    [1551-rePico.kicad_sch]
2026-07-18 generate R/W signal for TPI and RAM inside CPLD, drop use of XR/W from gate array; pass XR/W for RAM through RESET_3V3 (easily available on unused JP1)
    [Fake6523.ucf]
2026-07-18 gate array independence, confirmed that we can do everything on pico-1551-III board
2026-08-01 pico1551-iii schematic revised according to pico1551 discoveries
    [1551-III-Pico.kicad_sch]
2026-08-08 mos6502 replacer integrated
    [1551-III-Pico.kicad_pcb, 1551-III-Pico.kicad_sch]
2026-08-11 all the footprints from other projects
    [1551-III-Pico.kicad_pcb, 1551-III-Pico.kicad_sch]
2026-08-11 correct pico footprint
2026-08-11 part placement and routing test
    [1551-III-Pico.kicad_pcb, 1551-III-Pico.kicad_sch]
2026-08-12 project updated and routed: IRQ with pullup, correct 3V3 net, correct inputs for '139
    [1551-III-Pico.kicad_pcb, 1551-III-Pico.kicad_sch]
2026-08-12 remove '139 and '00 logic to embed it into CPLD, routed final version
    [1551-III-Pico.kicad_pcb, 1551-III-Pico.kicad_sch]
2026-08-13 rework PCB to be sure that MOS Replacer daughterboard will fit
    [1551-III-Pico.kicad_pcb]
2026-08-16 finalized revision and files for manufacturing
    [1551-III-Pico-B_Cu.gbl, 1551-III-Pico-B_Mask.gbs, 1551-III-Pico-B_Paste.gbp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]
2026-08-24 Add firmware-1551-III-pico as a copy of firmware for Pi1551-III hardware.
    Keeps the original firmware tree for 1551-rePico/hdl while the III front-panel work proceeds in a separate tree.
2026-08-24 Add SH1106 OLED and 74HCT165 front-panel support to firmware-1551-III-pico.
    Polls the shift register for encoder, SD card detect, and SW4/SW5 buttons while using SH1106 column offset and a dedicated 1551-III-Pico build target.
2026-08-24 Stop tracking duplicate submodules and build output in firmware-1551-III-pico.
    Reuse firmware/no-OS-FatFS and firmware/buildtools/bitfire at build time; gitignore build artifacts and generated headers like the main firmware tree.
2026-08-24 Fix SH1106 OLED rendering and expose 8-line display geometry.
    Remove SSD1306 page mirroring that duplicated the UI on SH1106 panels, drive
    brightness via contrast instead, and set runtime row/column counts for the
    128x64 OLED versus the 16x4 LCD.
    [display.c, oled.c]
2026-08-24 Add sorted directory cache for browser and selector menus.
    List folders with .. first in subdirectories, then directories A-Z and
    files A-Z case-insensitively, and use the cache in the file browser,
    load-next-image, and selector rebuild paths.
2026-08-24 Add optional density-from-CPU setting persisted in flash.
    Expose a "Dens CPU" menu toggle that selects whether byte-timer speed
    zones follow emulated DS0/DS1 lines instead of track number alone.
2026-08-24 Integrate Pi1551-III front-panel polling, buttons, and navigation.
    Keep shift-register and stepper polling alive during blocking SD and modal
    waits via service_tick, map SW4 BACK and SW5 INSERT, optionally drive byte-
    timer zones from DS0/DS1, and improve roster browsing with rotary prev/next,
    INSERT-in-browser, tuned encoder detents, key draining, and partial file
    browser redraws.
2026-08-31 Remove zone0 settings and use fixed 1541 speed-zone tables.
    Drop Z0 timer/gap menu, flash fields, and runtime overlay on
    bytetimer_values/d64_sector_gap. Pi1551-III now keeps upstream
    1541-rePico timing constants (26/12/… gaps) as compile-time data.
2026-08-31 Drop zone0 timer/gap handling from Pi1551-III main menu wiring.
    Remove settings menu cases and refresh paths that referenced the deleted
    Z0 timer and Z0 gap entries.
2026-08-31 Debounce CPU density lines and throttle shift165 polling.
    Require three stable DS0/DS1 samples before switching byte-timer speed
    zone when Dens CPU is enabled, poll the 74HCT165 at most every 1 ms,
    and reset density state cleanly when the option is turned off.
    [main.c]
2026-08-31 Simulate optical write-protect on virtual disk insert and eject.
    Drive the WPS line through a ~333 ms eject/insert sequence so 1551 ROM
    sees notch-open on eject, blocked while the disk enters, then the final
    protected or writable state. ReInsert runs the full swap cycle.
    [main.c, main.h]
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2026-09-12 ACT LED corrections after tests: move LED current limiter (R23, 470R) to R27 position (former 3K3 pullup)
    [1551-III-Pico-B_Cu.gbl, 1551-III-Pico-B_Mask.gbs, 1551-III-Pico-B_Paste.gbp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]
2026-10-05 Document SD card switch hotplug design and implementation plan.
    Captures tcbm2sd-aligned CD handling, eject-while-mounted behaviour, and STA_NOINIT remount requirements before the firmware change.
2026-10-05 Add SD card-detect hotplug: eject/remount and rebuild selector.
    Poll debounced /SD_CD via 74HCT165, unmount images on eject (host disk-change), force STA_NOINIT so remount re-inits SPI, and rebuild the Load Selector list on insert.
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2026-10-05 Skip modal hang when selector mount fails at boot.
    With SD hotplug available, boot without a card shows a brief message and falls back to the menu instead of waiting for a keypress on f_mount error.
    [main.c, main.h]
2026-10-05 Archive early 1551 daughterboard experiment under experimental/.
    Move hardware1551, hdl, and the 1541-derived firmware out of the release tree; keep FatFs at the repo root for firmware-1551-III-pico; document archival intent and point build/CI at the III firmware.
    [1551-rePico-B_Cu.gbl, 1551-rePico-B_Mask.gbs, 1551-rePico-B_Paste.gbp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]
2026-10-05 Remove upstream 1541-rePico KiCad hardware tree.
    That board is not part of the 1551-III product; supported hardware lives in hardware-1551-III-Pico/.
    [1541-rePico.kicad_pcb, 1541-rePico.kicad_sch, bss138.kicad_sch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]
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2026-10-05 Document Pi1551-III stack reuse and Pico mainboard swap in README.
    Clarify that panel/covers come from Pi1551-III; hardware-1551-III-Pico replaces only Module-rotated.
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2026-10-05 Document hardware fab pack, DOS ROMs, and Parobek Load Selector TODO.
    Replace the leftover Pi1551-III board README, track Pico_2b production zip instead of Pico_2, add roms/ with 1551-RAMBOard images, and point the top-level README at BOM/Gerbers/ROM/Parobek notes.
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2026-10-05 README: add a short project-evolution narrative.
    Explain the 1541-rePico inheritance, daughterboard bring-up, and what is new on 1551-III-Pico without maintaining a changelog.
2026-10-05 Tighten README coverage across the release tree.
    Fix historical doc/tools links, add stub READMEs for firmware and HDL, note tools/ in the layout, and clarify experimental fab notes are daughterboard-only.
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2026-10-05 Fix CI GenSelector path and init TinyUSB in the Pico SDK.
    PROJECT_INCLUDE was unset so c64_selector.h was written to /, and the CI SDK clone only pulled mbedtls.
